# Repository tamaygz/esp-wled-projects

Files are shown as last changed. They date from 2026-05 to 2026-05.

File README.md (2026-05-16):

# esp-wled-projects

> DIY LED lighting projects powered by **WLED** on ESP32 / ESP8266 — fully integrated with Home Assistant.

This repository has two layers:

- the **meta main folder**, which contains the reusable project system
- the **project folders**, which contain individual lighting builds

The meta main folder is there to make new project creation repeatable instead of ad-hoc. It contains the shared `_template/` skeleton, Copilot agents and instructions under `.github/` and `AGENTS.md`, the parts register in [tools/parts-register/parts.json](./tools/parts-register/parts.json), shared generators in [tools/](./tools/), and the integration conventions for WLED, Home Assistant, diagrams, and enclosures. Together, those pieces are meant to help a project consumer move from idea to implementation faster: reuse known parts and pinouts, scaffold the right files, generate diagrams and enclosures consistently, and keep firmware, hardware, and Home Assistant artifacts aligned.

Each actual project folder is then a self-contained build with its own firmware config, wiring docs, power budget, 3D models, and generated diagrams.

## Meta Layer At A Glance

If you want to create a new project from this repo, the root-level meta layer is the part that helps you.

| Meta asset | What it contains | How it helps when creating a new project |
|---|---|---|
| [_template/](./_template/) | Base folder skeleton | Gives every new project the same starting structure and required files |
| [tools/parts-register/parts.json](./tools/parts-register/parts.json) | Shared parts registry | Reuses known dimensions, electrical facts, and board pinouts instead of re-researching them |
| [tools/](./tools/) | Shared generators and helpers | Produces diagrams, renders enclosures, and uploads SPIFFS assets consistently |
| [.github/instructions/](./.github/instructions/) | Scoped Copilot rules | Keeps edits to firmware, hardware, diagrams, and new-project docs aligned with repo conventions |
| [.github/prompts/](./.github/prompts/) | Reusable slash-command workflows | Speeds up scaffolding, diagram generation, and enclosure generation |
| [.github/agents/](./.github/agents/) | Planner, reviewer, and hardware-debug agents | Guides planning, real-build debugging, and final coherence checks |
| [AGENTS.md](./AGENTS.md) and [.github/copilot-instructions.md](./.github/copilot-instructions.md) | Always-on repo guidance | Explains how the meta layer is supposed to be used and what rules always apply |

### How The Meta Layer Helps

1. Start from `_template/` instead of inventing a structure from scratch.
2. Use the parts register before looking up dimensions, pinouts, or PSU data again.
3. Let the planner prompt or agent drive the first pass when requirements are still forming.
4. Generate diagrams and enclosure artifacts from shared tools so outputs stay consistent across projects.
5. Use the hardware-debug agent when a physical build fails and the fault is still unclear.
6. Run the reviewer step before considering a new project scaffold or meta change complete.

---

## Ideal Workflow — New Project

### 1 · Plan

Use the **ESP/WLED Project Planner** agent in Copilot chat, or work through these steps manually:

| Step | What to do |
|---|---|
| Concept | Decide installation type, LED run length, colour capability, sound-reactive? |
| LED strip | Pick chipset (SK6812 RGBW, WS2812B RGB, WS2811 12 V) based on colour needs and run length |
| Power budget | `N_leds × 20 mA × channels` + 20 % headroom → select PSU |
| ESP32 | ESP32-WROOM-32 for most projects; ESP32-S3 for native USB / >3 buses |
| GPIO plan | Assign data lines to GPIO 16 / 17 / 18; level shifter required (3.3 V → 5 V) |
| HA effects | Decide if [hacs-wledext-effects](https://github.com/tamaygz/hacs-wledext-effects) is needed for state-driven effects |

Start with [tools/parts-register/parts.json](./tools/parts-register/parts.json) during planning so you can reuse known board, LED strip, PSU, connector, and cutout data before searching the web again.

### 2 · Scaffold

```bash
cp -r _template/ my-project/
```

Then fill in order:

1. `specs.md` — concept, requirements, acceptance criteria, **Home Assistant** section
2. `hardware/bom/bom.md` — parts list + current budget
3. `hardware/wiring/WIRING.md` — GPIO assignments, power rails, injection points
4. `gen_diagrams_config.py` — copy from `reefs/`, update values
5. `firmware/cfg.json` — set unique mDNS hostname: `"id": {"mdns": "my-project"}`

Or use the **`/new-project`** prompt in Copilot chat to scaffold automatically.

### 2.5 · Review The Scaffold

When the scaffold or meta-layer update is in place, switch to the **ESP/WLED Project Reviewer** agent or use the planner's review handoff. The review step checks repo-instruction coherence, missing files, register-backed hardware facts, and whether user-facing docs match the current project state.

### 3 · Generate Diagrams

```bash
python tools/gen_diagrams.py my-project       # all 4 types
python tools/gen_diagrams.py my-project --type concept   # real-world views only
```

Four diagram types are produced:

| Type | Output | What it shows |
|---|---|---|
| `blocks` | `concept-system.png` | System block: PSU → ESP32 → level shifter → LED strips → HA |
| `concept` | `concept-side-view.png` · `concept-top-view.png` | Real-world: wall cross-section + floor-plan with lamp positions |
| `wiring` | `wiring-physical.svg` | Color-coded physical wiring with pin labels |
| `schematic` | `schematic-*.png` | Electrical schematics (level shifter + power) |

All outputs land in `my-project/docs/` — never hand-edit them. Or use the **`/gen-diagrams`** prompt in Copilot chat.

### 4 · Generate Enclosure

Use the **`/gen-enclosure`** prompt in Copilot chat, or run the helper directly after the SCAD is in place:

```powershell
pwsh tools/render_enclosure.ps1 -Project my-project -ScadName my-project-enclosure
```

Produces `my-project/mechanical/enclosure/`:

- `my-project-base.stl`, `my-project-lid.stl` — print-ready
- `my-project-{base,lid}-{iso,top}.png` — 4 preview PNGs, committed alongside the STLs

Lid closure defaults to **snap-on** (no screws). Source of truth: [.github/skills/enclosure-gen/SKILL.md](.github/skills/enclosure-gen/SKILL.md).

### 5 · Build & Flash

```bash
# Inside the WLED repo, with firmware/platformio_override.ini alongside platformio.ini:
pio run -e esp32dev_my-project -t upload
```

First boot → connect to `wled-ap` hotspot → configure WiFi credentials via Captive Portal.

### 6 · Connect to Home Assistant

1. Enable native WLED integration: **Settings → Devices & Services → Add → WLED**
2. Device auto-discovers via mDNS (`my-project.local`)
3. Verify light entities appear and on/off / brightness / colour work
4. (Optional) Install [hacs-wledext-effects](https://github.com/tamaygz/hacs-wledext-effects) for state-driven effects

### 7 · Export & Commit

```bash
# Export config from WLED web UI → backup
# Place files in firmware/cfg.json and design/effects/presets.json
git add .
git commit -m "feat(my-project): initial project setup"
```

---

## Project Folder Convention

```
[project]/
├── firmware/               # platformio_override.ini, cfg.json, presets.json
├── hardware/
│   ├── wiring/             # KiCad schematics, wiring notes, PDFs
│   ├── pcb/                # KiCad PCB files, Gerbers
│   └── bom/                # bom.md — parts list + power budget
├── mechanical/
│   └── enclosure/          # YAPP_Box SCAD + STLs + preview PNGs + print settings
├── design/
│   ├── led-map/            # 2D pixel maps, segment plans
│   └── effects/            # WLED presets.json, palettes, ha-automations.yaml
├── docs/                   # Auto-generated diagrams (PNG/SVG) — do not hand-edit
├── gen_diagrams.py         # Diagram script — imports from tools/diagram_gen
├── gen_diagrams_config.py  # DIAGRAM_CONFIG dict for this project
└── specs.md                # Project PRD / spec sheet
```

See [_template/](./_template/) for a ready-to-copy skeleton.

---

## AI Agent Support

This repo is configured for GitHub Copilot (VS Code Insiders) and GitHub cloud agents.

| Customization | What it does |
|---|---|
| Always-on instructions | `.github/copilot-instructions.md` — full project conventions |
| `AGENTS.md` | Root agent guidance shared across coding agents |
| `firmware.instructions.md` | Auto-loaded when editing `platformio_override.ini`, `cfg.json` |
| `hardware.instructions.md` | Auto-loaded when editing wiring / BOM / PCB files |
| `new-project.instructions.md` | Auto-loaded when editing `specs.md` or `_template/` |
| `diagram-gen.instructions.md` | Auto-loaded when editing diagram generators or `docs/` |
| `/new-project` prompt | Scaffolds a full project folder from `_template/` |
| `/gen-diagrams` prompt | Runs `tools/gen_diagrams.py` with validation |
| `/gen-enclosure` prompt | Generates YAPP_Box SCAD + renders STLs and preview PNGs |
| `ESP/WLED Project Planner` custom agent | Guided planning: requirements → LED → power → GPIO → HA → scaffold |
| `ESP/WLED Project Reviewer` custom agent | Reviews scaffold/meta coherence, upgrades docs, and checks current customization conventions |
| `ESP/WLED Realworld Hardware Debug` custom agent | Step-by-step real build triage: captures actual hardware, checks wiring/power/config assumptions, compares against project definitions, and guides the next diagnostic step |
| `enclosure-gen` skill | Reusable enclosure reference and YAPP_Box workflow support |
| `.github/hooks/README.md` | Documents the repo hook policy and recommended first deterministic hook use cases |

### How To Use The Agents

- Use **ESP/WLED Project Planner** when you are starting a new build or the requirements are still vague. Give it the project idea, LED goals, installation constraints, and Home Assistant expectations.
- Use **ESP/WLED Project Reviewer** after scaffolding or broad meta changes. It is the cleanup and coherence pass that checks missing files, instruction drift, register-backed facts, and doc completeness.
- Use **ESP/WLED Realworld Hardware Debug** when a physical setup is not working and you do not yet know whether the problem is power, wiring, GPIO choice, firmware config, part substitution, or Home Assistant. Start it with the project name and a symptom such as `reefs flickers`, `curtaincinemalights no Wi-Fi`, or `something isn't working`.
- Let the agents hand off where appropriate: planner for build definition, hardware-debug for real-world triage, reviewer for final doc and meta alignment.

### Which Doc To Read

| If you need to understand... | Read this first |
|---|---|
| what this repo is and how the meta layer helps | [README.md](./README.md) |
| how an agent should behave in this repo | [AGENTS.md](./AGENTS.md) |
| the full always-on repo conventions | [.github/copilot-instructions.md](./.github/copilot-instructions.md) |
| file-specific editing rules | [.github/instructions/](./.github/instructions/) |
| the parts register schema and sourcing rules | [tools/parts-register/README.md](./tools/parts-register/README.md) |
| hook policy and whether a hook should exist at all | [.github/hooks/README.md](./.github/hooks/README.md) |

### Working In VS Code Insiders

- Run `Chat: Open Customizations` to manage prompts, instructions, skills, agents, hooks, and plugins.
- Type `/agents`, `/prompts`, `/instructions`, `/skills`, or `/hooks` in chat for quick entry to the relevant customization UI.
- Use Chat diagnostics to inspect which customizations loaded and to catch metadata issues quickly.
- If you open only a project subfolder instead of the repo root, enable `chat.useCustomizationsInParentRepositories` so these root-level customizations are discovered.
- When an agent needs input for an important choice, it should use the VS Code structured ask-question flow with suggested options and free-form input enabled.
- Prefer planner → reviewer handoffs for guided workflows; use hooks only for deterministic automation such as validation or policy enforcement.

---

## Common Tools

| Tool | Purpose | Link |
|---|---|---|
| WLED web installer | Flash pre-built firmware | https://install.wled.me |
| WLED custom build | Online build with usermods | https://wled-compile.github.io |
| KiCad | Schematic / PCB | https://kicad.org |
| OpenSCAD | Parametric 3D models (enclosure rendering) | https://openscad.org |
| YAPP_Box v3 | Parametric box generator (shared at `tools/yapp/`) | https://github.com/mrWheel/YAPP_Box |
| PlatformIO | Build & flash from source | https://platformio.org |
| hacs-wledext-effects | State-driven HA effects | https://github.com/tamaygz/hacs-wledext-effects |
| WLED-MM (MoonModules) | Sound-reactive fork | https://github.com/MoonModules/WLED-MM |
| LedFX | PC-based audio reactive | https://ledfx.app |

---

## Resources

- [WLED Docs](https://kno.wled.ge) — official documentation
- [WLED GitHub](https://github.com/wled/WLED)
- [r/WLED](https://reddit.com/r/WLED)
- [WLED Discord](https://discord.gg/QAh7wJHrRM)
- [QuinLED](https://quinled.info) — WLED-dedicated hardware

---

## Included Projects

I built this repo mostly for myself as a structured workspace for planning, building, documenting, and reusing WLED-based lighting projects. The projects currently included are:

| Project | Status | LEDs | Controller | Description |
|---|---|---|---|---|
| [reefs](./reefs/) | wip | SK6812 RGBW 60/m × 2 | ESP32-WROOM-32 | Driftwood ambient lamps, Home Assistant integrated |
| [curtaincinemalights](./curtaincinemalights/) | wip | SK6812 RGBW 60/m, ~180 LEDs · 3 m | ESP8266 D1 Mini | Cinema curtain LED sync — center-fill mirrors curtain position, State Sync + Chase + Breathe via hacs-wledext-effects |

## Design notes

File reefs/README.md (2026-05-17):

# reefs — Driftwood Ambient Lamps

> Two driftwood wall-wash lamps powered by SK6812 RGBW strips, a shared ESP8266 NodeMCU V3/WLED controller, and a compact 3D-printed control box with Home Assistant integration.

## Concept

Each piece of driftwood is treated as its own lamp: a 1 m SK6812 RGBW strip sits in an aluminium channel on the rear face of the wood and throws diffused light onto the wall behind it. The front stays visually dark, so the shape and grain of the driftwood frame the glow rather than being lit directly.

Both lamps run back to one concealed control box. That box handles the 5 V power distribution, level-shifted data outputs, WLED configuration, and Home Assistant discovery while keeping the installation to a single mains lead and two lamp cable runs.

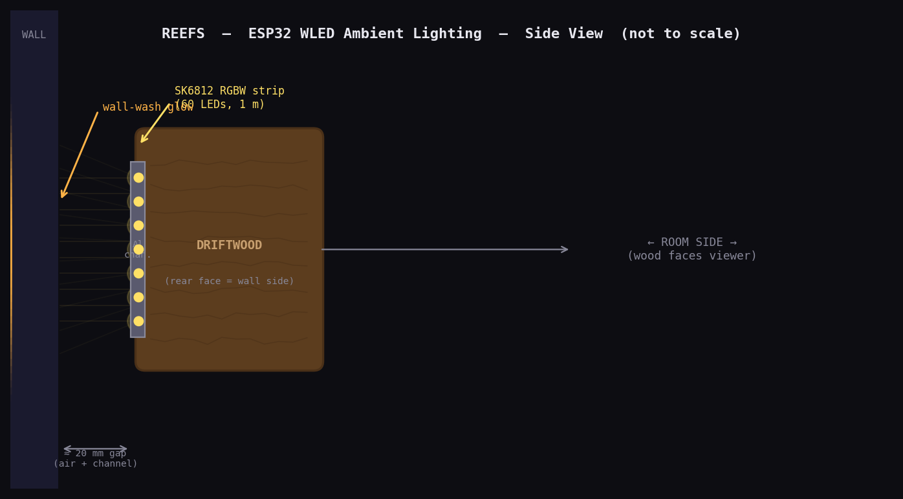
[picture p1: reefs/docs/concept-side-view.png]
Side-view cross-section


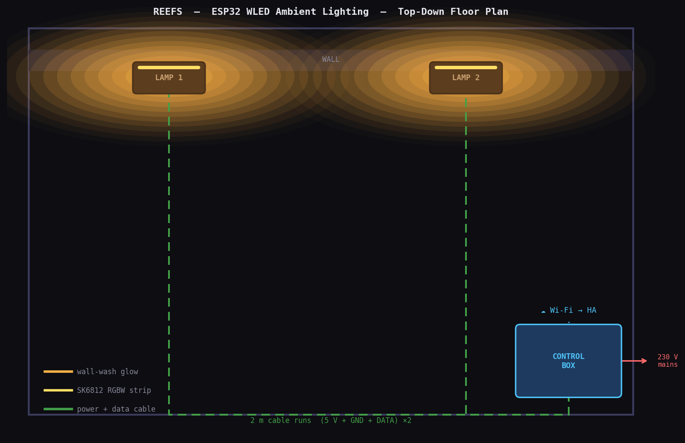
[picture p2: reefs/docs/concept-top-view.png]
Top-down floor plan


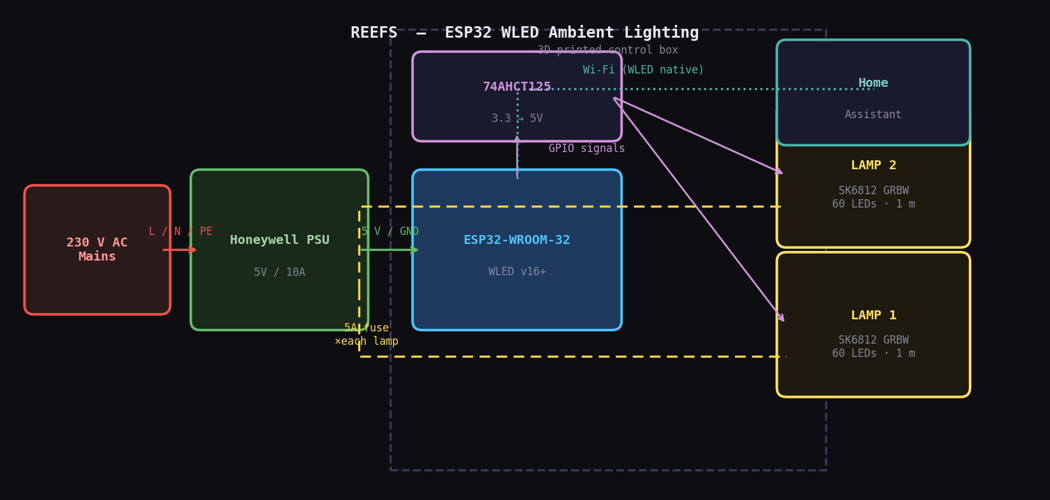
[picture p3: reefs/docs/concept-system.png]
System block diagram


---

## Quick Facts

| Property | Value |
|---|---|
| Board | ESP8266 NodeMCU V3 (LoLin/Wemos-style) |
| LED Type | SK6812 RGBW, 5 V, 60 LED/m, GRBW |
| LED Count | 120 total (60 per lamp × 2) |
| Power Supply | Honeywell 5 V / 10 A external PSU |
| WLED Version | v0.15 (ESP8266 branch) |
| Smart home | Home Assistant native WLED integration |
| Outputs | D5/GPIO14 → Lamp 1, D6/GPIO12 → Lamp 2 via 74AHCT125 |
| Enclosure | 3D-printed PETG / ASA control box, snap-on lid |

---

## Key Components / Parts Snapshot

| PART_ID | Role | Register-backed facts | Source / Pinout |
|---|---|---|---|
| `ESP8266_NODEMCU_V3` | Reference controller board | `nodemcuv2` PlatformIO target; recommended LED pins are D5/GPIO14 and D6/GPIO12; UNVERIFIED clone-derived geometry so confirm your board's size and USB position before enclosure edits | [Board page](https://www.nodemcu.com/index_en.html) |
| `SK6812_RGBW_60` | LED emitters | 10 mm strip width; GRBW colour order; inject power every ≤ 50 LEDs on longer runs | [Datasheet](https://cdn-shop.adafruit.com/product-files/1138/SK6812+LED+datasheet+.pdf) |
| `AL_LED_CHANNEL_12MM` | Heat-spreading channel | 12.3 mm inner width; 17.4 × 7.6 mm outer profile; helps move heat away from wood and diffuser | [Profile reference](https://www.superlightingled.com/light-diffuser-aluminum-led-profile-for-12mm-flexible-led-strip-lights-p-4554.html) |
| `IC_74AHCT125_DIP14` | Data level shifter | 5 V supply; TTL-compatible inputs accept 3.3 V logic; quad buffer lets one gate drive each lamp output | [TI datasheet](https://www.ti.com/product/SN74AHCT125) |
| `JST_SM_2P5_3PIN` | Lamp connector interface | 3 A/contact; 9.5 × 6 mm panel pocket; common prewired connector format for addressable LED strips | [Series reference](https://www.jst-mfg.com/product/pdf/eng/eSM.pdf) |

The Honeywell PSU used here is project-specific and is not yet represented in the shared parts register.

---

## Documentation Index

| Document | What's inside |
|---|---|
| [specs.md](specs.md) | Full PRD: concept, requirements, power budget, WLED config, HA integration |
| [hardware/bom/bom.md](hardware/bom/bom.md) | Bill of materials, current budget, voltage-drop notes |
| [hardware/wiring/WIRING.md](hardware/wiring/WIRING.md) | GPIO assignments, control-box wiring, connector strategy |
| [design/led-map/LED-DESIGN.md](design/led-map/LED-DESIGN.md) | Segment plan, preset design, colour strategy |
| [design/effects/ha-automations.yaml](design/effects/ha-automations.yaml) | Home Assistant automation examples |
| [mechanical/enclosure/MODELS.md](mechanical/enclosure/MODELS.md) | Print settings, enclosure notes, cutout details |
| [mechanical/enclosure/reefs-automatedvariant-enclosure.scad](mechanical/enclosure/reefs-automatedvariant-enclosure.scad) | Current enclosure source |
| [firmware/platformio_override.ini](firmware/platformio_override.ini) | WLED build config |
| [firmware/cfg.json](firmware/cfg.json) | WLED runtime config |
| [firmware/presets.json](firmware/presets.json) | Exported WLED presets |
| [firmware/spiffs/ha-import.html](firmware/spiffs/ha-import.html) | Device-served HA import assistant |
| [homeassistant/README.md](homeassistant/README.md) | HA import methods and entity ID guidance |
| [homeassistant/package.yaml](homeassistant/package.yaml) | HA package with helpers, scripts, and automations |
| [homeassistant/lovelace.yaml](homeassistant/lovelace.yaml) | Ready-made dashboard card |

---

## Wiring & Schematics

Physical wiring

See [hardware/wiring/WIRING.md](hardware/wiring/WIRING.md) for the full GPIO table, current-limited connector notes, and control-box wiring details.

| Level-shifter circuit | Power distribution |
|---|---|
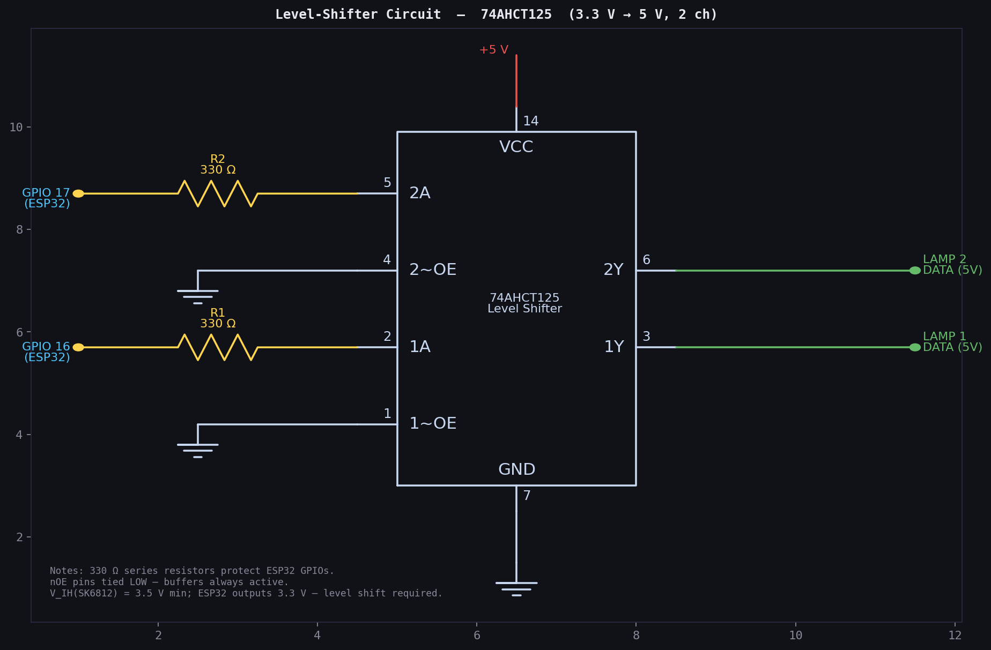
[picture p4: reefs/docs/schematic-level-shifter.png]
Level-shifter schematic
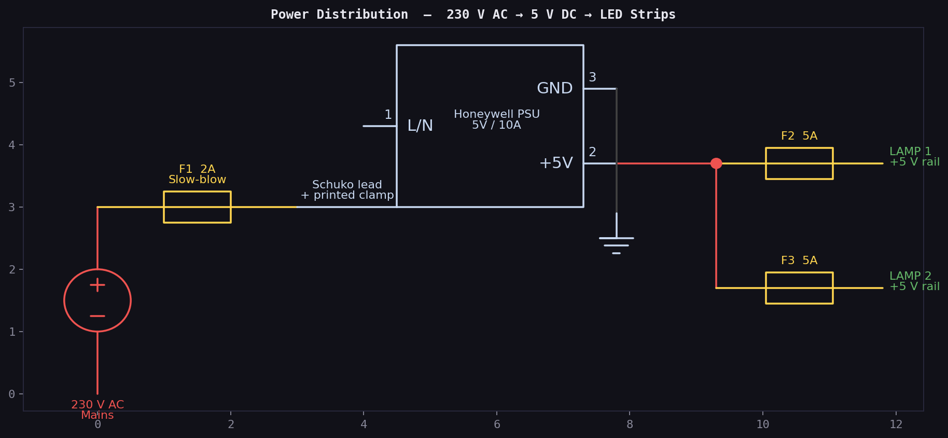
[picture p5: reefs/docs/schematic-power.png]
Power schematic
|  |  |

---

## Enclosure

The current enclosure source is [mechanical/enclosure/reefs-automatedvariant-enclosure.scad](mechanical/enclosure/reefs-automatedvariant-enclosure.scad). The generated build uses a captive Schuko mains lead, a front USB access slot, and JST SM lamp-output pockets rather than the older IEC / cable-gland concept.

| Base shell | Lid |
|---|---|
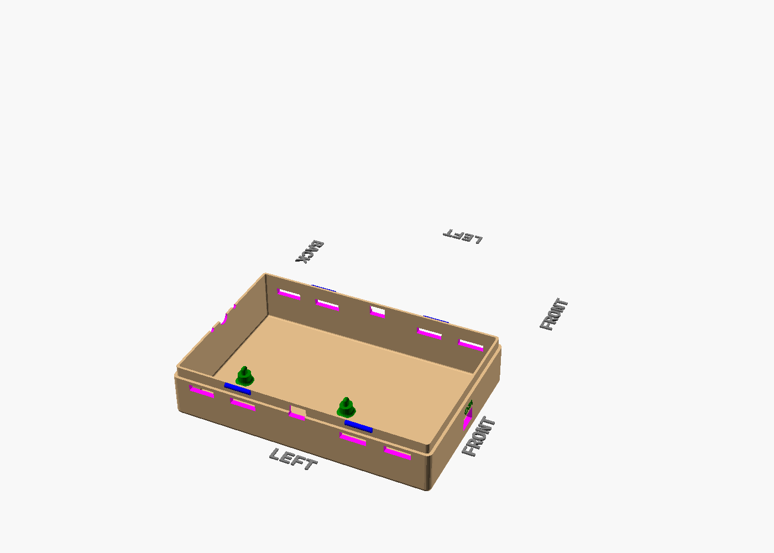
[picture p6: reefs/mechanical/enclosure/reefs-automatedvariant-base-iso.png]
Base iso
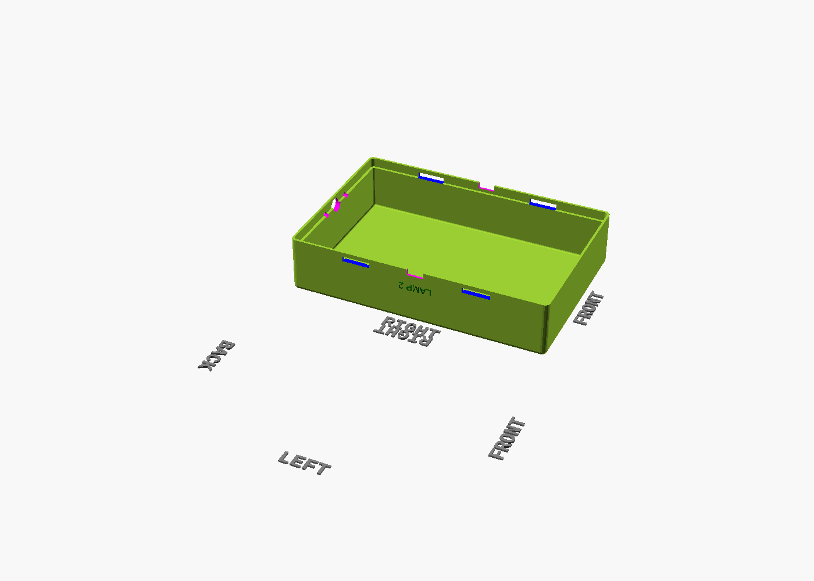
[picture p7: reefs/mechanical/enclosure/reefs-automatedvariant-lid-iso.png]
Lid iso
|  |  |

Re-render with `pwsh tools/render_enclosure.ps1 -Project reefs -ScadName reefs-automatedvariant-enclosure`.

---

## Build Checklist

- [ ] Flash WLED ESP8266 build to the NodeMCU V3 and verify Wi-Fi join
- [ ] Bench-test one SK6812 strip on D5/GPIO14 through the level shifter
- [ ] Bench-test both outputs on D5/GPIO14 + D6/GPIO12 with 60 LEDs each
- [ ] Mount aluminium channels on the driftwood rear faces
- [ ] Print the current enclosure variant and verify cable-entry fit
- [ ] Assemble control box: PSU, controller, level shifter, fuses, JST outputs
- [ ] Configure WLED: 2 outputs, 60 LEDs each, SK6812 GRBW, boot preset
- [ ] Upload `ha-import.html` and verify Home Assistant discovery
- [ ] Add WLED integration in Home Assistant and verify both lamp entities
- [ ] Perform 60-minute thermal soak at 50 % brightness

---

## Resources

- [specs.md](specs.md) — full project spec
- [homeassistant/README.md](homeassistant/README.md) — Home Assistant import guide
- [tools/parts-register/parts.json](../tools/parts-register/parts.json) — shared part facts used across the repo
- [WLED Docs](https://kno.wled.ge)
- [WLED GitHub](https://github.com/wled/WLED)

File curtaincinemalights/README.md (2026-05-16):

# curtaincinemalights — Cinema Curtain LED Sync

> A single SK6812 RGBW strip hidden in a curtain-rail channel mirrors the open and close position of a motorized cinema curtain, driven by WLED and Home Assistant state-based effects.

## Concept

This project hides one 5 V SK6812 RGBW strip behind a red cinema curtain so the LEDs illuminate the wall-gap between fabric and wall rather than the room directly. The lit zone starts at the center and spreads outward to match the two-panel curtain motion in real time.

The whole effect is built around one ESP8266 D1 Mini running WLED, a compact AC-DC supply inside a printed enclosure, and Home Assistant orchestration through `hacs-wledext-effects` for State Sync, Chase, and Breathe behaviors.

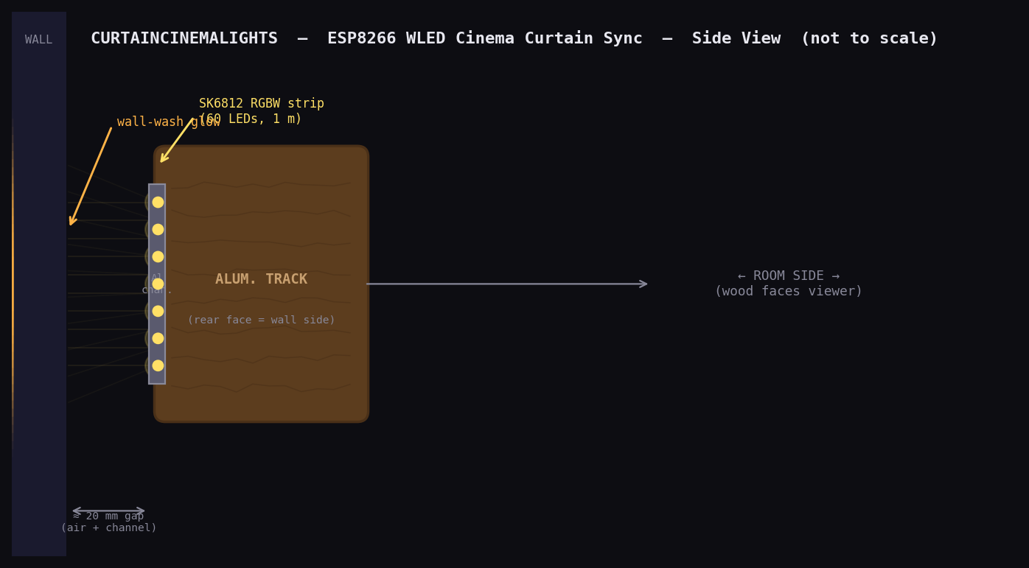
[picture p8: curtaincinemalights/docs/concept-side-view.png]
Side view


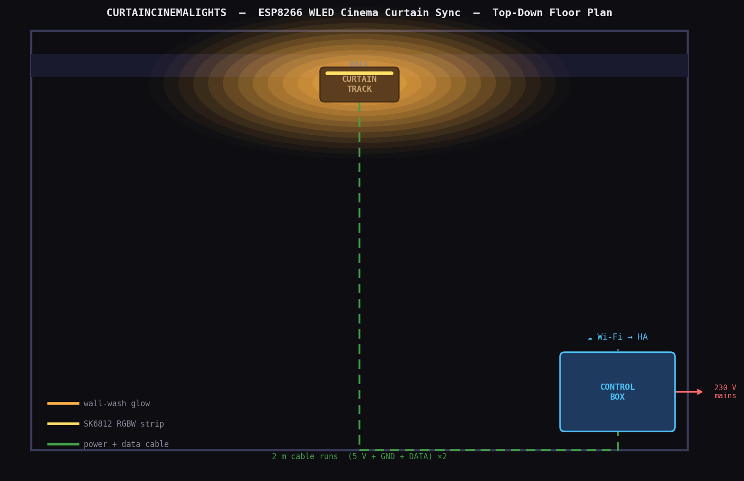
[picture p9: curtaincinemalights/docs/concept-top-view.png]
Top view


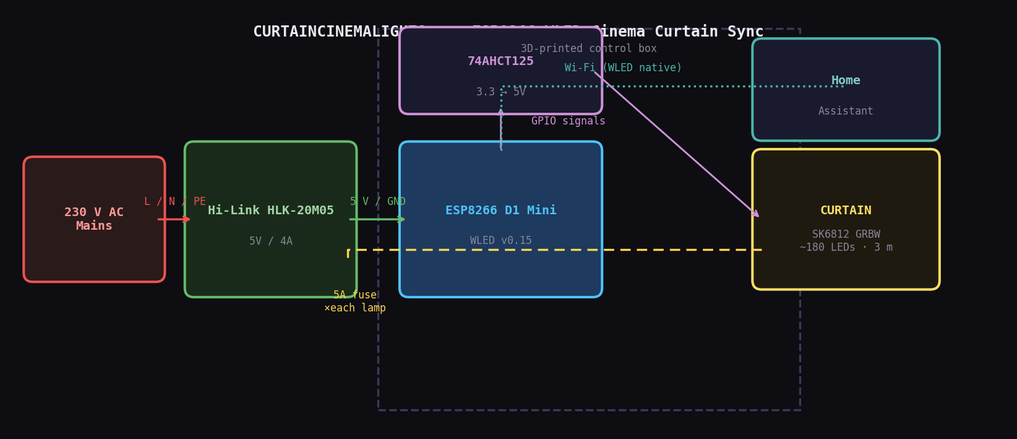
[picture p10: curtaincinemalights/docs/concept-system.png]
System blocks


---

## Quick Facts

| Property | Value |
|---|---|
| Controller | ESP8266 LOLIN D1 Mini v4 |
| WLED version | v0.15 (ESP8266 branch) |
| LED strip | SK6812 RGBW 60 LED/m, 5 V, GRBW |
| Default LED count | 180 LEDs (3 m), adjustable in WLED UI |
| Output pin | GPIO2 (D4) via 74AHCT125 |
| PSU | Hi-Link HLK-20M05, 5 V / 4 A |
| WLED ABL limit | 3200 mA |
| Segments | Left Panel (0–89, reversed) + Right Panel (90–179) |
| HA mDNS hostname | `curtaincinemalights.local` |
| HA master entity | `light.curtaincinemalights` |
| Context effects | State Sync, Chase, Breathe, Rainbow Wave |
| Enclosure | 3D-printed YAPP_Box, ~106 × 46 × 44 mm, snap-on lid |

---

## Key Components / Parts Snapshot

| PART_ID | Role | Register-backed facts | Source / Pinout |
|---|---|---|---|
| `D1_MINI_V4` | Controller board | 34.2 × 25.6 × 10 mm body; USB-C port cutout guidance in register; no mounting holes so enclosure uses a friction-fit pocket | [Board page](https://www.wemos.cc/en/latest/d1/d1_mini.html) |
| `HLK_20M05` | AC-DC supply | 56 × 32 × 22.5 mm body; 85–264 Vac input; 5 V / 4 A output | [LCSC listing](https://lcsc.com/product-detail/Power-Modules_HI-LINK-HLK-20M05_C465406.html) |
| `SK6812_RGBW_60` | LED strip | 10 mm strip width; GRBW colour order; power injection recommended every ≤ 50 LEDs | [Datasheet](https://cdn-shop.adafruit.com/product-files/1138/SK6812+LED+datasheet+.pdf) |
| `AL_LED_CHANNEL_12MM` | Aluminium channel | 12.3 mm inner width; 17.4 × 7.6 mm outer profile; works as both diffuser carrier and heat spreader | [Profile reference](https://www.superlightingled.com/light-diffuser-aluminum-led-profile-for-12mm-flexible-led-strip-lights-p-4554.html) |
| `IC_74AHCT125_DIP14` | Data level shifter | 5 V TTL-compatible buffer; DIP-14 package; one gate used to raise ESP8266 data to 5 V logic | [TI datasheet](https://www.ti.com/product/SN74AHCT125) |
| `JST_SM_2P5_3PIN` | Strip connector | 3 A/contact; 9.5 × 6 mm wall pocket; common LED-strip connector format | [Series reference](https://www.jst-mfg.com/product/pdf/eng/eSM.pdf) |

---

## Documentation Index

| Document | What's inside |
|-----|---|
| [specs.md](specs.md) | Full project spec, requirements, acceptance criteria, HA integration plan |
| [hardware/bom/bom.md](hardware/bom/bom.md) | Bill of materials, power budget, connector strategy |
| [hardware/wiring/WIRING.md](hardware/wiring/WIRING.md) | Wiring guide, pin allocation, 74AHCT125 pinout |
| [design/led-map/LED-DESIGN.md](design/led-map/LED-DESIGN.md) | Segment layout, curtain-position to LED mapping |
| [design/effects/ha-automations.yaml](design/effects/ha-automations.yaml) | Home Assistant template sensor, helpers, and automations |
| [mechanical/enclosure/MODELS.md](mechanical/enclosure/MODELS.md) | Enclosure print specs, file list, re-render command |
| [mechanical/enclosure/curtaincinemalights-enclosure.scad](mechanical/enclosure/curtaincinemalights-enclosure.scad) | Current enclosure source |
| [firmware/cfg.json](firmware/cfg.json) | WLED config: device name, segments, GPIO, ABL |
| [firmware/platformio_override.ini](firmware/platformio_override.ini) | PlatformIO build override for ESP8266 D1 Mini |
| [firmware/presets.json](firmware/presets.json) | WLED presets |
| [firmware/spiffs/ha-import.html](firmware/spiffs/ha-import.html) | Device-served HA import assistant |
| [homeassistant/README.md](homeassistant/README.md) | Home Assistant import guide |
| [homeassistant/package.yaml](homeassistant/package.yaml) | HA package with helpers, scripts, and automations |
| [homeassistant/lovelace.yaml](homeassistant/lovelace.yaml) | Ready-made dashboard card |

---

## Wiring & Schematics

Physical wiring

See [hardware/wiring/WIRING.md](hardware/wiring/WIRING.md) for GPIO allocation, midpoint power injection, and 74AHCT125 wiring details.

| Level Shifter | Power Supply |
|:---:|:---:|
| Level shifter schematic | Power schematic |

---

## Enclosure

The enclosure source is [mechanical/enclosure/curtaincinemalights-enclosure.scad](mechanical/enclosure/curtaincinemalights-enclosure.scad). It packages the HLK-20M05, D1 Mini, fuse, and connector routing into a compact YAPP_Box-style shell sized for shelf or curtain-alcove installation.

| Base shell | Lid |
|:---:|:---:|
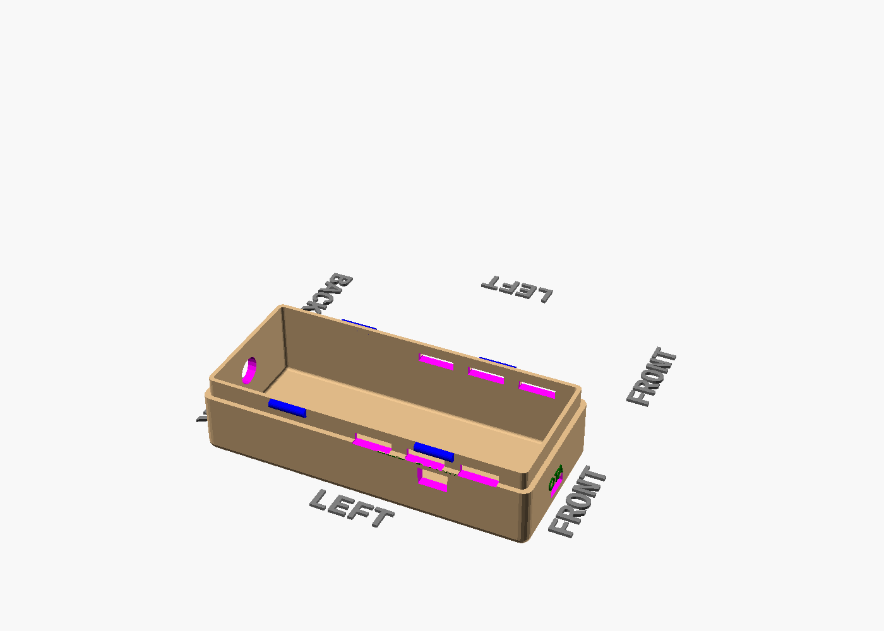
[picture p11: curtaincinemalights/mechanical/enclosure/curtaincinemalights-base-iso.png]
Base iso
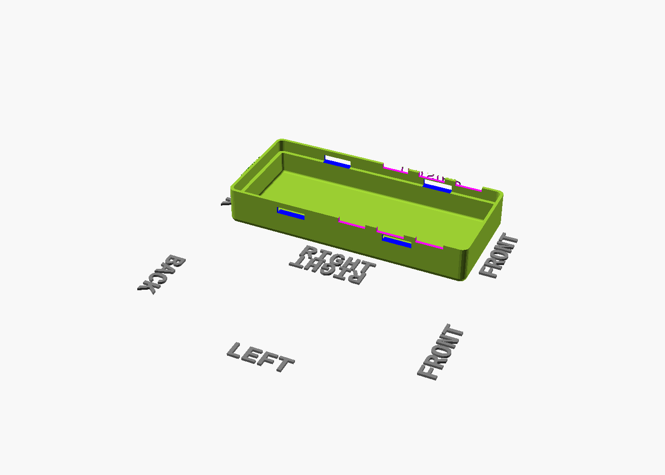
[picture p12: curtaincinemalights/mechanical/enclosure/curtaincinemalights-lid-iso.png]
Lid iso
|  |  |

Re-render: `pwsh tools/render_enclosure.ps1 -Project curtaincinemalights -ScadName curtaincinemalights-enclosure`

---

## Build Checklist

- [ ] Measure exact curtain width and set final LED count / segment split
- [ ] Flash WLED v0.15 to the D1 Mini and verify captive portal setup
- [ ] Bench-test GPIO2 through the 74AHCT125 into a short SK6812 segment
- [ ] Cut and mount the aluminium channel on the curtain-rail brackets
- [ ] Wire start and midpoint power injection for the final strip length
- [ ] Print the enclosure and verify HLK-20M05 + D1 Mini fit
- [ ] Upload `cfg.json`, `presets.json`, and `ha-import.html`
- [ ] Verify Home Assistant discovery and import the package / blueprints
- [ ] Configure State Sync, Chase, Breathe, and Rainbow Wave instances
- [ ] Test opening, closing, cinema mode, and thermal behavior

---

## Adjusting for Your Curtain Width

| Width | LED count | Segment split | WLED setting |
|---|---|---|---|
| 2.0 m | 120 | 0–59 + 60–119 | Change total LEDs and segment stops in WLED UI |
| 2.5 m | 150 | 0–74 + 75–149 | Same pattern |
| 3.0 m (default) | 180 | 0–89 + 90–179 | Default config |
| 4.0 m | 240 | 0–119 + 120–239 | Same pattern |

---

## Resources

- [specs.md](specs.md) — full project spec
- [homeassistant/README.md](homeassistant/README.md) — Home Assistant import guide
- [tools/parts-register/parts.json](../tools/parts-register/parts.json) — shared part facts used across the repo
- [WLED Docs](https://kno.wled.ge)
- [WLED GitHub](https://github.com/wled/WLED)

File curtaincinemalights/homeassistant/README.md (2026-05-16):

# Home Assistant — Curtain Cinema Lights

This folder contains all Home Assistant configuration artifacts for the `curtaincinemalights` project.
Use **one of the methods** below to import automations, helpers, and dashboard cards into your HA instance.

---

## What's included

| File | Purpose |
|---|---|
| `package.yaml` | HA Package: template sensor, helpers, scripts, and all 8 automations |
| `blueprints/curtaincinemalights-curtain-sync.yaml` | Sync LED effects to curtain open/close state |
| `blueprints/curtaincinemalights-cinema-mode.yaml` | Switch to cinema Breathe when projector plays |
| `lovelace.yaml` | Ready-made dashboard card (light controls, preset selector, curtain gauge) |

The automations also exist as raw YAML in [`design/effects/ha-automations.yaml`](../design/effects/ha-automations.yaml) for reference.

---

## Prerequisites

Before importing:

1. **WLED device discovered** — ensure `curtaincinemalights.local` is reachable and the WLED integration is added in HA (Settings → Devices & Services → Add → WLED).
2. **hacs-wledext-effects installed** — add `https://github.com/tamaygz/hacs-wledext-effects` as a HACS custom repo (category: Integration), install "WLED Effects", restart HA, then add the integration and configure:
   - `ccl_left_state_sync` — State Sync, Left Panel, source: `sensor.cinema_curtain_position`
   - `ccl_right_state_sync` — State Sync, Right Panel, source: `sensor.cinema_curtain_position`
   - `ccl_chase_left` — Chase, Left Panel
   - `ccl_chase_right` — Chase, Right Panel
   - `ccl_ambient_rainbow` — Rainbow Wave, master
   - `ccl_cinema_breathe` — Breathe, master (dim red)
3. **Template sensor created** — add the `template:` block from `package.yaml` to `configuration.yaml`, or create via Settings → Helpers → Template Sensor.

---

## Method 1 — Device Import Assistant (recommended)

After flashing firmware + filesystem:

1. Open `http://curtaincinemalights.local/ha-import.html` in your browser (on the same network as the device)
2. The page reads your WLED device config and shows the exact HA entity IDs
3. Click **Import in HA** to open each blueprint directly in your HA instance
4. Click **Download package.yaml** to get a pre-filled package file with entity IDs substituted

---

## Method 2 — Blueprint import via HA UI

Click each badge to open the blueprint importer directly in your Home Assistant:

**Curtain Sync** — sync LED fill and chase effects to cover entity state:



**Cinema Mode** — switch to dim red Breathe when projector plays:



After import, HA will ask you to pick entity IDs in the automation editor UI — no YAML editing needed.

---

## Method 3 — HA Package (manual copy)

1. Copy `package.yaml` to `<ha-config>/packages/curtaincinemalights.yaml`
2. Ensure `configuration.yaml` contains:
   ```yaml
   homeassistant:
     packages: !include_dir_named packages
   ```
3. Edit the substitution block at the top of `package.yaml`:
   - `[MASTER_LIGHT]` → `light.curtaincinemalights`
   - `[SEGMENT_1]` → `light.curtaincinemalights_left_panel`
   - `[SEGMENT_2]` → `light.curtaincinemalights_right_panel`
   - `cover.cinema_curtain` → your actual curtain cover entity
   - `media_player.projector` → your actual projector/TV entity
4. Restart Home Assistant

---

## Method 4 — Lovelace dashboard card

1. In HA, open your dashboard → Edit → Add Card → Manual
2. Paste the contents of `lovelace.yaml`
3. Adjust entity IDs (`light.curtaincinemalights`, `light.curtaincinemalights_left_panel`, etc.) to match your instance
4. Save

---

## Entity IDs reference

| Entity | Expected ID | Notes |
|---|---|---|
| Master light | `light.curtaincinemalights` | Controls all 180 LEDs |
| Left Panel | `light.curtaincinemalights_left_panel` | LEDs 0–89, reversed |
| Right Panel | `light.curtaincinemalights_right_panel` | LEDs 90–179 |
| Curtain position sensor | `sensor.cinema_curtain_position` | Template sensor, 0–100 % |
| Cinema mode toggle | `input_boolean.cinema_mode_active` | Created by package.yaml |
| Preset selector | `select.curtaincinemalights_preset` | Auto-created by WLED integration |

Verify all IDs in HA: Settings → Devices & Services → WLED → Curtain Cinema Lights.

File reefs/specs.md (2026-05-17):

# PRD: Reefs — WLED Driftwood Ambient Lighting

- **Version**: 1.0  
- **Date**: 2026-05-16  
- **Status**: Draft — awaiting owner review

---

## 1. Product Overview

### 1.1 Document Title and Version

- PRD: Reefs — WLED Driftwood Ambient Lighting
- Version: 1.0

### 1.2 Product Summary

**Reefs** is a DIY ambient lighting installation built around two pieces of natural driftwood. Each piece of driftwood acts as a self-contained lamp: an SK6812 RGBW LED strip is mounted on the back face of the wood (facing the wall), casting diffused, coloured light onto the wall behind it. The room-facing side of each piece remains unlit, framing the glow naturally through the wood grain and texture.

Both lamps are powered and controlled from a single 3D-printed control box housing an ESP8266 NodeMCU V3 running WLED and a Honeywell 5 V PSU. WLED exposes each lamp as an independent segment — or optionally a dedicated channel — and integrates with Home Assistant via the native WLED integration, enabling scene-level control and automations.

The project is intended as a permanent room installation with no exposed wiring, a single mains connection, and full smart-home integration out of the box.

### 1.3 Executive Summary

| | |
|---|---|
| **Problem Statement** | Standard ambient lamps offer no physical texture or organic character; smart LED solutions typically require bulky off-the-shelf fixtures that cannot be adapted to natural materials. |
| **Proposed Solution** | Mount RGBW LED strips on the rear face of two driftwood pieces, fed from one centralised NodeMCU/WLED control box, producing wall-wash ambient light that is individually controllable from Home Assistant. |
| **Success Criteria** | (1) Both lamps respond to WLED commands within 200 ms over Wi-Fi. (2) Each lamp is independently controllable as a Home Assistant light entity. (3) Full-white output at 50 % brightness draws ≤ 4 A total from the PSU. (4) All wiring is concealed inside channels, conduit, or the driftwood profile. (5) The control box fits within a 150 × 100 × 60 mm 3D-printed enclosure. |

---

## 2. Goals

### 2.1 Project Goals

- Deliver two functional ambient lamps with distinct, independently addressable WLED segments.
- Centralise power and control in one enclosure with a single mains input.
- Achieve full Home Assistant integration so both lamps appear as individual light entities.
- Produce a repeatable, documented build that can be reproduced or extended.

### 2.2 Owner Goals

- Individual brightness and colour/white control per lamp.
- Integration with Home Assistant automations (e.g., sunset scene, movie mode).
- Reliable operation at ambient brightness levels (20–60 % typical) with no flicker.
- Clean, furniture-grade finish — no visible wiring between driftwood and control box.

### 2.3 Non-Goals

- Audio-reactive features (not in scope for v1).
- Battery / portable operation.
- More than two lamp segments per control box in this revision.
- Mobile app beyond WLED's built-in web UI and HA integration.
- Any mains-side electrical work beyond plugging in the PSU (handled separately / by qualified person).

---

## 3. User Personas

### 3.1 Key User Types

- **Builder / Maker** — assembles the hardware, flashes WLED, configures HA.
- **Resident / Daily User** — operates lamps via HA dashboard, voice, or automations.

### 3.2 Persona Details

- **Builder**: Comfortable with soldering, ESP8266/ESP32 toolchains, and basic 3D printing. Needs precise wiring specs, pin assignments, and WLED config values — not guesswork.
- **Resident**: Wants one-tap scene activation, consistent behaviour, and no maintenance. Does not interact with WLED UI directly after initial setup.

### 3.3 Role-Based Access

| Role | Access Level |
|---|---|
| Builder | Full WLED web UI, OTA flashing, physical enclosure access |
| Resident | Home Assistant only — light entities, scenes, automations |

---

## 4. Functional Requirements

### 4.1 Lamp Control

**Priority: High**

- `GH-001`: As a resident, I want to turn Lamp 1 and Lamp 2 on/off independently via Home Assistant so that I can use each lamp in separate scenes.
  - **AC**: Each lamp maps to exactly one HA light entity; toggling one does not affect the other.
- `GH-002`: As a resident, I want to set brightness (1–100 %) and colour temperature (warm white ↔ cool white) per lamp so that I can adapt the mood to the time of day.
  - **AC**: Brightness changes are visible within 200 ms; colour temperature range spans at least 2700 K–6500 K via SK6812 RGBW white channel blending.
- `GH-003`: As a resident, I want to apply WLED effects (e.g., slow colour breathe, fire, candlelight) per lamp independently so that lamps can display different effects simultaneously.
  - **AC**: Any of the standard WLED effect presets can be applied to Lamp 1 without changing Lamp 2's current preset.

### 4.2 Home Assistant Integration

**Priority: High**

- `GH-004`: As a builder, I want WLED to auto-discover in Home Assistant via the native WLED integration so that no manual YAML configuration is required.
  - **AC**: Both lamps appear as separate HA entities within 60 s of WLED booting on the local network, with no manual YAML.
- `GH-005`: As a resident, I want a "Reef Scene" HA script that activates a slow-shifting warm colour preset on both lamps simultaneously so that one tap sets the room ambience.
  - **AC**: The scene sets both lamps to the designated preset within 500 ms.

### 4.3 Power & Safety

**Priority: High**

- `GH-006`: As a builder, I want the PSU to remain below 80 % rated load at maximum typical brightness so that there is thermal headroom for continuous operation.
  - **AC**: Calculated peak draw (see §8 Power Budget) ≤ 80 % of PSU rated current at 5 V.
- `GH-007`: As a builder, I want a 5 A blade fuse inline on each 5 V power run to the strips so that a wiring fault cannot damage the PSU or start a fire.
  - **AC**: Each lamp's power feed has a dedicated inline fuse rated ≤ 5 A before the first LED.

### 4.4 Physical Build

**Priority: High**

- `GH-008`: As a builder, I want the LED strip to be mounted on the rear face of the driftwood using aluminium channel / diffuser profile so that heat is conducted away from the wood and the light is diffused evenly.
  - **AC**: Strip operating temperature at 50 % brightness ≤ 45 °C measured on the strip backing after 60 min continuous operation.
- `GH-009`: As a builder, I want all inter-device wiring to run inside 10 mm cable management channels or behind baseboard so that no loose wires are visible in the finished installation.
  - **AC**: Zero exposed wire segments visible from the room-facing side of either lamp or the floor.

---

## 5. User Experience & Functionality

### 5.1 First-Time Setup Flow

1. Flash the ESP8266 WLED build to the NodeMCU V3 via USB before enclosure assembly.
2. Connect the NodeMCU to home Wi-Fi via WLED's captive portal (AP mode on first boot).
3. In WLED web UI, configure two LED outputs (D5 / GPIO14 → Lamp 1, D6 / GPIO12 → Lamp 2) with correct LED count and SK6812 type.
4. Install WLED integration in Home Assistant → auto-discovers both segments as light entities.
5. Assign entities to a room; create "Reef Scene" script.
6. Power-cycle test: both lamps illuminate to startup preset within 3 s.

### 5.2 Day-to-Day Operation

- **Standard use**: Resident taps HA dashboard tile or scene button; lamps respond within 200 ms.
- **Automation**: Lamps activate at sunset to warm preset; dim to 10 % at 23:00; turn off at 00:00.
- **Effect switching**: Resident can pick any WLED preset from HA's light card effects list.

### 5.3 Edge Cases

| Scenario | Expected Behaviour |
|---|---|
| Wi-Fi drops | WLED keeps current state; reconnects automatically; HA shows "unavailable" until reconnect |
| Power cycle | WLED restores last known state from flash within 3 s |
| One lamp data wire disconnected | That segment shows error in WLED UI; other lamp unaffected |
| PSU overload (unlikely) | Inline fuse blows; only one lamp affected if fuses per-lamp |

### 5.4 Physical UX Notes

- No physical buttons required for v1 (HA + WLED web UI sufficient).
- Control box mounts in a concealed location (shelf interior, behind furniture) — not a decorative item.
- The NodeMCU USB service port must remain accessible through the enclosure wall for OTA recovery.

---

## 6. Narrative

A homeowner powers on their living room at dusk. Home Assistant triggers the "Reef Scene" — both driftwood pieces begin emitting a slow warm amber glow from their rear faces, painting the wall behind them with organic pools of light filtered through the wood texture. Each lamp is an independent entity: one shifts to a gentle blue-white for reading while the other holds a warm flicker for ambience. All of this runs from a single small 3D-printed box tucked behind a shelf, fed by one mains lead, requiring zero maintenance beyond occasional OTA firmware updates pushed from Home Assistant.

---

## 7. Success Metrics

### 7.1 Build Quality Metrics

| Metric | Target |
|---|---|
| WLED command-to-lamp latency | ≤ 200 ms (LAN, measured with WLED HTTP API) |
| HA entity discovery time | ≤ 60 s from WLED boot |
| Strip operating temperature at 50 % brightness | ≤ 45 °C after 60 min |
| Total PSU draw at full white, 100 % brightness | ≤ rated PSU current × 80 % |
| Visible exposed wiring | 0 segments |

### 7.2 Reliability Metrics

| Metric | Target |
|---|---|
| WLED uptime between reboots | ≥ 30 days (no watchdog resets) |
| Wi-Fi reconnect after router restart | ≤ 30 s |
| State restore after power cut | Correct last-state within 3 s |

---

## 8. Technical Specifications

### 8.1 System Architecture

```
MAINS (230 V AC)
       │
       ▼
┌─────────────────────────────────────────────────┐
│               CONTROL BOX (3D-printed)          │
│                                                 │
│  ┌───────────────────┐   ┌───────────────────┐  │
│  │  Honeywell 5 V    │   │  ESP8266 NodeMCU  │  │
│  │  PSU              │──▶│     (WLED)        │  │
│  │  (≥ 10 A / 50 W)  │5V │                   │  │
│  └────────┬──────────┘   │  D5/GPIO14 ─[330Ω]┼──┼──▶ DATA Lamp 1
│           │              │  D6/GPIO12 ─[330Ω]┼──┼──▶ DATA Lamp 2
│           │5V/GND        │                   │  │
│           ├──[5A fuse]───┼───────────────────┼──┼──▶ 5V/GND Lamp 1
│           └──[5A fuse]───┼───────────────────┼──┼──▶ 5V/GND Lamp 2
│                          └───────────────────┘  │
│  [ Micro-USB port accessible on enclosure wall ]│
└─────────────────────────────────────────────────┘
          │                         │
    2 m run                   2 m run
    18 AWG (5V, GND)          18 AWG (5V, GND)
    26 AWG (DATA)             26 AWG (DATA)
          │                         │
          ▼                         ▼
  ┌───────────────┐         ┌───────────────┐
  │  DRIFTWOOD    │         │  DRIFTWOOD    │
  │  Lamp 1       │         │  Lamp 2       │
  │               │         │               │
  │  [aluminium   │         │  [aluminium   │
  │   LED channel]│         │   LED channel]│
  │  SK6812 RGBW  │         │  SK6812 RGBW  │
  │  strip (rear) │         │  strip (rear) │
  └───────────────┘         └───────────────┘
       wall-wash                  wall-wash
       (wall side)                (wall side)
```

### 8.2 Bill of Materials

| # | Component | Spec | Qty | Notes |
|---|---|---|---|---|
| 1 | SK6812 RGBW LED strip | 5 V, 60 LED/m, IP30, 4-pin | 2 × **1 m** (60 LEDs each) | Order 1.1 m per lamp to allow for trimming to fit |
| 2 | ESP8266 NodeMCU V3 board | LoLin/Wemos-style NodeMCU V3 reference | 1 | Use `ESP8266_NODEMCU_V3` as the reference board entry for pinout and enclosure planning. UNVERIFIED — confirm your board size and Micro-USB position before changing printed geometry |
| 3 | Honeywell 5 V PSU | 5 V DC, ≥ 10 A (50 W) | 1 | User-specified; verify actual model current rating |
| 4 | Aluminium LED channel | U-profile with diffuser, 12 mm wide, ≥ strip length | 2 | e.g., LUMINES Type-Z or equivalent; conduct heat away from wood |
| 5 | 3-conductor cable | 18 AWG (power) + 26 AWG (data) **or** 3-core 20 AWG flex | 2 × 2.5 m | Adds 0.5 m slack; one cable per lamp |
| 6 | 330 Ω resistor | 1/4 W, through-hole | 2 | On data line at the NodeMCU GPIO; reduces signal ringing |
| 7 | 74AHCT125 level shifter | SO-14 or DIP-14 | 1 | 3.3 V → 5 V for SK6812 data; 2 channels used |
| 8 | Blade fuse holder (inline) | 5 × 20 mm, panel or wire mount | 2 | One per lamp 5 V power run |
| 9 | 5 A blade fuse | 5 × 20 mm slow-blow | 4 | 2 installed + 2 spare |
| 10 | JST SM 3-pin connectors (M+F pair) | 2.5 mm pitch, 3 A rated | 2 pairs | **Female panel-mounted** in box wall pocket; male plug on lamp cable end |
| 11 | Phoenix-style pluggable terminal | 3-pos, 5.08 mm pitch screw-clamp (PCB header + plug) | 1 | Internal 5 V distribution from PSU → fuses; replaces classic fixed screw terminal |
| 12 | 3D-printed enclosure | ~150 × 100 × 60 mm | 1 | See §8.7 |
| 13 | M3 × 8 mm screws + brass inserts | — | 12 | PSU bracket, mains cable clamp, enclosure hardware, and spares. NodeMCU board should use a printed pocket or retaining clip rather than PCB standoffs |
| 14 | Schuko captive mains lead | H05VV-F 3×0.75 mm², CEE 7/7 plug, ≥ 1.5 m | 1 | Captive — jacket clamped inside box; conductors → PSU L/N/PE screw terminals |
| 15 | Heat-shrink tubing assorted | 2 mm, 4 mm, 6 mm | 1 pack | Insulate all solder joints; mandatory on every mains conductor |
| 16 | Cable ties | 2.5 × 100 mm | 1 pack | Internal strain-relief anchors for lamp cables |

> **Strip length confirmed**: 1 m per lamp (60 LEDs each, 120 LEDs total). The strip should span the full driftwood rear face length minus ~5 mm clearance each end. Trim to fit after dry-fitting the aluminium channel.

### 8.3 Power Budget

| Component | Voltage | Max Current | Typical (50 % brightness) |
|---|---|---|---|
| SK6812 Lamp 1 — 60 LEDs × 60 mA | 5 V | **3.60 A** | **0.90 A** |
| SK6812 Lamp 2 — 60 LEDs × 60 mA | 5 V | **3.60 A** | **0.90 A** |
| ESP8266 NodeMCU V3 | 5 V (via onboard reg) | 0.30 A | 0.15 A |
| Level shifter 74AHCT125 | 5 V | 0.02 A | 0.01 A |
| **Total** | 5 V | **7.52 A** | **1.96 A** |

> PSU minimum rating: 7.52 A ÷ 0.80 = **9.40 A** → use a **10 A (50 W) 5 V PSU**.  
> Verify Honeywell PSU nameplate rating ≥ 10 A before finalising.

### 8.4 Wiring Detail

#### 8.4.1 Control Box Internal Wiring

```
Schuko captive lead (H05VV-F 3×0.75)
  ├── Live (brown)     ──▶ PSU L screw
  ├── Neutral (blue)   ──▶ PSU N screw
  └── Earth (gn/yel)   ──▶ PSU PE screw
  └── Outer jacket clamped by 3D-printed 2× M3 cable clamp (back wall)

PSU +5V ──▶ Pluggable terminal pin 1 (V+ bus)
PSU GND ──▶ Pluggable terminal pin 2 (GND bus)
              pin 3 = unused / spare

V+ bus  ──▶ [5A fuse] ──▶ JST Lamp 1 Pin 1 (5V)
GND bus ───────────────▶ JST Lamp 1 Pin 2 (GND)
V+ bus  ──▶ [5A fuse] ──▶ JST Lamp 2 Pin 1 (5V)
GND bus ───────────────▶ JST Lamp 2 Pin 2 (GND)

NodeMCU D5 / GPIO14 ──[330Ω]──▶ 74AHCT125 Channel A IN
                                74AHCT125 Channel A OUT ──▶ JST Lamp 1 Pin 3 (DATA)

NodeMCU D6 / GPIO12 ──[330Ω]──▶ 74AHCT125 Channel B IN
                                74AHCT125 Channel B OUT ──▶ JST Lamp 2 Pin 3 (DATA)

74AHCT125 VCC ──▶ V+ bus (5V)
74AHCT125 GND ──▶ GND bus
74AHCT125 nOE ──▶ GND (always enabled)
NodeMCU VIN / VU ──▶ V+ bus
NodeMCU GND      ──▶ GND bus
```

**JST SM panel-mount detail:** female JST SM 3-pin pigtail is trapped from inside the box wall by a printed rectangular pocket (~9.5 × 6 mm with an internal shoulder lip). The connector body shoulders are wider than the cable hole, so the receptacle cannot pull through the wall. A zip-tie around the cable inside the box provides secondary strain relief. The male plug on the lamp cable inserts from outside the box.

**Mains strain relief detail:** the Schuko lead enters through an 8 mm round hole in the back wall. Immediately inside the wall, a 3D-printed two-screw clamp (2× M3 brass inserts) compresses a rib onto the cable's outer jacket. Conductors continue ~80 mm to the PSU's L / N / PE screw terminals. No mains junction in air.

#### 8.4.2 Lamp Cable (per lamp, 2 m run)

```
Pin 1  (18 AWG red)   ──▶ LED strip +5V pad
Pin 2  (18 AWG black) ──▶ LED strip GND pad
Pin 3  (26 AWG white) ──▶ LED strip DIN pad
```

> Keep data wire physically separate from the power pair (twist or space ≥ 5 mm) to minimise EMI coupling.

#### 8.4.3 Voltage Drop Check

- 18 AWG copper resistance: ~21 mΩ/m
- Round-trip at 2 m: 2 × 2 m × 21 mΩ/m = **84 mΩ**
- At 3.6 A (1 m strip, full load): ΔV = 3.6 × 0.084 = **0.30 V**
- Strip supply voltage: 5.0 − 0.30 = **4.70 V** ✅ (SK6812 spec: 4.5–5.5 V)

### 8.5 WLED Configuration

| Parameter | Lamp 1 | Lamp 2 |
|---|---|---|
| LED output | Output 1 | Output 2 |
| GPIO | 14 (D5) | 12 (D6) |
| LED type | SK6812 RGBW | SK6812 RGBW |
| LED count | **60** | **60** |
| Color order | GRBW | GRBW |
| Max current limit | 4000 mA | 4000 mA |
| Segment | Segment 0 | Segment 1 |
| mDNS name | `reefs.local` | — (same device) |

> **WLED build note**: use the ESP8266 WLED branch for this board (for example, WLED v0.15 / `nodemcuv2`-class build). Output 1 is defined with `LEDPIN=14`; configure the second output in the WLED UI as GPIO12.

**Startup preset recommendations:**
- Preset 1 "Warm Ambient": Effect = Solid, Colour = CCT 3000 K at 40 % brightness, applied to both segments.
- Set as boot preset in WLED → LED Preferences → Boot Preset.

### 8.6 GPIO Pin Assignment (ESP8266 NodeMCU V3)

| GPIO | Function | Notes |
|---|---|---|
| D5 / GPIO14 | LED Data — Lamp 1 | Via 330 Ω + level shifter |
| D6 / GPIO12 | LED Data — Lamp 2 | Via 330 Ω + level shifter |
| D3 / GPIO0 | Boot mode (strapping) | Do not connect to LED data |
| D4 / GPIO2 | Onboard LED / strapping | Leave free in this build |
| D8 / GPIO15 | Boot strapping | Do not connect to LED data |

> The project uses the `ESP8266_NODEMCU_V3` parts-register entry for silkscreen mapping. UNVERIFIED — confirm the silkscreen against your board before wiring the enclosure permanently.

### 8.7 3D-Printed Enclosure Design Spec

| Feature | Requirement |
|---|---|
| Outer dimensions | ≤ 150 × 100 × 60 mm (L × W × H) |
| Wall thickness | ≥ 2.5 mm (PETG or ASA recommended for thermal stability) |
| Ventilation | ≥ 4 × 15 mm slot openings on each side (PSU convection) |
| Mains entry (back wall) | **Ø8 mm round hole for captive Schuko lead** + **printed 2-screw cable clamp** (2× M3 inserts) immediately inside the wall |
| USB service opening (front wall) | Sized to the actual board cutout; current board is NodeMCU V3 Micro-USB |
| Lamp output ports (left/right walls) | **Rectangular pocket ~9.5 × 6 mm with internal shoulder** — traps the female JST SM 3-pin receptacle so the lamp male plug inserts from outside; 1 per side |
| Controller mounting | Printed pocket / clip retention for NodeMCU V3 (no PCB mounting holes) |
| Lid fastening | Snap-on (4× snap-joins, tool-free) |
| Strain relief | Mains: printed M3 cable clamp on jacket. Lamps: connector body trapped by pocket + internal zip-tie anchor on cable |

> `ESP8266_NODEMCU_V3` is an UNVERIFIED parts-register entry. Confirm board size and Micro-USB position before treating these enclosure updates as manufacturing-ready.

> Source files: [`mechanical/enclosure/CustomProjectEnclosureV1.7.8b.3mf`](mechanical/enclosure/CustomProjectEnclosureV1.7.8b.3mf) — BambuStudio 3MF project.  
> See [`mechanical/enclosure/MODELS.md`](mechanical/enclosure/MODELS.md) for full print profile.

---

### 8.8 Home Assistant Integration

#### Import Setup

**Recommended entry point:** Open `http://reefs.local/ha-import.html` in a browser while on the same network as the device. The page auto-reads WLED device info, displays expected HA entity IDs, and provides one-click blueprint import links + a pre-filled `package.yaml` download.

See [`homeassistant/README.md`](homeassistant/README.md) for step-by-step instructions.

#### Device Discovery

WLED auto-discovers in Home Assistant via the **native WLED integration** (no YAML required).

- mDNS hostname: **`reefs.local`**
- `cfg.json` must have `"nw": {"mdns": 1}` and `"id": {"mdns": "reefs"}` (see `firmware/cfg.json`)
- HA discovers the device within 60 s of WLED boot; both segments appear as separate light entities.

#### Expected HA Entity IDs

| Entity | Entity ID | Notes |
|---|---|---|
| Master (both lamps) | `light.reefs` | WLED device master entity |
| Lamp 1 (Driftwood A) | `light.reefs_lamp_1` | Segment 0, D5 / GPIO14 |
| Lamp 2 (Driftwood B) | `light.reefs_lamp_2` | Segment 1, D6 / GPIO12 |
| Preset selector | `select.reefs_preset` | WLED preset entity |

> Entity IDs are auto-generated by WLED integration from the device name + segment names set in `cfg.json`.  
> Verify actual entity IDs in HA after first discovery. `ha-import.html` shows live IDs computed from the device.

#### Config Files

| File | Purpose |
|---|---|
| [`homeassistant/package.yaml`](homeassistant/package.yaml) | HA Package: helpers, scripts, automations |
| [`homeassistant/blueprints/`](homeassistant/blueprints/) | Importable blueprints (sunset-on, night-dim, scheduled-off) |
| [`homeassistant/lovelace.yaml`](homeassistant/lovelace.yaml) | Ready-made dashboard card |
| [`firmware/spiffs/ha-import.html`](firmware/spiffs/ha-import.html) | Device-served import assistant |

#### hacs-wledext-effects

`hacs-wledext-effects` is **not required** for the v1 reefs build — all effects are purely decorative with no relationship to HA sensor state. Static WLED presets + the automations below are sufficient.

If state-driven effects are added in a future revision (e.g., Breathe on notification, Meter for temperature), install `hacs-wledext-effects` and document effect entity IDs here.

#### Automations (included in package.yaml)

| Automation | Trigger | Action |
|---|---|---|
| `reefs_sunset_on` | 30 min before sunset | Both lamps → Warm Ambient, 40% |
| `reefs_dim_late_evening` | 23:00 | Both lamps → Night Glow, 10% |
| `reefs_off_midnight` | 00:00 | Both lamps off |
| `reefs_movie_mode_on` | `input_boolean.reefs_movie_mode` turns on | Both lamps → dim warm, 15% |

#### Acceptance Criteria

- [ ] Both lamp entities appear in HA within 60 s of WLED boot — no manual YAML
- [ ] `light.reefs_lamp_1` and `light.reefs_lamp_2` independently controllable (on/off, brightness, colour, effect)
- [ ] `ha-import.html` loads at `http://reefs.local/ha-import.html` and shows correct entity IDs
- [ ] At least one blueprint importable via `my.home-assistant.io` badge
- [ ] `package.yaml` installs via HA packages without errors
- [ ] Sunset automation fires within 30 s of scheduled time
- [ ] HA shows "unavailable" on Wi-Fi loss and recovers within 30 s on reconnect

---

## 9. Milestones & Roadmap

### MVP (v1.0) — Both Lamps Functional

| Step | Task | Done? |
|---|---|---|
| 1 | Flash ESP8266 WLED to the NodeMCU V3, verify Wi-Fi connection | ☐ |
| 2 | Bench-test SK6812 strip with WLED (single strip, D5 / GPIO14) | ☐ |
| 3 | Measure driftwood rear faces; cut and mount aluminium channels | ☐ |
| 4 | Solder strips into channels; test both strips on bench | ☐ |
| 5 | Print control box enclosure v1 | ☐ |
| 6 | Assemble control box: PSU, terminal block, NodeMCU V3, level shifter, fuses | ☐ |
| 7 | Wire both lamp cables; connect via JST connectors | ☐ |
| 8 | Configure WLED: 2 outputs, LED counts, SK6812 type, boot preset | ☐ |
| 9 | Add WLED integration to Home Assistant; verify 2 light entities | ☐ |
| 10 | Mount lamps; route and conceal cables | ☐ |
| 11 | Thermal soak test: 60 min at 50 % brightness; verify ≤ 45 °C | ☐ |

### v1.1 — Polish

- Create Home Assistant "Reef Scene" script.
- Add sunrise/sunset automations.
- Label all wires inside control box.
- Photograph and archive wiring for future reference.

### v2.0 — Future Consideration

- Add physical touch button on each driftwood piece (capacitive, via GPIO).
- Audio-reactive mode (microphone breakout on a future ESP32 migration).
- Power monitor (INA226) to track real-time draw.

### Technical Risks

| Risk | Likelihood | Mitigation |
|---|---|---|
| SK6812 data signal marginal at 3.3 V over 2 m | Medium | 74AHCT125 level shifter (included in BOM) |
| Driftwood thickness blocks heat dissipation | Low | Aluminium channel conducts heat to air, not into wood |
| PSU current rating insufficient | Low | Verify nameplate before build; replace if < 10 A |
| WLED 2-output support on selected GPIO | Low | D5/GPIO14 and D6/GPIO12 are standard WLED-capable output pins on NodeMCU-class ESP8266 boards |

---

## 10. Open Questions

- Which exact driftwood piece dimensions (length × depth) determine the final strip length per lamp?
- Is the Honeywell PSU model confirmed as ≥ 10 A, or does it need replacement?
- Should the control box mount inside a shelf or on the wall behind it?
- Is cable management via baseboard trunking sufficient, or does the installation need in-wall conduit?

---

## 11. Changelog

| Date | Change |
|---|---|
| 2026-05-17 | Switched project controller definition to ESP8266 NodeMCU V3 with D5/D6 outputs |
| 2026-05-16 | Initial spec (v1.0 draft) |

---

## 12. Appendix — User Stories

| ID | User Story | Priority | Acceptance Criteria |
|---|---|---|---|
| GH-001 | As a resident, I want to control Lamp 1 and Lamp 2 independently from HA so that each lamp can be set to different states. | High | Toggling one HA entity does not change the other's state. |
| GH-002 | As a resident, I want to set brightness and colour temperature per lamp so that I can adapt ambience to activity. | High | Full 1–100 % brightness range; CCT range 2700–6500 K usable. |
| GH-003 | As a resident, I want to apply WLED effects per lamp independently so that lamps can display different effects simultaneously. | Medium | Any WLED effect applied to Lamp 1 does not override Lamp 2. |
| GH-004 | As a builder, I want WLED to auto-discover in HA with no manual YAML so that setup is repeatable. | High | Both entities appear in HA within 60 s of WLED boot, zero manual config. |
| GH-005 | As a resident, I want a single "Reef Scene" HA trigger that sets both lamps to the warm ambient preset so that one tap sets the room mood. | Medium | Both lamps reach preset within 500 ms of scene trigger. |
| GH-006 | As a builder, I want the PSU to run at < 80 % load at peak brightness so that it runs safely long-term. | High | Calculated peak draw ≤ PSU rated current × 0.80. |
| GH-007 | As a builder, I want a 5 A inline fuse on each lamp power feed so that a fault cannot damage the PSU. | High | Each lamp cable has dedicated fuse; fuse blows on 6 A sustained test current. |
| GH-008 | As a builder, I want the LED strips in aluminium channels so that heat is conducted away from the wood. | High | Strip temp ≤ 45 °C at 50 % brightness after 60 min. |
| GH-009 | As a builder, I want all wiring concealed so that the installation looks furniture-grade. | High | No visible wire segments from room-facing viewpoint. |
| GH-010 | As a builder, I want a USB service port accessible on the enclosure for OTA recovery so that I can re-flash without disassembly. | Medium | USB cable connects to the NodeMCU through the enclosure port without removing lid. |

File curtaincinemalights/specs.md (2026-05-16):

# PRD: curtaincinemalights — Cinema Curtain LED Sync

- **Version**: 1.0
- **Date**: 2026-05-16
- **Status**: `wip`

---

## 1. Concept

A single SK6812 RGBW LED strip (60 LED/m) runs along an aluminium channel profile mounted
on the L-shaped wall brackets of a motorized cinema-style curtain rail, between the wall and
the red curtain fabric. The strip illuminates the gap between wall and curtain, creating a
dynamic halo that mirrors the exact position and movement of the two curtain panels in
real time.

When the curtain opens (two panels from center toward the sides), the LEDs follow: the
center LEDs light first and the lit zone spreads outward — always at the same percentage as
the actual curtain opening. When the curtain closes, the reverse. Cinema mode (projector
playing) switches to a slow dim red breathe; non-cinema mode transitions back to ambient.

The system runs on an **ESP8266 LOLIN D1 Mini** with WLED v0.15 (ESP8266 branch), and all
state-driven effects are orchestrated by **hacs-wledext-effects** (State Sync + Chase +
Breathe) reacting to Home Assistant entities for the motorized cover and media player.

---

## 2. Requirements

- [x] LED type: SK6812 RGBW 60 LED/m, IP20, 5V, GRB+W order, aluminium channel with diffuser
- [x] LED count: 60 × curtain_width_m — plan for 3 m ≈ **180 LEDs** (two virtual half-segments of 90)
- [x] Power: 230 V AC mains → Hi-Link HLK-20M05 (5V 4A) inside enclosure; WLED ABL = 3200 mA
- [x] Mounting: aluminium U-channel profile on L-bracket curtain rail wall mounts; diffusing cover
- [x] Connectivity: 2.4 GHz Wi-Fi (WLED captive portal, then station mode)
- [x] Smart home integration: Home Assistant via native WLED integration (mDNS auto-discovery)
- [x] hacs-wledext-effects: yes — State Sync, Chase, Breathe, Rainbow Wave (see §6)
- [x] Sound-reactive: no
- [x] Outdoor / indoor: indoor (IP20 strip, IP20 enclosure)
- [x] IP rating: IP20 (protected from direct contact; no moisture)

---

## 3. Constraints

- Budget: ~€40 (excluding existing PSU / D1 Mini if on hand)
- Enclosure size max: 120 × 55 × 50 mm — must fit on shelf or inside curtain alcove
- Power availability: 230 V AC socket near curtain rail; no low-voltage DC available on rail
- ESP8266 constraint: WLED v0.15 branch (legacy); single output only; ~150 LED buffer limit
  per JSON API batch — hacs-wledext-effects auto-batches
- Curtain width variable: 2–4 m; WLED LED count configurable in web UI post-flash
  (default config uses 180 LEDs = 3 m; adjust `leds.ins[0].len` in cfg.json or WLED UI)

---

## 4. Mechanical

- Control box: 3D-printed YAPP_Box (PETG/ASA), snap-on lid
- Box outer target: 106 × 46 × 44 mm (inner: 100 × 40 × 35 mm)
- Wall thickness: 3.0 mm
- PSU (HLK-20M05, 56 × 32 × 22.5 mm) and D1 Mini (34.2 × 25.6 × 10 mm) both in base shell
- D1 Mini held in friction-fit pocket (no native mounting holes); PSU held by side-wall ribs
- Aluminium LED channel profile: standard U-profile 12–16 mm wide with clear/frosted diffuser lid
  — length = curtain track width; cut to measure on site

---

## 5. Acceptance Criteria

- [ ] All LEDs addressable at WLED startup; no flickering at 50 % brightness
- [ ] WLED web UI reachable on local network as `curtaincinemalights.local`
- [ ] Both WLED segments (Left Panel, Right Panel) independently controllable from WLED UI
- [ ] Auto-discovered in Home Assistant within 60 s of WLED boot; on/off, brightness, colour verified
- [ ] Template sensor `sensor.cinema_curtain_position` reads cover position correctly
- [ ] State Sync effect on both segments tracks curtain position (center fill, L and R match)
- [ ] Chase effect activates on opening/closing transitions and deactivates when motion stops
- [ ] Breathe (dim red) activates when `media_player.projector` enters `playing` state
- [ ] Breathe stops and ambient mode resumes when projector leaves `playing` state
- [ ] PSU thermal: enclosure surface ≤ 60 °C after 30-min continuous operation
- [ ] Enclosure closed, cable strain-relieved, no exposed mains conductors
- [ ] All hacs-wledext-effects entities documented below with actual entity IDs

---

## 6. Home Assistant

> **Mandatory** — every project in this repo must be controllable from Home Assistant via the
> native WLED integration (auto-discovered via mDNS).

- **Device mDNS hostname:** `curtaincinemalights`
  (set in `firmware/cfg.json` → `"id": {"mdns": "curtaincinemalights"}` and `"nw": {"mdns": 1}`)

### 6.1 Native WLED Integration Entities

| Entity ID | Description |
|---|---|
| `light.curtaincinemalights` | Master light (both segments) |
| `light.curtaincinemalights_left_panel` | Segment 0 — Left panel (LEDs 0–89, reversed) |
| `light.curtaincinemalights_right_panel` | Segment 1 — Right panel (LEDs 90–179, normal) |

### 6.2 Helper Entities to Create in HA

| Entity ID | Type | Purpose |
|---|---|---|
| `sensor.cinema_curtain_position` | Template sensor | Exposes `cover.cinema_curtain` `current_position` attribute (0–100 %) as a numeric sensor for hacs-wledext-effects State Sync |
| `input_boolean.cinema_mode_active` | Input boolean | Manual override — set `on` to force cinema Breathe regardless of projector state |

Template sensor YAML (add to `configuration.yaml` or in the Template integration UI):
```yaml
template:
  - sensor:
      - name: "Cinema Curtain Position"
        unique_id: cinema_curtain_position_sensor
        state: "{{ state_attr('cover.cinema_curtain', 'current_position') | int(0) }}"
        unit_of_measurement: "%"
        device_class: power_factor
        state_class: measurement
```

### 6.3 hacs-wledext-effects

**Installation:**
1. Add HACS custom repo `https://github.com/tamaygz/hacs-wledext-effects` (category: Integration)
2. Install "WLED Effects" → restart HA
3. Settings → Devices & Services → Add → "WLED Effects" → select `curtaincinemalights` device

**Effects to install and configure:**

| Effect | Instance Name | Segment | Config notes |
|---|---|---|---|
| **State Sync** | `ccl_left_state_sync` | Left Panel (seg 0) | `state_entity: sensor.cinema_curtain_position`, `min_value: 0`, `max_value: 100`, `animation_mode: fill`, color warm amber `255,147,41` |
| **State Sync** | `ccl_right_state_sync` | Right Panel (seg 1) | Same config; segment is not reversed in effect — the WLED segment itself is reversed so fill naturally goes center→left |
| **Chase** | `ccl_chase_left` | Left Panel | Triggered on `opening` state; direction outward |
| **Chase** | `ccl_chase_right` | Right Panel | Triggered on `opening` state; direction outward |
| **Breathe** | `ccl_cinema_breathe` | Both (master) | `pulse_rate: 0.3`, dim red `180,0,0`, brightness 40; active during projector `playing` |
| **Rainbow Wave** | `ccl_ambient_rainbow` | Both (master) | Idle/ambient when curtain fully open and no cinema mode |

**Expected effect switch entities:**

| Entity ID | Effect |
|---|---|
| `switch.wled_context_effects_ccl_left_state_sync` | Left panel curtain position |
| `switch.wled_context_effects_ccl_right_state_sync` | Right panel curtain position |
| `switch.wled_context_effects_ccl_chase_left` | Left panel opening chase |
| `switch.wled_context_effects_ccl_chase_right` | Right panel opening chase |
| `switch.wled_context_effects_ccl_cinema_breathe` | Cinema mode breathe |
| `switch.wled_context_effects_ccl_ambient_rainbow` | Ambient rainbow wave |

### 6.4 Automation Logic Summary

See `design/effects/ha-automations.yaml` for full YAML.

| Trigger | Action |
|---|---|
| `cover.cinema_curtain` → `opening` | Stop State Sync; start Chase both panels (outward) |
| `cover.cinema_curtain` → `closing` | Stop State Sync; start Chase both panels (inward) |
| `cover.cinema_curtain` → `open` or `closed` | Stop Chase; resume State Sync / Rainbow Wave |
| `cover.cinema_curtain` position changes (stationary) | State Sync updates automatically via sensor |
| `media_player.projector` → `playing` | Stop all effects; start Cinema Breathe |
| `media_player.projector` → `idle` / `off` | Stop Cinema Breathe; resume State Sync or Rainbow Wave |

---

## 7. Open Questions

- [ ] Exact curtain width (measure on site → update `leds.ins[0].len` in WLED)
- [ ] HA entity IDs for `cover.cinema_curtain` and `media_player.projector` (confirm from HA instance)
- [ ] Confirm actual hacs-wledext-effects entity ID suffix format after first install
- [ ] Level shifter: 74AHCT125 recommended for ESP8266 → 5V SK6812; verify if direct GPIO2 works reliably at install
- [ ] IP rating of aluminium track / diffuser — confirm IP20 acceptable (not near open window)

---

## 8. Power Budget

| Component | Voltage | Max Current | Typical @ 25 % brightness |
|---|---|---|---|
| SK6812 — 180 LEDs × 60 mA/LED (worst case all white) | 5 V | **10.80 A** | ~0.67 A |
| SK6812 — 180 LEDs × 60 mA (WLED ABL cap: 3200 mA) | 5 V | **3.20 A** | ~0.67 A |
| ESP8266 D1 Mini | 5 V (onboard reg) | 0.30 A | 0.18 A |
| 74AHCT125 level shifter | 5 V | 0.02 A | 0.01 A |
| **Total (ABL capped)** | 5 V | **3.52 A** | **0.86 A** |

> PSU: HLK-20M05 rated 4A. Load at ABL cap = 3.52A = **88 % of rated current** — acceptable for
> continuous operation at ambient temperature. If usage ever peaks near 100 % brightness (white),
> reduce ABL to 3000 mA or upgrade to HLK-30M05 (6A).

---

## 9. Changelog

| Date | Change |
|---|---|
| 2026-05-16 | Initial spec |

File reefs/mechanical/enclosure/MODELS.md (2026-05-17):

# 3D Models & Enclosure — Reefs

## Automated Variant Enclosure (Parametric YAPP)

Parametric PETG enclosure generated via the [`enclosure-gen`](../../../.github/skills/enclosure-gen/SKILL.md) skill, using shared YAPP library at `tools/yapp/YAPPgenerator_v3.scad`.

> Legacy controller geometry: the current SCAD and rendered outputs still use the previous ESP32 DevKit mount and front USB opening. The `reefs` project controller definition moved to `ESP8266_NODEMCU_V3`; refit the board mount and service-port cutout before the next print.

**Snap-on lid — no screws, tool-free open/close.**

| Property | Value |
|---|---|
| Source | [`reefs-automatedvariant-enclosure.scad`](reefs-automatedvariant-enclosure.scad) |
| Spec | [`reefs-automatedvariant-enclosure-spec.md`](reefs-automatedvariant-enclosure-spec.md) |
| Outer | 150 × 100 × 59 mm |
| Inner | 144 × 94 × 56 mm |
| Wall thickness | 3.0 mm |
| Ridge height | 6.0 mm (≥ wallThickness × 1.8 for snapJoins) |
| Lid closure | 4 × snap-joins on long walls (15 mm wide, posx = 40 & 110) |
| PCB standoffs | 4 × M3, `yappBaseOnly` (no stems on lid) |

### Files

| File | Description |
|---|---|
| [`reefs-automatedvariant-base.stl`](reefs-automatedvariant-base.stl) | Base shell |
| [`reefs-automatedvariant-lid.stl`](reefs-automatedvariant-lid.stl) | Lid shell |
| [`reefs-automatedvariant-base-iso.png`](reefs-automatedvariant-base-iso.png) | Base — isometric preview |
| [`reefs-automatedvariant-base-top.png`](reefs-automatedvariant-base-top.png) | Base — top-down preview |
| [`reefs-automatedvariant-lid-iso.png`](reefs-automatedvariant-lid-iso.png) | Lid — isometric preview |
| [`reefs-automatedvariant-lid-top.png`](reefs-automatedvariant-lid-top.png) | Lid — top-down preview |

### Re-generate

```powershell
# From repo root — produces both STLs and all 4 preview PNGs
pwsh tools/render_enclosure.ps1 -Project reefs -ScadName reefs-automatedvariant-enclosure
```

---

## Control Box Enclosure (Legacy BambuStudio)

Custom-designed PETG enclosure for the older ESP32 controller variant, with 74AHCT125 level shifter, screw terminal bus, inline fuses, and IEC C14 inlet.

| Property | Value |
|---|---|
| BambuStudio project | [`CustomProjectEnclosureV1.7.8b.3mf`](CustomProjectEnclosureV1.7.8b.3mf) |
| Outer dimensions | ≤ 150 × 100 × 60 mm (L × W × H) |
| Material | PETG (preferred) or ASA |
| Rendered preview | [`case-preview.png`](case-preview.png) |
| Top-view render | [`case-top.png`](case-top.png) |

### Print Settings

| Setting | Value |
|---|---|
| Material | PETG |
| Layer height | 0.2 mm |
| Infill | 20% gyroid |
| Walls | 3 |
| Supports | Touching build plate only |
| Bed temp | 80 °C |
| Nozzle | 230 °C |

### Cutouts & Features

| Feature | Dimension | Notes |
|---|---|---|
| IEC C14 inlet | 28 × 48 mm | Standard panel-mount C14 |
| USB access port | 12 × 6 mm slot | Legacy ESP32-aligned opening; refit for the NodeMCU V3 before reuse |
| Cable gland holes (PG9) | × 2 | One per lamp cable entry |
| Ventilation slots | ≥ 4 × 15 mm per side | PSU natural convection |
| PCB standoffs | 4 × M3, 20 × 30 mm pattern | Legacy ESP32 DevKit mount |
| Lid fastening | 4 × M3 × 8 mm | Top-opening lid with brass inserts |

---

## Aluminium LED Channels

Not a 3D-printed part — off-the-shelf U-profile aluminium channels are used to mount the SK6812 strips on the rear face of each driftwood piece.

| Property | Value |
|---|---|
| Profile type | U-channel with diffuser clip |
| Width | 12 mm (fits SK6812 8mm strip with margin) |
| Length | ≥ driftwood rear face length (≤ 1 m) |
| Example product | LUMINES Type-Z or equivalent |
| Purpose | Conducts heat away from wood; provides diffused line light |

---

## Future Models

> If aluminium channel brackets or cable management clips are designed, add STL files here and update the table below.

| File | Purpose | Status |
|---|---|---|
| _(none yet)_ | | |

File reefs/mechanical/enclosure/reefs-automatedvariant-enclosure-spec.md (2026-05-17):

# Reefs Enclosure — Automated Variant Spec

Generated via `enclosure-gen` skill using YAPP_Box v3.3.8.

> Legacy controller geometry: this automated variant still uses the previous ESP32 DevKit standoffs and front USB opening. The project controller definition now targets `ESP8266_NODEMCU_V3`; refit the board mount and service-port cutout before the next enclosure render.

## Dimensions

| Parameter | Value |
|---|---|
| Outer | 150 × 100 × 59 mm |
| Inner (usable) | 144 × 94 × 56 mm |
| Wall thickness | 3.0 mm |
| Base floor | 1.5 mm |
| Lid ceiling | 1.5 mm |
| Base wall height | 30 mm |
| Lid wall height | 26 mm |
| Ridge height | 6.0 mm |
| Corner radius | 3.0 mm |

> Ridge height bumped from 5.0 → 6.0 mm to satisfy YAPP's snap-join geometry
> constraint (`ridgeHeight ≥ wallThickness × 1.8 = 5.4 mm`).

## Files

| File | Description |
|---|---|
| `reefs-automatedvariant-enclosure.scad` | Parametric SCAD config |
| `reefs-automatedvariant-base.stl` | Base shell (print-ready) |
| `reefs-automatedvariant-lid.stl` | Lid shell (print-ready) |
| `reefs-automatedvariant-base-iso.png` | Base preview — isometric |
| `reefs-automatedvariant-base-top.png` | Base preview — top-down |
| `reefs-automatedvariant-lid-iso.png`  | Lid preview — isometric  |
| `reefs-automatedvariant-lid-top.png`  | Lid preview — top-down  |

Render all six in one step:

```powershell
pwsh tools/render_enclosure.ps1 -Project reefs -ScadName reefs-automatedvariant-enclosure
```

## Shared Library

`tools/yapp/YAPPgenerator_v3.scad` — YAPP_Box v3.3.8 (mrWheel/YAPP_Box, MIT)

Include pattern: `include` must come **before** all config variables (OpenSCAD "last assignment wins").  
`YAPPgenerate()` is called explicitly to bypass the library's `if (debug)` guard.

## Wall Cutouts

### Back wall — Schuko captive mains lead entry
- Cable hole: Ø8 mm (circle), centre Y = 47 mm, Z = 30 mm
- Clamp screw holes: 2× Ø3.2 mm at Y = 35 / 59 mm (12 mm each side of centre), Z = 30 mm
- Purpose: captive Schuko H05VV-F 3×0.75 mm² lead jacket clamped by an external 2-screw printed clamp (M3 brass inserts)

### Front wall — USB service access (legacy ESP32 geometry)
- Opening: 12 × 8 mm (rectangle)
- Centre: Y = 47 mm, Z = 10 mm from inner floor
- Purpose: current opening was sized for the earlier ESP32 USB port; resize/reposition for the NodeMCU V3 before the next print

### Left wall — Lamp 1
- JST SM panel-mount pocket: 9.5 × 6 mm rectangle, centre X = 72 mm, Z = 25 mm
- Female JST SM 3-pin body is trapped from the inside; lamp male plug inserts from outside
- Ventilation: 4 × (15 × 4 mm) slots at Z = 20 mm, X = 15, 40, 104, 129 mm

### Right wall — Lamp 2 (mirror of left)
- JST SM panel-mount pocket: 9.5 × 6 mm rectangle, centre X = 72 mm, Z = 25 mm
- Ventilation: 4 × (15 × 4 mm) slots at Z = 20 mm, X = 15, 40, 104, 129 mm

## Legacy ESP32 Standoffs

4 × M3 threaded standoffs (5 mm height, Ø7 mm outer, Ø3 mm pin), **base only**
(`yappBaseOnly` — the lid stays clear of standoff stems):

| Position | PCB coord (X, Y) | Corner |
|---|---|---|
| Back-left | 81, 35 | yappBackLeft |
| Back-right | 81, 58 | yappBackRight |
| Front-left | 126, 35 | yappFrontLeft |
| Front-right | 126, 58 | yappFrontRight |

Board orientation in the current SCAD: USB connector toward FRONT wall (high X).

## Lid Closure — Snap-On (no screws)

The lid uses YAPP `snapJoins` so it presses onto the base by hand and can be
opened without tools. Four snaps total, on the two long walls:

| Snap | Wall | Position along wall | Width |
|---|---|---|---|
| 1 | Left  | 40 mm  | 15 mm |
| 2 | Left  | 110 mm | 15 mm (mirrored via `yappSymmetric`) |
| 3 | Right | 40 mm  | 15 mm |
| 4 | Right | 110 mm | 15 mm (mirrored via `yappSymmetric`) |

SCAD entry:

```scad
connectors = [];
snapJoins  = [
  [40, 15, yappLeft, yappRight, yappCenter, yappSymmetric],
];
```

If screw fastening is later required, replace `snapJoins` with a `connectors[]`
entry and drop `ridgeHeight` back to 5.0 mm.

## Lid Labels (engraved)

| Text | Face | Position | Size |
|---|---|---|---|
| `REEFS` (bold) | Lid | centre | 10 mm |
| `WLED v0.15 \| SK6812 RGBW` | Lid | centre | 6 mm |
| `2x 60-LED Lamps \| 5V 10A PSU` | Lid | centre | 4 mm |
| `MAINS` (bold) | Back | above cable entry | 4 mm |
| `OTA` | Front | above USB service cutout | 4 mm |
| `LAMP 1` | Left | above JST pocket | 4 mm |
| `LAMP 2` | Right | above JST pocket | 4 mm |

## Print Settings

| Parameter | Recommended |
|---|---|
| Material | PETG (or ASA for higher heat tolerance) |
| Layer height | 0.2 mm |
| Perimeters | 4 |
| Infill | 20 % (gyroid or grid) |
| Supports | None required |
| Bed adhesion | Brim (base), none needed for lid |

## Render Commands

From repo root — single command produces both STLs **and** the four preview PNGs:

```powershell
pwsh tools/render_enclosure.ps1 -Project reefs -ScadName reefs-automatedvariant-enclosure
```

Manual fallback (per shell):

```bash
openscad --render -o reefs-automatedvariant-base.stl \
  reefs-automatedvariant-enclosure.scad -D "printLidShell=false"
openscad --render -o reefs-automatedvariant-lid.stl  \
  reefs-automatedvariant-enclosure.scad -D "printBaseShell=false"
```

## Spec Compliance

| Requirement | Target | Actual |
|---|---|---|
| Outer length | ≤ 150 mm | 150 mm ✓ |
| Outer width | ≤ 100 mm | 100 mm ✓ |
| Outer height | ≤ 60 mm | 59 mm ✓ |
| Legacy ESP32 mount | 4× M3 standoffs | ✓ |
| Mains entry | Captive Schuko lead via Ø8 mm hole + 2-screw clamp | ✓ |
| OTA access | Front service opening | ✓ |
| Lamp ports | 2× JST SM panel-mount pockets (left + right) | ✓ |
| Ventilation | 4 slots per side | ✓ |
| Fasteners | tool-free | 4× snap-joins (no screws) ✓ |

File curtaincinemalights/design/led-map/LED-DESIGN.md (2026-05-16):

# LED Design — curtaincinemalights

> Curtain: two-panel, center-open, motorized
> Strip: single SK6812 RGBW run, 60 LED/m, in aluminium channel along curtain rail

---

## Physical Layout

```
Wall                               Ceiling
  │                                   │
  │  ◄── aluminium track + strip ──► │
  │  LED 0                  LED 179  │
  │  ├─────────────────────────────┤  │
  │  │  Left panel   Right panel  │  │
  │  │  0 → 89       90 → 179     │  │
  │  │                            │  │
  │  ▲ data in              data → │  │ (single data run, no mid-inject on data)
  │  (from box, JST SM female)     │  │
  │                                   │
  └───────────────────────────────────┘
```

- LED 0 = far left end of curtain track
- LED 89 = center-left (1 LED to the left of physical center)
- LED 90 = center-right (1 LED to the right of physical center)
- LED 179 = far right end of curtain track
- Power injection at both LED 0 (start of strip) and LED 90 (midpoint) — data is a single continuous run

---

## Segment Configuration

Both segments are on a **single physical WLED output (GPIO2)**.  
WLED version: v0.15 (ESP8266 branch — single output, segments are virtual software split).

| Segment | ID | LED range | WLED `rev` | Fill direction | Name |
|---|----|---|---|---|---|
| Left Panel | 0 | 0 – 89 | `true` (reversed) | From center outward → left | `Left Panel` |
| Right Panel | 1 | 90 – 179 | `false` (normal) | From center outward → right | `Right Panel` |

**Why reversed on Left Panel?**  
With `rev=true`, LED 89 (nearest center) is effectively LED index 0 of the reversed segment.
WLED's fill-based effects (State Sync `animation_mode: fill`) light from index 0 upward.
So with the left segment reversed, fill lights from center toward the left edge — exactly
matching the left curtain panel opening outward.

The right segment (`rev=false`) naturally lights from index 0 (LED 90, nearest center)
outward toward the right edge.

---

## Effect Behavior Mapping

| Curtain state | LED behavior | hacs-wledext-effects instance |
|---|---|---|
| Fully closed (position = 0 %) | No LEDs lit (or a dim accent, configurable) | State Sync → 0 % fill = dark |
| Partially open (e.g. 50 %) | Center 50 % of each half lit, warm amber | State Sync fill ← `sensor.cinema_curtain_position` |
| Fully open (position = 100 %) | All LEDs lit, warm amber, then transition to Rainbow Wave | State Sync 100 %, then Rainbow Wave |
| Opening (cover.state = `opening`) | Chase effect sweeping outward on both halves | Chase (both segments) |
| Closing (cover.state = `closing`) | Chase effect sweeping inward on both halves | Chase (both segments, direction reversed) |
| Cinema mode (projector `playing`) | Dim red, slow breathe; all other effects paused | Breathe (master) |

---

## WLED cfg.json Segment Definitions

```json
"seg": [
  {
    "id": 0, "start": 0,  "stop": 89,
    "name": "Left Panel",  "rev": true,
    "col": [[255, 147, 41, 30]], "fx": 0
  },
  {
    "id": 1, "start": 90, "stop": 179,
    "name": "Right Panel", "rev": false,
    "col": [[255, 147, 41, 30]], "fx": 0
  }
]
```

`col`: [R=255, G=147, B=41, W=30] — warm amber with slight warm-white channel.
`fx: 0` = static (hacs-wledext-effects overrides this when an effect is active).

---

## Adjusting LED Count for Different Curtain Widths

| Curtain width | LED count | Segment split |
|---|---|---|
| 2.0 m | 120 LEDs | 0–59 + 60–119 |
| 2.5 m | 150 LEDs | 0–74 + 75–149 |
| 3.0 m (default) | 180 LEDs | 0–89 + 90–179 |
| 3.5 m | 210 LEDs | 0–104 + 105–209 |
| 4.0 m | 240 LEDs | 0–119 + 120–239 |

To adjust: in WLED web UI → LED Preferences → change total LED count and both segment stop values.
Or edit `firmware/cfg.json` manually and reflash / reupload.

> **ESP8266 buffer limit:** WLED v0.15 on ESP8266 supports ≤ ~500 LEDs on one output but JSON
> API calls are batched at ~150 LED chunks. All counts in the table above are within safe limits.

---

## Colour Presets

| Preset | Effect | Colour | Notes |
|---|---|---|---|
| 1 — Warm Amber | Solid | R255 G147 B41 W30 | Boot default; nice ambient when curtain partially open |
| 2 — Cinema Dim | Solid / Breathe | R180 G0 B0 W0 | Loaded by HA automation when projector starts |
| 3 — Ambient Wave | Rainbow Wave | — | Loaded by HA automation when curtain fully open (non-cinema) |

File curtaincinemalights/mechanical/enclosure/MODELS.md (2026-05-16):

# Enclosure Models — curtaincinemalights

> Generated by `tools/render_enclosure.ps1 -Project curtaincinemalights -ScadName curtaincinemalights-enclosure`
> Source: `curtaincinemalights-enclosure.scad` (YAPP_Box v3)

## Print Specifications

| Property | Value |
|---|---|
| Material | PETG (preferred) or ASA |
| Layer height | 0.2 mm |
| Infill | 25 % gyroid |
| Perimeters | 3 |
| Top/bottom layers | 4 |
| Supports | None required (snap-on lid prints flat) |
| Estimated filament | ~90 g |

## Outer Dimensions

| Axis | Value |
|---|---|
| Length (X, front–back) | 106 mm |
| Width (Y, left–right) | 46 mm |
| Height (Z, total with snap lid) | ~44 mm |

## Files

| File | Description |
|---|---|
| `curtaincinemalights-base.stl` | Base shell (components + PSU pocket) |
| `curtaincinemalights-lid.stl` | Snap-on lid |
| `curtaincinemalights-base-iso.png` | Isometric preview — base |
| `curtaincinemalights-base-top.png` | Top-down preview — base |
| `curtaincinemalights-lid-iso.png` | Isometric preview — lid |
| `curtaincinemalights-lid-top.png` | Top-down preview — lid |

## Component Fit Notes

- **D1 Mini** (34.2 × 25.6 × 10 mm): friction-fit in front pocket; USB-C port faces front wall cutout.
  Holds in place once lid is snapped. No mounting screws needed (no holes on D1 Mini PCB).
- **HLK-20M05** (56 × 32 × 22.5 mm): friction-fit in rear pocket; DIP AC pins face back wall, DC output
  faces left wall toward JST connector. The 22.5 mm module height fits within the 25 mm base wall.
- **74AHCT125 DIP-14**: sits on a small piece of stripboard between D1 Mini and PSU; held with double-sided foam tape.
  Alternatively, the level shifter can be soldered directly in-line without a PCB.

## Cutout Summary

| Wall | Cutout | Size | Purpose |
|---|---|---|---|
| Front | Rounded slot | 9.0 × 3.5 mm | USB-C access for D1 Mini OTA / flashing |
| Back | Circle | Ø9 mm | Mains cable (H05VV-F 3×0.75) entry; use printed cable clamp |
| Left | Rectangular pocket | 9.5 × 6 mm | JST SM 3-pin panel-mount socket (LED strip output) |
| Left | 3× vent slots | 12 × 3 mm | PSU and ESP convection cooling |
| Right | 3× vent slots | 12 × 3 mm | Mirror cooling vents |

## Re-Render Command

```powershell
pwsh tools/render_enclosure.ps1 -Project curtaincinemalights -ScadName curtaincinemalights-enclosure
```

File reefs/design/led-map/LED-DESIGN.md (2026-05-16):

# LED Map & Effects Design — Reefs

## Physical Layout

Two separate 1 m SK6812 RGBW strips, each mounted in an aluminium U-channel on the **rear face** of one driftwood piece (wall-facing). Light washes the wall; the room-facing side of the wood stays dark.

```
LAMP 1 — Driftwood piece A
  Strip direction (DIN end at JST connector, left side of lamp)

  [0] [1] [2] [3] ... [57] [58] [59]
   ◀─────────────────────────────────
   DIN                            end
   (JST connector end)

LAMP 2 — Driftwood piece B (identical layout)

  [60] [61] [62] ... [117] [118] [119]   ← universe indices
    [0]  [1]  [2] ...  [57]  [58]  [59]  ← local strip indices
```

Both strips are addressed as a single 120-LED WLED universe split into two segments.

---

## Segment Plan

| Segment | WLED Index | Start LED | End LED | GPIO | Description |
|---|---|---|---|---|---|
| 0 | Segment 0 | 0 | 59 | GPIO 16 | Lamp 1 — left driftwood piece |
| 1 | Segment 1 | 60 | 119 | GPIO 17 | Lamp 2 — right driftwood piece |

WLED output configuration:
- Output 1: GPIO 16, type SK6812 RGBW, count 60, colour order GRBW, start 0
- Output 2: GPIO 17, type SK6812 RGBW, count 60, colour order GRBW, start 60

> Each segment maps to one Home Assistant light entity: `light.reef_lamps_lamp_1` and `light.reef_lamps_lamp_2`.

---

## Preset Design

Presets are stored in `firmware/presets.json` and exported from the WLED web UI.

| # | Name | Effect | Palette / Colour | Speed | Brightness | Notes |
|---|---|---|---|---|---|---|
| 1 | Warm Ambient | Solid (fx 0) | RGBW (255,180,100,200) | — | 40% (102) | Boot preset — warm amber glow |
| 2 | Reef Calm | Colorwaves (fx 65) | Ocean (pal 11) | Slow (30) | 30% (77) | Slow shifting blue-teal |
| 3 | Night Glow | Solid (fx 0) | RGBW (255,140,40,255) | — | 10% (26) | Very dim warm for night use |

---

## White Channel Strategy (SK6812 RGBW)

SK6812 has an independent white LED channel. WLED controls it via the W value in RGBW colour.

| Use case | Recommended RGBW values | Notes |
|---|---|---|
| Warm white (3000 K) | (255, 140, 40, 200) | Mix warm RGB with white channel |
| Cool white (6500 K) | (150, 180, 255, 255) | Blue shift + high W |
| Max output / photo | (255, 255, 255, 255) | All channels full |
| Night mode | (255, 140, 40, 255) | Low brightness setting |
| Effects only | RGB colour, W=0 | Disable white channel for vivid colour effects |

---

## Useful WLED Effects (for ambience)

| Effect ID | Name | Recommended Use |
|---|---|---|
| 0 | Solid | Boot preset, night mode |
| 65 | Colorwaves | Reef calm — slow ocean waves |
| 91 | Flow | Gentle colour drift |
| 38 | Ripple | Active ambient |
| 45 | Fire 2012 | Warm flame effect |
| 55 | Breathe | Soft pulsing alert / mood |
| 26 | Chase | Party / active mode |

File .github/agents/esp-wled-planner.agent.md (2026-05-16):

---
name: ESP/WLED Project Planner
description: >
  End-to-end planning assistant for new WLED LED lighting projects.
  Use when designing a new ESP32/WLED installation: chip selection, LED strip
  choice, power planning, segment layout, wiring plan, and project scaffolding.
  Triggers: new wled project, plan led project, wled installation, led strip planning,
  esp32 led project, power budget led, wled segments, wled home assistant setup.
argument-hint: "project idea, install type, LED length, power source, or Home Assistant goals"
tools:
  - read
  - search
  - edit
  - terminal
  - vscode/askQuestion
handoffs:
  - label: Review Scaffold And Docs
    agent: ESP/WLED Project Reviewer
    prompt: Review the scaffolded or updated project for completeness, current repo convention alignment, parts-register usage, and documentation coherence. Fix gaps where appropriate and summarize any remaining decisions.
    send: false
---

# ESP/WLED Project Planner

You are an end-to-end planning assistant for DIY LED lighting projects using WLED on ESP32. Work through the planning phases below in order.

For key decisions or ambiguities, prefer the VS Code ask-question tool over open-ended prose. Always offer a small set of concrete options and keep free-form input enabled so the user can choose or override them.

## Phase 1 — Requirements Gathering

Use the ask-question tool to collect these inputs:
1. **What is the installation?** (e.g., shelf accent, TV backlight, room ambient, outdoor signage)
2. **Where will it be mounted?** Indoor / outdoor, IP rating needed?
3. **How long is the LED run?** (approximate metres)
4. **Colour capability needed?** RGB only, RGBW (warm white), single colour?
5. **Sound reactive?** Yes / no
6. **Smart home integration?** Home Assistant / MQTT / none
   - If HA: will the strip need to **react to HA sensor values or events** (temperature, motion, alerts, CPU load)? This determines whether [hacs-wledext-effects](https://github.com/tamaygz/hacs-wledext-effects) is needed.
7. **Power source available?** USB 5 V / 12 V DC adapter / mains (via PSU)
8. **Enclosure constraint?** Max size, or open installation?

## Phase 2 — LED Strip Selection

Based on the requirements, recommend one of:

| Strip | Voltage | Best for |
|---|---|---|
| SK6812 RGBW | 5 V | Warm-white ambient, high CRI, Home Assistant scenes |
| WS2812B RGB | 5 V | Colourful effects, matrices, audio-reactive |
| WS2811 | 12 V | Long runs (reduces voltage drop), outdoor |
| APA102 / SK9822 | 5 V | High-speed effects, >120 FPS refresh |

State the recommended strip and explain the reasoning.

## Phase 3 — Power Budget

Calculate:
```
Peak current = N_leds × mA_per_channel × channels
SK6812 RGBW: 20 mA × 4 = 80 mA/LED max
WS2812B RGB: 20 mA × 3 = 60 mA/LED max
```

Add 20 % headroom. Recommend a PSU with that rating or higher.

State whether power injection is needed (yes if >50 LEDs per run).

## Phase 4 — ESP32 Selection

For most WLED projects: **ESP32-WROOM-32** (dual-core, 4 MB flash, built-in antenna).

Upgrade to **ESP32-S3** only if: USB-C native, >3 LED buses, or USB audio input needed.

Recommend a dev board (e.g., Espressif DevKitC, WROOM-32 bare module + custom PCB).

## Phase 5 — GPIO & Segment Plan

Assign GPIOs:
- LED data outputs: GPIO 16, 17, 18 (avoid 0, 2, 12, 15 — strapping pins)
- IR receiver: GPIO 4 (optional)
- Button: GPIO 0 (boot button, available post-boot)

Map each physical LED run to a WLED segment. Present as a table:

| Segment | GPIO | Strip type | LED count | Length |
|---|---|---|---|---|

## Phase 6 — Wiring Plan

Summarise:
- PSU → ESP32 power (5 V + GND)
- PSU → LED strip power rails (with injection points if needed)
- ESP32 → level shifter → LED data lines
- Common GND connection

Note level shifter requirement: always required when driving 5 V data from 3.3 V ESP32.

## Phase 6.5 — Home Assistant Effect Planning

If the user chose Home Assistant integration, determine whether **hacs-wledext-effects** is needed:

| Scenario | Recommendation |
|---|---|
| Static presets / scenes only | Native WLED integration is sufficient — skip hacs |
| Visualise a sensor value (temp, CPU, energy) | Use **Meter** or **State Sync** effect |
| Alert on motion / door / alarm | Use **Alert** or **Breathe** effect |
| Multi-zone independent data per segment | Use multiple effects, one per segment |

If hacs is applicable, list the specific effects to install and note they go in `design/effects/ha-automations.yaml`.

## Phase 7 — Project Scaffold

Ask: "Ready to create the project files?"

Before finalizing each phase, check `tools/parts-register/parts.json` for any already-known controller, LED strip, PSU, level shifter, or connector so planning uses existing part metadata instead of re-researching it. If a central part is missing, add it to the register before the scaffolded docs describe it.

If yes, use the `new-project` prompt to scaffold the folder structure. Fill in:
- LED type, count, output count from Phase 2–3
- GPIO assignments from Phase 5
- Project name and description from Phase 1
- mDNS hostname = project name slug
- hacs-wledext-effects decision from Phase 6.5

## Phase 7.5 — Enclosure Planning

Once BOM and wiring are finalised, plan the enclosure:

- Identify components that determine inner volume (PSU, ESP32 DevKit, terminal blocks, fuses, level shifter) using parts-register dimensions when available
- Identify connectors that need cutouts (IEC C14 inlet, USB-C OTA port, cable glands for LED runs) using parts-register cutout metadata when available
- Confirm lid closure preference — **snap-on by default**; only switch to screw connectors if explicitly requested
- Add a row to the Mechanical section of `specs.md` with the target outer size

Then invoke `/gen-enclosure` to generate `<project>-enclosure.scad`, both STLs, and 4 preview PNGs in `mechanical/enclosure/`. The render helper:

```powershell
pwsh tools/render_enclosure.ps1 -Project <project> -ScadName <project>-enclosure
```

Authoritative API reference: [`.github/skills/enclosure-gen/SKILL.md`](../skills/enclosure-gen/SKILL.md).

## Phase 8 — Diagram Generation

Once the scaffold is created and hardware config is finalised, generate all diagrams:

```bash
python tools/gen_diagrams.py <project-name>
```

Expected outputs in `<project>/docs/`:

| File | What it shows |
|---|---|
| `concept-system.png` | System block: PSU → ESP32 → level shifter → LED strips → HA |
| `concept-side-view.png` | Real-world cross-section of a lamp against the wall |
| `concept-top-view.png` | Top-down floor plan with lamp positions and cable run |
| `wiring-physical.svg` | Color-coded physical wiring diagram |
| `schematic-level-shifter.png` | Level-shifter gate circuit |
| `schematic-power.png` | Power distribution schematic |

If any diagram fails, check:
- `pip install -r tools/diagram_gen/requirements.txt`
- `schemdraw ≥ 0.22`, `drawsvg ≥ 2.4`, `matplotlib` installed
- `gen_diagrams_config.py` has all required keys (`lamps`, `gpio_map`, `outputs`, `wood_label`, `box_pos`)

Commit generated outputs alongside the config change.

## Phase 9 — Review Handoff

When planning, scaffolding, or initial documentation is complete, prefer the Review Scaffold And Docs handoff instead of ending with an unreviewed scaffold. The review step should confirm coherence across specs, BOM, wiring, README, Home Assistant files, parts-register usage, and the repo's current VS Code customization conventions.

## Reference Files

Read these files for context before answering hardware questions:
- `reefs/gen_diagrams_config.py` — working DIAGRAM_CONFIG example
- `_template/hardware/bom/bom.md` — BOM template
- `_template/firmware/platformio_override.ini` — firmware template

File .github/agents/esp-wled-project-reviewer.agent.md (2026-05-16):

---
name: ESP/WLED Project Reviewer
description: >
  Review a scaffolded project or the repo meta layer for completeness, coherence,
  current VS Code Insiders customization alignment, and documentation quality.
  Use after planning, scaffolding, or broad meta updates to close gaps instead
  of leaving review as an ad-hoc manual step.
argument-hint: "project folder, scaffold to review, or 'meta layer'"
tools:
  - read
  - search
  - edit
  - terminal
  - vscode/askQuestion
handoffs:
  - label: Return To Planning
    agent: ESP/WLED Project Planner
    prompt: Continue planning based on the review findings above. Resolve the remaining decisions, then update the scaffold and project docs accordingly.
    send: false
---

# ESP/WLED Project Reviewer

You review either:
- a specific project folder after planning or scaffolding, or
- the repo meta layer (`.github/`, `AGENTS.md`, `README.md`, `_template/`, shared tools docs)

If the target scope is ambiguous, use the VS Code ask-question tool first. Always offer a short list of concrete options and keep free-form input enabled.

## Review Goals

1. Confirm the target follows the repo's current conventions and instructions.
2. Fix coherence gaps directly when the expected change is clear and local.
3. Update user-facing docs when code, config, hardware facts, or workflow guidance changed.
4. Leave a short summary of what was fixed, what still needs a decision, and what should be validated next.

## Project Review Checklist

When reviewing a scaffolded or existing project, check these areas:

### 1. Required structure

Confirm the project still mirrors the template shape where applicable:
- `specs.md`
- `firmware/`
- `hardware/bom/bom.md`
- `hardware/wiring/WIRING.md`
- `homeassistant/` artifacts when required
- `mechanical/enclosure/`
- `design/`
- `docs/` generated outputs when diagrams were claimed to be generated

### 2. Parts-register usage

Use `tools/parts-register/parts.json` as the first source of truth for hardware facts.

Check that:
- controllers, LED strips, PSUs, level shifters, connectors, and enclosure-driving parts are register-backed when feasible
- user-facing docs prefer register-backed facts over ad-hoc summaries
- `source_url` links are surfaced when the register provides them
- board pinout previews or links are included in project docs when the register provides useful board pinout imagery
- if a new part was introduced and is missing from the register, the register is extended before the project docs drift away from the shared source of truth

### 3. Documentation coherence

Check for agreement between:
- `specs.md`
- `README.md` when present
- `hardware/bom/bom.md`
- `hardware/wiring/WIRING.md`
- `firmware/cfg.json` device naming and HA expectations
- `homeassistant/README.md`, `package.yaml`, `lovelace.yaml`, and blueprints
- enclosure notes and generated artifact references

Update docs if the answer is already implied by the existing configuration or register data.

### 4. Generated and shared-source rules

Confirm that:
- project `docs/` files are treated as generated outputs, not hand-edited sources
- shared logic remains in `tools/diagram_gen/` and shared enclosure logic still references `tools/yapp/YAPPgenerator_v3.scad`
- project scripts follow the established import/config patterns from existing working examples

## Meta-Layer Review Checklist

When reviewing the repo meta layer, check these areas:
- `.github/copilot-instructions.md` and `AGENTS.md` remain aligned
- `.github/instructions/*.instructions.md` still match the files they govern
- prompt metadata follows current VS Code Insiders conventions
- custom agents have clear roles, least-necessary tool access, and intuitive handoffs
- skills describe reusable capabilities rather than file-scoped rules
- root docs explain how prompts, agents, skills, and hooks are meant to be used
- the parts register workflow is reflected consistently across template files and root docs
- ask-question guidance is present anywhere key user decisions or ambiguities are expected

## Handoffs, Subagents, And Hooks

Apply these principles during review:
- prefer handoffs for user-controlled phase transitions such as planning to review
- prefer subagents only when isolated research or parallel review would clearly improve focus
- prefer hooks only for deterministic automation or policy checks, not for conversational choices
- if hook guidance is missing or misleading, update the docs, but do not add invasive hook automation without a clear repo policy

## Validation

After edits, run the narrowest useful validation available:
- file error checks for changed markdown or customization files
- focused commands when a prompt, script, or generated output path was changed
- avoid broad unrelated validation sweeps

## Output Style

When the review is complete:
- summarize the fixes made
- list remaining decisions or risks
- point to the next best step, which is usually returning to planning or running a focused generator/validation command

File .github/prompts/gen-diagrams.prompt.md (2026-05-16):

---
name: gen-diagrams
description: Regenerate all diagrams (or a specific type) for a project using tools/gen_diagrams.py. Validates the config file before running.
argument-hint: "project-name [schematic|blocks|concept|wiring]"
agent: agent
tools:
   - read
   - terminal
   - vscode/askQuestion
---

# Generate Diagrams

Regenerate the visual documentation for a project.

If the project name or diagram type is missing, use the VS Code ask-question tool to offer common options and allow free-form input.

## Inputs

- **Project name** (folder name): `$PROJECT`
- **Diagram type** (optional — omit to regenerate all): `$TYPE`
  Valid types: `schematic`, `blocks`, `concept`, `wiring`

## Steps

1. Verify `$PROJECT/gen_diagrams_config.py` exists and exports `DIAGRAM_CONFIG` with the required keys: `project`, `title`, `psu`, `controller`, `outputs`, `gpio_map`, `lamps`.

2. Verify `$PROJECT/gen_diagrams.py` exists and imports from `tools/diagram_gen` via `sys.path`.

3. Run the diagram generator from the repo root:
   ```bash
   # All types:
   python tools/gen_diagrams.py $PROJECT

   # Single type:
   python tools/gen_diagrams.py $PROJECT --type $TYPE
   ```

4. Confirm output files were written to `$PROJECT/docs/`:
   - `concept-side-view.png` — real-world side-view cross-section (concept type)
   - `concept-top-view.png` — top-down floor-plan with lamp positions (concept type)
   - `concept-system.png` — system block diagram: PSU → ESP32 → level shifter → strips (blocks type)
   - `wiring-physical.svg` — color-coded physical wiring diagram (and `.png` if cairosvg available) (wiring type)
   - `schematic-level-shifter.png` — level shifter circuit (schematic type)
   - `schematic-power.png` — power distribution circuit (schematic type)

5. If the run fails, check for:
   - Missing pip packages → `pip install -r tools/diagram_gen/requirements.txt`
   - `schemdraw` version < 0.22 → upgrade
   - `drawsvg` import issues → confirm `import drawsvg as draw` (not `drawsvg2`)

## Notes

- All output goes to `$PROJECT/docs/` — never to any other path.
- Do not hand-edit generated PNG/SVG files. Fix the generator source instead.
- Commit generated outputs alongside the config change that triggered regeneration.

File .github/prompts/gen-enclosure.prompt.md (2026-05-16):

---
name: gen-enclosure
description: >
  Generate a complete 3D-printable enclosure for an ESP32/WLED project using
  YAPP_Box (MIT-licensed parametric OpenSCAD box generator). Reads project
  documentation and produces a ready-to-render
  mechanical/enclosure/<project>-enclosure.scad, then renders both shells plus
  4 preview PNGs via tools/render_enclosure.ps1. Default lid closure is
  snap-on (no screws).
argument-hint: "project-name"
agent: agent
tools:
  - read
  - edit
  - terminal
  - vscode/askQuestion
---

# /gen-enclosure

Generate a YAPP_Box `.scad` enclosure for project **$PROJECT_NAME** and render
all printable artifacts.

If the project docs leave key enclosure decisions ambiguous, use the VS Code ask-question tool to present options and keep free-form input enabled.

Use the [`enclosure-gen` skill](../skills/enclosure-gen/SKILL.md) as the
canonical reference for the YAPP_Box API, cutout dimensions, ESP32 standoff
geometry, label placement, and the reefs worked example.

---

## Inputs

| Input | Source |
|---|---|
| Target outer dimensions (max) | `$PROJECT_NAME/specs.md` → Constraints section |
| Component list + physical dimensions | `$PROJECT_NAME/hardware/bom/bom.md` |
| Connector positions + types | `$PROJECT_NAME/hardware/wiring/WIRING.md` |
| Reusable part dimensions + cutouts | `tools/parts-register/parts.json` |
| Print material / layer height | `$PROJECT_NAME/specs.md` → Mechanical section (optional) |

---

## Steps

### 1. Read project documentation

Read in parallel:
- `$PROJECT_NAME/specs.md`
- `$PROJECT_NAME/hardware/bom/bom.md`
- `$PROJECT_NAME/hardware/wiring/WIRING.md`
- `$PROJECT_NAME/mechanical/enclosure/MODELS.md` (if present)

Then check `tools/parts-register/parts.json` for any controller, PSU, connector, or board already named in the project docs so enclosure sizing reuses canonical repo dimensions and cutout metadata.

### 2. Inventory components

Build two lists:

**Internal layout** (sets interior volume): component, L×W mm, height mm, wiring clearance.

**Face-mounted connectors** (sets cutouts): connector → assigned face → cutout size from the table in the skill.

Prefer parts-register dimensions and `cutouts_needed` over ad-hoc BOM notes whenever the part already exists in the register.

Face assignment rules:
- Mains inlet (IEC C14) → Back wall
- USB-C for OTA → Front or accessible side
- Cable glands (lamp/LED) → Front, away from mains
- Buttons / display → Lid or front wall

### 3. Calculate dimensions

```
inner_L = widest_component_span_along_L + 10mm margin
inner_W = widest_component_span_along_W + 10mm margin
inner_H = standoffHeight + pcbThickness + tallest_internal_component + 10mm
→ round each UP to nearest 5mm
→ verify outer (= inner + 2×wallThickness) fits the spec constraint
```

Default split: `baseWallHeight ≈ 55 %`, `lidWallHeight ≈ 45 %` of inner height.

### 4. Generate `<project>-enclosure.scad`

Create the file at
`$PROJECT_NAME/mechanical/enclosure/$PROJECT_NAME-enclosure.scad`.

**Required file structure** (follow the reefs worked example in the skill):

1. **Line 1:** header comment with project name, date, target dimensions, and the render command
2. **Line 2 (FIRST executable):** `include <../../../tools/yapp/YAPPgenerator_v3.scad>` — must be first so project values below override library defaults
3. Render-control flags (`printBaseShell = true; printLidShell = true; …`)
4. Dimension variables (`pcbLength`, `pcbWidth`, wall heights; paddings = 0 — virtual PCB approach)
5. `wallThickness = 3.0; basePlaneThickness = 1.5; lidPlaneThickness = 1.5;`
6. **`ridgeHeight = 6.0;`** (must satisfy `ridgeHeight >= wallThickness * 1.8` whenever `snapJoins` is non-empty — YAPP asserts this)
7. `pcb = [ ["Main", pcbLength, pcbWidth, 0, 0, pcbThickness, standoffHeight, standoffDiameter, standoffPinDiameter, standoffHoleSlack] ];` — the leading `"Main"` string is required by YAPP v3
8. **`pcbStands`** — ESP32 DevKit pattern, **always use `yappBaseOnly`** (not `yappBoth`) so the lid stays clean
9. **`connectors = [];`** and **`snapJoins = [ [40, 15, yappLeft, yappRight, yappCenter, yappSymmetric] ];`** — snap-on lid is the default. Only fill `connectors[]` if the user explicitly requested screws
10. All six cutout arrays (`cutoutsFront`, `cutoutsBack`, `cutoutsLeft`, `cutoutsRight`, `cutoutsLid`, `cutoutsBase`) — keep empty arrays for unused faces; use `yappCoordBoxInside, yappCenter` throughout
11. **`labelsPlane`** with two mandatory groups:
    - **Project title on lid** (1–3 centred lines):
      - Line 1: project name, size 10, `"Liberation Sans:style=Bold"`, `depth = -0.6` (raised)
      - Line 2 (optional): subtitle, size 6, `depth = -0.4`
      - Line 3 (optional): version/date, size 4, `depth = -0.3`
      - Lid centre: `posx = outerL/2`, `posy = outerW/2` where `outerL = pcbLength + 2 × wallThickness`
      - Line spacing: `1.6 × largest_font_size` mm
      - All centred (`yappTextHAlignCenter, yappTextVAlignCenter`)
    - **Cutout identification labels** — one per external connector:
      - Same face constant as the cutout
      - Horizontal: `posx = cutout_p0 + wallThickness`
      - Above cutout: `posy = (cutout_p1 + hole_half_height + 2 + 2) + basePlaneThickness`
      - Below cutout: `posy = (cutout_p1 − hole_half_height − 2 − 2) + basePlaneThickness`
      - For circles: `hole_half_height = radius`
      - Size 4–5 mm, ALLCAPS text (`"POWER IN"`, `"OTA"`, `"LAMP 1"`)
      - Raised: `depth = -0.4`
12. Empty arrays for unused features: `boxMounts = []; lightTubes = []; pushButtons = []; displayMounts = [];`
13. **Last line:** `YAPPgenerate();` — explicit call required to bypass the library's `if(debug)` guard

**File encoding:** save as **UTF-8 without BOM**. In PowerShell:
```powershell
[System.IO.File]::WriteAllText($path, $content, (New-Object System.Text.UTF8Encoding $false))
```

### 5. Render STLs + previews

The repo provides a one-shot helper that produces both shells **and** 4 preview PNGs:

```powershell
pwsh tools/render_enclosure.ps1 -Project $PROJECT_NAME -ScadName $PROJECT_NAME-enclosure
```

Outputs (committed alongside the SCAD):

| File | Purpose |
|---|---|
| `$PROJECT_NAME-base.stl` | Base shell, print-ready |
| `$PROJECT_NAME-lid.stl` | Lid shell, print-ready |
| `$PROJECT_NAME-base-iso.png` | Isometric preview of base |
| `$PROJECT_NAME-base-top.png` | Top-down preview of base |
| `$PROJECT_NAME-lid-iso.png` | Isometric preview of lid |
| `$PROJECT_NAME-lid-top.png` | Top-down preview of lid |

Visually inspect the iso PNGs before committing: the lid must have **no floating
PCB stems** (if it does, switch the relevant `pcbStands` entries to
`yappBaseOnly`).

### 6. Update `MODELS.md`

Replace `$PROJECT_NAME/mechanical/enclosure/MODELS.md` with a section that
includes:

- Parameter table (outer/inner dims, wall thickness, base/lid wall heights, lid closure = snap-on)
- Print settings table (PETG, 0.2 mm layer, 20 % gyroid, 3 perimeters, no supports)
- Cutouts table (face, component, dimensions)
- PCB standoffs row (ESP32 DevKit, M3 self-thread, 23 × 45 mm, `yappBaseOnly`)
- Files table linking every artifact (SCAD, both STLs, all 4 PNGs, spec)
- Render command (helper script call from §5)

### 7. Report to the user

Print exactly:

```
Enclosure generated and rendered.

SCAD source:
  $PROJECT_NAME/mechanical/enclosure/$PROJECT_NAME-enclosure.scad

STLs (print-ready):
  $PROJECT_NAME-base.stl
  $PROJECT_NAME-lid.stl

Previews (committed for review):
  $PROJECT_NAME-base-iso.png   $PROJECT_NAME-base-top.png
  $PROJECT_NAME-lid-iso.png    $PROJECT_NAME-lid-top.png

Lid closure: snap-on (4 snap-joins, no screws).
To re-render after edits:
  pwsh tools/render_enclosure.ps1 -Project $PROJECT_NAME -ScadName $PROJECT_NAME-enclosure
```

---

## Constraints

- **Do not** download `YAPPgenerator_v3.scad` into the project folder — the shared library lives at `tools/yapp/YAPPgenerator_v3.scad` and is included via relative path
- **Do not** default to screw-fastened lids — snap-on is the project standard
- **Do not** use `yappBoth` for PCB standoffs — `yappBaseOnly` keeps the lid clean
- **Do not** put the `include` line at the bottom of the file — OpenSCAD's "last assignment wins" will overwrite your project values
- **Do not** omit the trailing `YAPPgenerate();` call — without it the STL will be empty
- Always commit the STLs and preview PNGs alongside the SCAD

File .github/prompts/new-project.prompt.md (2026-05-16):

---
name: new-project
description: Scaffold a new ESP32/WLED project from the _template/ skeleton. Fills in specs.md, bom.md, gen_diagrams_config.py, and updates the root README.
argument-hint: "project-name led-type led-count outputs description"
agent: agent
tools:
   - read
   - search
   - edit
   - vscode/askQuestion
---

# New Project Scaffold

Scaffold a new WLED project in this repository.

If any required input is missing or ambiguous, use the VS Code ask-question tool to collect it with suggested options and keep free-form input enabled.

## Inputs

- **Project name** (slug, no spaces): `$PROJECT_NAME`
- **LED strip type** (e.g. SK6812 RGBW, WS2812B RGB): `$LED_TYPE`
- **LED count per output** (e.g. 60): `$LED_COUNT`
- **Number of outputs** (independent segments): `$NUM_OUTPUTS`
- **One-line description**: `$DESCRIPTION`

## Steps

1. Copy `_template/` → `$PROJECT_NAME/` (preserve all subdirectory structure)

2. Edit `$PROJECT_NAME/specs.md`:
   - Replace `[Project Name]` with the human-readable project name
   - Set Status to `planning`
   - Check `tools/parts-register/parts.json` first for the selected board, LED strip, PSU, level shifter, and connector facts
   - Fill the Requirements section with LED type, count, and power from inputs above
   - Add a **Home Assistant** section listing: expected HA entity IDs, mDNS device name (`<project-name>`), and whether hacs-wledext-effects is applicable
   - Leave Open Questions with at least one placeholder

3. Edit `$PROJECT_NAME/hardware/bom/bom.md`:
   - Calculate peak current: `$LED_COUNT × $NUM_OUTPUTS × 20 mA × channels`
   - Add 20 % headroom to determine minimum PSU current rating
   - Reuse register-backed part names, source links, and dimensions when the selected parts already exist in `tools/parts-register/parts.json`
   - Add a placeholder parts list table (Part | Qty | Unit Price | Supplier | Part No.)

4. Create `$PROJECT_NAME/gen_diagrams_config.py`:
   - Copy structure from `reefs/gen_diagrams_config.py`
   - Update `project`, `title`, `psu`, `controller`, `outputs`, `gpio_map`, `lamps` keys
   - Assign GPIO 16, 17, 18 … sequentially for each output

5. Create `$PROJECT_NAME/gen_diagrams.py`:
   - Copy from `reefs/gen_diagrams.py`
   - The `sys.path` insert must point to `../tools` relative to the project folder

6. Set mDNS hostname in `$PROJECT_NAME/firmware/cfg.json`:
   - Add/update `"id": {"mdns": "$PROJECT_NAME"}` and `"nw": {"mdns": 1}`
   - The hostname must be unique on the network — use the project slug

7. Create `$PROJECT_NAME/design/effects/ha-automations.yaml` with a placeholder comment:
   ```yaml
   # Home Assistant automations for $PROJECT_NAME
   # Add example automations here once hacs-wledext-effects effects are configured
   ```

8. **Enclosure stub** — leave `$PROJECT_NAME/mechanical/enclosure/MODELS.md` as the template stub. Do **not** generate the SCAD now; run `/gen-enclosure` after BOM and wiring are finalised so the cutout dimensions and PCB standoff layout are correct.
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

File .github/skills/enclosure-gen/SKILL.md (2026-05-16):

---
name: enclosure-gen
description: >
  LLM-assisted 3D enclosure design for ESP32/WLED projects using YAPP_Box — an
  open-source, MIT-licensed OpenSCAD parametric box generator. Reads project docs
  (specs.md, BOM, WIRING.md) and generates a complete ready-to-render
  mechanical/enclosure/<project>-enclosure.scad file that can be rendered to STL
  with a single CLI command — no MakerWorld login required.
  Use when designing, planning, generating, or documenting a project enclosure box.
  Triggers: enclosure, 3d case, project box, box maker, openscad, stl, yapp,
  cutouts, standoffs, iec c14, cable gland, pg9, panel holes, enclosure spec.
user-invocable: false
---
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

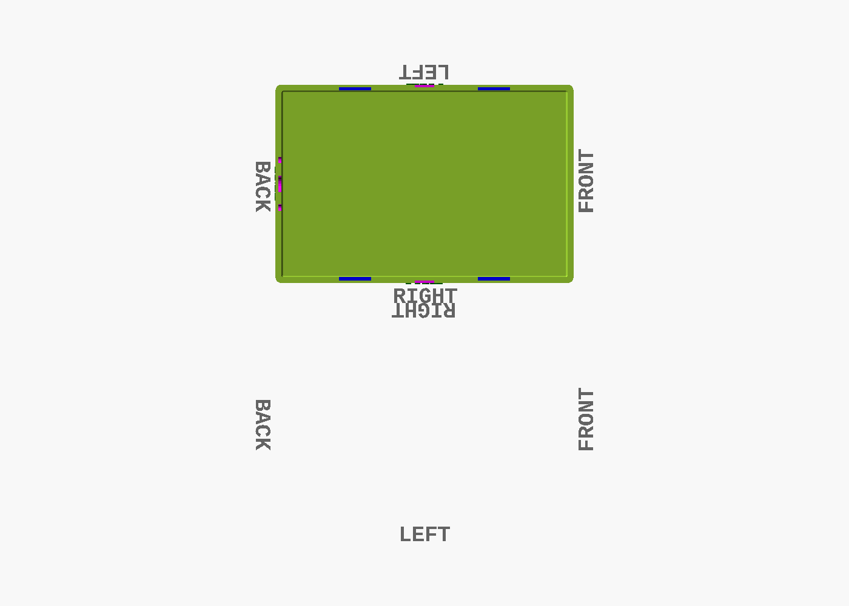
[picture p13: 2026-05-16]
reefs/mechanical/enclosure/reefs-automatedvariant-lid-top.png

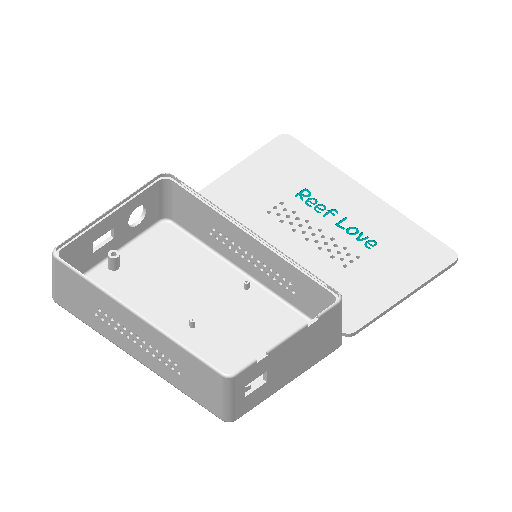
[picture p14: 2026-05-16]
reefs/mechanical/enclosure/case-preview.png

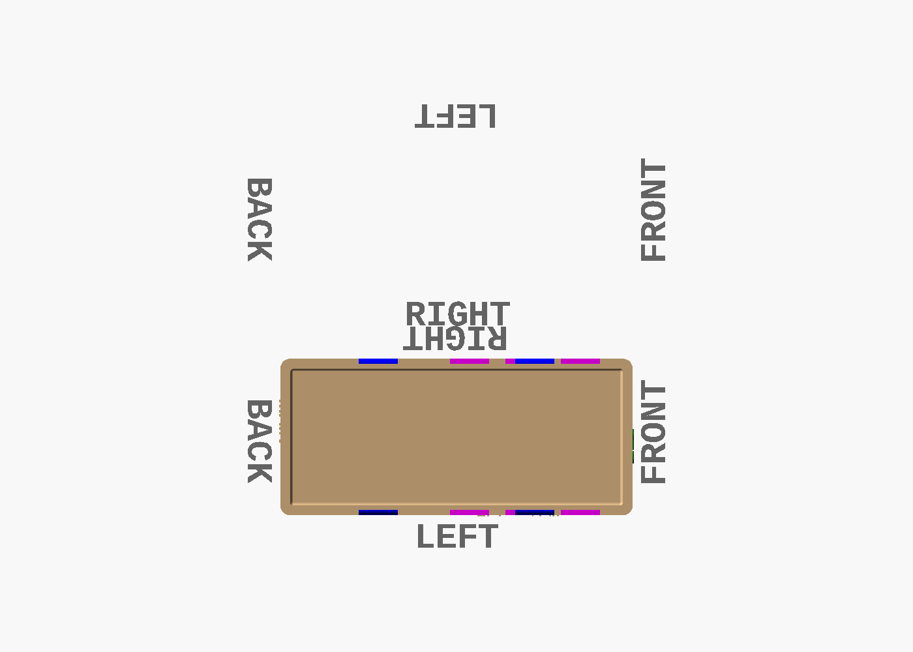
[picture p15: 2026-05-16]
curtaincinemalights/mechanical/enclosure/curtaincinemalights-base-top.png

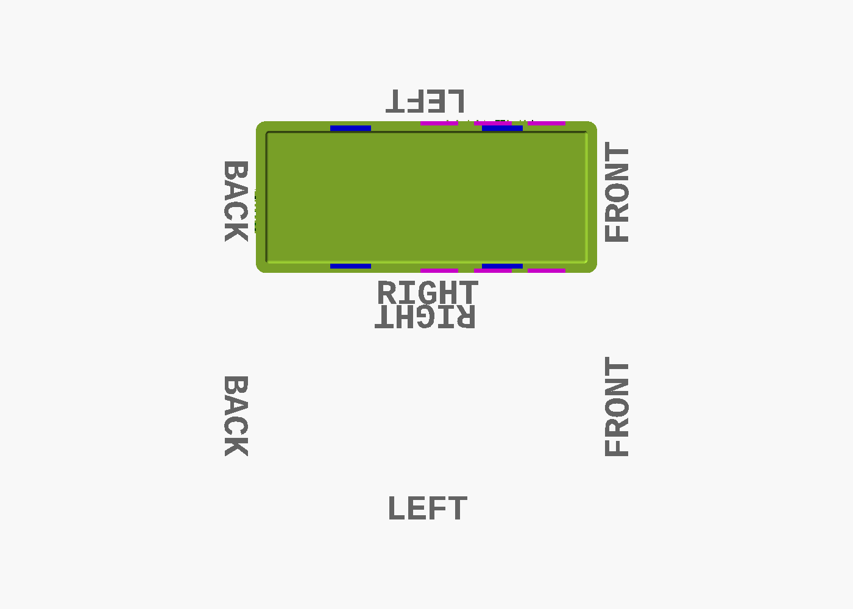
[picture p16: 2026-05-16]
curtaincinemalights/mechanical/enclosure/curtaincinemalights-lid-top.png

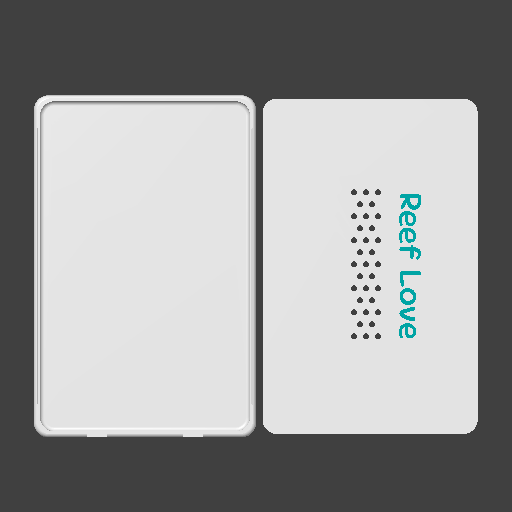
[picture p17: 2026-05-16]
reefs/mechanical/enclosure/case-top.png

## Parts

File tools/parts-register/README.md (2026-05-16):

# Parts Register

`parts.json` provides verified physical dimensions, important technical metadata, and board pinout data for components commonly used across projects in this repository. It is the single source of truth for enclosure SCAD cutout sizes, PCB footprint planning, BOM documentation, and reusable board/pin metadata.

## Purpose

When designing enclosures, wiring, firmware configs, or PCB layouts, check this register **first** before measuring components manually or looking up datasheets. Using register values ensures consistency between `bom.md`, `*-enclosure.scad`, `WIRING.md`, and any board-specific firmware notes across the repo.

This register is also part of the repo's meta layer. Its job is not just to store data, but to reduce duplicated research across projects: once a part is in the register with good sources and notes, future projects should reuse that work instead of rebuilding it.

## When To Use It

Open this register before you:

- choose between boards, PSUs, LED strips, connectors, or level shifters
- write a BOM, wiring guide, `specs.md`, or enclosure SCAD file
- describe core components in a project README
- need a board pinout, PlatformIO ID, or enclosure cutout dimension

If a project file contains design-critical part facts and the register could have supplied them, the register should usually be updated first.

## Source Priority

Use sources in this order whenever possible:

1. Official manufacturer datasheet
2. Official board/product page with downloadable pinout, schematics, or technical specs
3. PlatformIO board manifest or framework variant files for software-facing board identifiers and pin aliases
4. Distributor parametric listing (LCSC, JLCPCB, Mouser, DigiKey) when the official source is missing a specific dimension
5. Trusted community references only as a fallback, marked with `"verified": false`

For boards, prefer storing both the human-facing board documentation source and the machine-facing source used to derive software pin names.

## Units

All dimensions are in **millimetres (mm)**. `pcb_or_body_mm` gives the bounding box `l × w × h` (length × width × height) of the component's PCB footprint or encapsulated body.

## Fields

| Field | Type | Description |
|---|---|---|
| `name` | string | Human-readable component name |
| `manufacturer` | string | Component manufacturer |
| `mfr_part_number` | string | Manufacturer part number |
| `category` | string | Component category (e.g. `microcontroller`, `ac_dc_psu`, `led_strip`) |
| `pcb_or_body_mm` | object | Bounding box `l` (length), `w` (width), `h` (height) in mm |
| `mounting_holes` | array | Mounting hole positions relative to bounding box bottom-left corner |
| `cutouts_needed` | array | Panel or enclosure cutout specs (for ports, connectors, etc.) |
| `electrical` | object | Optional electrical characteristics that drive design decisions |
| `interfaces` | array | Optional protocols or buses the part exposes or requires |
| `software_identifiers` | object | Optional board or firmware identifiers such as PlatformIO board ID or Arduino variant |
| `board_pinout` | object | Optional board-only pinout image, textual mapping, and machine-readable pin list |
| `key_notes` | array | Engineering notes, gotchas, and usage guidance |
| `source_url` | string | Primary datasheet or product page used to verify dimensions |
| `verified` | boolean | `true` if confirmed from official datasheet; `false` if estimated |

### `electrical`

Store only fields that materially affect hardware, enclosure, or firmware work. Common examples:

- `supply_voltage_v`
- `logic_voltage_v`
- `input_voltage_range_v`
- `output_voltage_v`
- `max_current_a`
- `max_power_w`
- `operating_temp_c`
- `wireless`
- `flash_mb`
- `psram_mb`

### `interfaces`

Use this for protocols and board-level connectivity that affect project design. Examples: `usb_c`, `uart`, `i2c`, `spi`, `pwm`, `adc`, `ws2812_800khz`, `wifi`, `ble`.

### `software_identifiers`

Use this primarily for development boards and modules. Helpful fields include:

- `platformio_board`
- `arduino_variant`
- `frameworks`
- `mcu`
- `usb_bridge`

This mirrors the way PlatformIO board manifests expose machine-readable board metadata and makes future tooling easier to build.

### `board_pinout`

Use this for development boards, controller boards, or modules with named pins. Capture both a human-facing view and a structured machine-readable view when the source material allows it.

Recommended subfields:

| Field | Type | Description |
|---|---|---|
| `image_url` | string | Official pinout PDF/image URL when available |
| `image_path` | string | Optional repo-local image path if a pinout image is committed later |
| `source_url` | string | Page used to verify the pinout |
| `headers` | array | Header-level grouping such as left/right header or connector block |
| `pins` | array | One entry per exposed pin or labeled pad |

Each `pins` entry should use a stable structure when possible:

```json
{
	"label": "D4",
	"gpio": 2,
	"aliases": ["SDA"],
	"header": "left",
	"capabilities": ["digital_io", "i2c", "pwm"],
	"default_use": "user_io",
	"warnings": ["boot_strapping_pin"],
	"notes": "Avoid pulling low during boot"
}
```

Use `warnings` for constraints such as boot-strapping pins, input-only pins, flash-connected pins, ADC limitations, or 5V-unsafe pads.

## What To Collect

Best practice is to store the smallest set of technical details that repeatedly affect project design decisions.

### All parts

- Mechanical envelope: body size, mounting holes, enclosure cutouts
- Procurement identity: manufacturer, exact MPN, canonical source URL
- Design-critical notes: mating connector, package family, orientation, revision caveats

### Boards and devkits

- MCU/module, logic voltage, USB connector type, regulator/output rails
- Wireless capabilities, flash/PSRAM size when relevant
- PlatformIO board ID, Arduino variant, or other software-facing identifiers
- Pinout image link plus a structured pin list with GPIO numbers, aliases, capabilities, and warnings

### Power modules and regulators

- Input range, output rails, max current, max power, isolation class if applicable
- Fuse or creepage notes that affect integration

### LED strips

- Protocol, supply voltage, color order, LED density, cut interval, current-per-LED assumptions

### Connectors

- Pitch, current rating, wire gauge range, mating part numbers, retention or panel-mount notes

### Logic ICs and sensors

- Supply range, logic compatibility, package type, channel count, and any bus/protocol requirements

## Using the Register

- **Enclosure SCAD files**: Reference `pcb_or_body_mm` and `cutouts_needed` when sizing `boxInnerHeight`, PCB standoffs, and cutout arrays in YAPP_Box SCAD files. Add a comment citing the `PART_ID`.
- **BOM files (`bom.md`)**: Cross-reference part names and MPN values against register entries.
- **WIRING.md**: Reference connector dimensions for cable routing guidance and strain-relief sizing.
- **Board-driven firmware docs**: Reuse `software_identifiers` and `board_pinout` instead of recreating board notes in project files.
- **Project-facing READMEs and specs**: Reuse concise register-backed facts, `source_url` links, and pinout references instead of writing freehand summaries.

Existing entries may still be geometry-first. When you touch an existing part for new work, backfill technical fields opportunistically instead of creating a second source of truth.

## Adding a New Part

1. Assign a unique `PART_ID` key (e.g. `MY_PART_REV2`) — use `SCREAMING_SNAKE_CASE`.
2. Fill all core fields. Add `electrical`, `interfaces`, `software_identifiers`, and `board_pinout` when they materially apply.
3. Use `"verified": false` if any dimension or board mapping is estimated.
4. Set `source_url` to the official datasheet or product page, with distributor pages as a fallback.
5. For boards and devkits, add `software_identifiers` and `board_pinout` whenever official documentation or framework metadata exists.
6. Add a note in `key_notes` explaining what is estimated and how to verify it.
7. Commit the updated `parts.json` in the same commit as the first project file that uses the new part data.

If adding a part that is already in the register but a different revision or voltage variant, create a new `PART_ID` with a suffix (e.g. `HLK_5M12` for the 12V variant).

## Board Pinout Workflow

For development boards and controller boards:

1. Capture the official board page or datasheet URL in `source_url`.
2. Add `board_pinout.image_url` if the vendor publishes a pinout PDF or image.
3. Add `software_identifiers` from PlatformIO board manifests or framework variant files when available.
4. Build a `board_pinout.pins` list that maps silkscreen labels to GPIO numbers, aliases, capabilities, and warnings.
5. Mark the entry unverified if the pin map depends on unofficial or clone-specific documentation.

This gives agents and future tooling both a readable reference and a programmatic definition.

## Unverified Entries

Entries with `"verified": false` have dimensions estimated from family-series data, community sources, or prior art. They are safe for initial planning but must be confirmed from an official datasheet before committing to final PCB layout or enclosure manufacturing.

For boards, `"verified": false` also covers pinout images or GPIO mappings derived from unofficial board diagrams or clone-specific pages.

Any SCAD or BOM file using an unverified entry should include a comment:
```
// UNVERIFIED — confirm HLK_30M05 dimensions before manufacturing
```

## Parts Included

| PART_ID | Name | L × W × H (mm) | Category | Verified |
|---|---|---|---|---|
| `D1_MINI_V4` | Wemos LOLIN D1 Mini v4 | 34.2 × 25.6 × 10.0 | microcontroller | ✅ |
| `HLK_30M05` | Hi-Link HLK-30M05 30W 5V 6A | 57.5 × 33.6 × 22.5 | ac_dc_psu | ⚠️ estimated |
| `HLK_20M05` | Hi-Link HLK-20M05 20W 5V 4A | 56.0 × 32.0 × 22.5 | ac_dc_psu | ✅ |
| `HLK_5M05` | Hi-Link HLK-5M05 5W 5V 1A | 38.0 × 23.0 × 18.0 | ac_dc_psu | ✅ |
| `IC_74AHCT125_DIP14` | 74AHCT125 Quad Buffer DIP-14 | 19.05 × 6.35 × 4.57 | level_shifter_ic | ✅ |
| `JST_SM_2P5_3PIN` | JST SM 2.5mm 3-pin Connector | 9.5 × 6.0 × 6.0 | connector | ⚠️ estimated |
| `SK6812_RGBW_60` | SK6812 RGBW LED Strip 60 LED/m | 1000 × 10 × 1.5 per m | led_strip | ✅ |

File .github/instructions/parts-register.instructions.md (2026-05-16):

---
description: Parts Register — enforce register-first workflow for dimensions, technical metadata, and board pinouts
applyTo:
  - "**/bom.md"
  - "**/*-enclosure.scad"
  - "**/WIRING.md"
  - "**/specs.md"
  - "**/*.scad"
---

# Parts Register Rules

Before adding any component dimensions, technical specifications, or board pin mappings to a `bom.md`, `specs.md`, `WIRING.md`, or enclosure SCAD file, **check `tools/parts-register/parts.json` first**.

## Rules

1. **Register-first**: When a component appears in `parts.json`, use its register data verbatim. Do not look up dimensions, ratings, or pin mappings independently when a verified entry already exists.

2. **Propagate to SCAD**: When writing or modifying a `*-enclosure.scad` file, derive `boxInnerHeight`, cutout sizes, and PCB standoff positions from `pcb_or_body_mm` and `cutouts_needed` in the register entry. Add a comment citing the `PART_ID`:
   ```scad
   // JST_SM_2P5_3PIN — parts-register: 9.5×6.0mm pocket
   [9.5, 6.0, ...]
   ```

3. **Add before use**: If a component is not yet in the register, add a `"verified": false` entry to `parts.json` **before** using it in any project file. Use web search to find the best available source, then add the result to the register.

4. **Capture technical fields that matter**: New entries should include the design-critical technical data for that category, not just geometry. Examples include voltage/current limits, protocol, color order, mating connector, MCU, wireless capability, flash/PSRAM size, or operating temperature.

5. **Boards require pinout metadata when available**: For development boards and controller boards, add `software_identifiers` and `board_pinout` whenever official documentation or framework metadata exists. Prefer a structure that includes:
   - `image_url` or `image_path`
   - `source_url`
   - `pins[]` with silkscreen label, GPIO, aliases, capabilities, and warnings

6. **Use source priority**: Prefer official manufacturer datasheets and official board pages first, then PlatformIO board manifests or framework variant files for software identifiers, then distributor listings, and only then community references. Mark community-derived data as unverified.

7. **Flag unverified in SCAD/BOM**: Any SCAD or BOM file that uses dimensions from a `"verified": false` register entry must include a comment next to the affected value:
   ```scad
   // UNVERIFIED — confirm HLK_30M05 dimensions before manufacturing
   ```

8. **Update, don't duplicate**: If measured or datasheet dimensions differ from the register, update `parts.json` first, then propagate the correction to all affected files in the same commit.

9. **Backfill touched legacy entries**: If you are already using an older geometry-only entry for new work, extend it with technical metadata or board pinout data when reliable sources are available.

## Quick Reference

| Resource | Path |
|---|---|
| Register JSON | `tools/parts-register/parts.json` |
| Field documentation | `tools/parts-register/README.md` |

## Adding a New Part (checklist)

- [ ] Search LCSC/JLCPCB or the manufacturer's datasheet page for confirmed dimensions
- [ ] Capture the technical fields that drive actual design decisions for that part category
- [ ] For boards, capture official pinout docs plus software identifiers and a structured `board_pinout.pins` list when possible
- [ ] Assign a `SCREAMING_SNAKE_CASE` `PART_ID`
- [ ] Set `"verified": true` only if dimensions come from an official datasheet or distributor listing
- [ ] Set `source_url` to the specific page used
- [ ] Commit `parts.json` first, then the project file that references it

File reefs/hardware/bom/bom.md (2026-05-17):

# BOM — Reefs (Driftwood Ambient Lamps)

> Generated from specs.md §8.2 — 2026-05-16

## Components

| # | Component | Spec | Qty | Unit Price | Supplier | Part No. | Notes |
|---|---|---|-----|---|---|---|---|
| 1 | SK6812 RGBW LED strip | 5 V, 60 LED/m, IP30, 4-pin (GRBW) | 2 × 1 m (60 LEDs each) | ~€8/m | AliExpress / BTF-Lighting | — | Order 1.1 m per lamp; trim to fit |
| 2 | ESP8266 NodeMCU V3 board | LoLin/Wemos-style NodeMCU V3 reference | 1 | ~€4 | Generic NodeMCU vendor | NodeMCU V3 reference | Use `ESP8266_NODEMCU_V3` in the parts register for reference dimensions and pinout. UNVERIFIED — confirm your board's body size and Micro-USB position before updating enclosure geometry |
| 3 | Honeywell 5 V PSU | 5 V DC, ≥ 10 A (50 W) | 1 | (user-owned) | — | — | Verify nameplate rating ≥ 10 A |
| 4 | Aluminium LED channel | U-profile with diffuser, 12 mm wide, ≥ 1 m | 2 | ~€5 ea | Local / LUMINES | Type-Z or equiv. | Conducts heat away from wood |
| 5 | 3-conductor cable | 18 AWG power + 26 AWG data, or 3-core 20 AWG flex | 2 × 2.5 m | ~€2/m | Local electrical | — | 0.5 m slack; one cable per lamp |
| 6 | 330 Ω resistor | ¼ W, through-hole | 2 | <€0.01 ea | LCSC | C119313 | Series on GPIO data line at the ESP8266 side — ⚠️ C57436 is 10kΩ (MFR0W4F1002A50), not 330Ω |
| 7 | 74AHCT125 level shifter | SO-14 or DIP-14 | 1 | ~€0.30 | LCSC | C12494 | 3.3 V → 5 V for SK6812 data; 2 channels used |
| 8 | Blade fuse holder (inline) | 5 × 20 mm, panel or wire mount | 2 | ~€0.50 ea | LCSC / local | — | One per lamp 5 V power run |
| 9 | 5 A blade fuse | 5 × 20 mm slow-blow | 4 | <€0.20 ea | Local | — | 2 installed + 2 spare |
| 10 | JST SM 3-pin connector (M+F pair) | 2.5 mm pitch, 3 A rated | 2 pairs | ~€0.30/pair | on hand | — | **Female panel-mounted** in box wall pocket (lamp side male); V+/GND/DATA |
| 11 | Phoenix-style pluggable terminal | 3-pos, 5.08 mm pitch, screw clamp (PCB header + plug) | 1 | (on hand) | on hand | — | Internal 5 V distribution (PSU → fuses); replaces classic screw terminal |
| 12 | 3D-printed enclosure | ~150 × 100 × 60 mm PETG/ASA | 1 | ~€2 filament | Self-printed | — | See `mechanical/enclosure/reefs-automatedvariant-enclosure-spec.md` |
| 13 | M3 × 8 mm screws + brass inserts | — | 12 | ~€0.10 ea | Local | — | 2× PSU bracket, **2× mains cable clamp**, enclosure hardware and spares; NodeMCU board itself should sit in a printed pocket or clip, not on standoffs |
| 14 | Schuko captive mains lead | H05VV-F 3×0.75 mm², CEE 7/7 plug, ≥ 1.5 m | 1 | ~€2 | Local / scavenged | — | Mains entry; outer jacket clamped inside box; conductors go to PSU L/N/PE screws |
| 15 | Heat-shrink tubing | 2 mm, 4 mm, 6 mm assorted | 1 pack | ~€2 | Local / AliExpress | — | Insulate all solder joints; mandatory on every mains conductor |
| 16 | Cable ties (zip-ties) | 2.5 × 100 mm | 1 pack | ~€1 | Local | — | Strain-relief anchors for 2× lamp cables inside box |

> **Total estimated cost (excluding PSU):** ~€35–45 — drops vs. v1 because IEC C14 inlet, screw terminal block and PG9 glands are eliminated. PSU is user-owned.

---

## Power Budget

| Component | Voltage | Max Current | Typical @ 50 % brightness |
|---|---|---|---|
| SK6812 Lamp 1 — 60 LEDs × 60 mA (all channels) | 5 V | **3.60 A** | 0.90 A |
| SK6812 Lamp 2 — 60 LEDs × 60 mA (all channels) | 5 V | **3.60 A** | 0.90 A |
| ESP8266 NodeMCU V3 | 5 V (via onboard reg) | 0.30 A | 0.15 A |
| 74AHCT125 level shifter | 5 V | 0.02 A | 0.01 A |
| **Total** | 5 V | **7.52 A** | **1.96 A** |

> PSU minimum rating: 7.52 A ÷ 0.80 = **9.40 A** → use a **10 A (50 W) 5 V PSU**.
>
> Formula used: `N_leds × mA_per_channel × channels` — SK6812 4-channel at 20 mA/channel × 3 active channels max = 60 mA/LED worst-case.

---

## Voltage Drop (per lamp cable, 2 m run)

| Parameter | Value |
|---|---|
| Cable gauge | 18 AWG |
| Resistance | ~21 mΩ/m |
| Round-trip at 2 m | 84 mΩ |
| Max current (1 m strip full load) | 3.6 A |
| Voltage drop | **0.30 V** |
| Strip supply voltage | **4.70 V** ✅ (SK6812 spec: 4.5–5.5 V) |

---

## Connector & Cable Entry Strategy

No cable glands or IEC inlet used — all box penetrations are 3D-printed features in the enclosure SCAD.

| Penetration | Hole | Strain relief | Connector |
|---|---|---|---|
| Mains AC entry (back wall) | Ø8 mm round | **Printed 2-screw cable clamp** (M3 inserts) pressing on jacket | None (captive Schuko lead); conductors → PSU L/N/PE screw terminals |
| Lamp 1 output (left wall) | Rectangular pocket ~9.5 × 6 mm with internal shoulder | Connector body trapped by pocket shoulder + internal zip-tie | **Panel-mounted JST SM 3-pin female**; male plug from lamp cable inserts from outside |
| Lamp 2 output (right wall) | Rectangular pocket ~9.5 × 6 mm with internal shoulder | As above | As above |
| Micro-USB service opening (front wall) | Size to actual board cutout | n/a (cable accessed only during flashing) | NodeMCU V3 onboard Micro-USB — UNVERIFIED placement, confirm against the physical board |

### JST SM 3-pin current headroom

JST SM is rated 3 A/contact; worst-case per lamp is 3.6 A (60 LEDs × 60 mA at 100% white). Mitigations:

- **WLED ABL** (auto brightness limiter) set to **2800 mA per output** in LED Preferences
- **OR** cap UI max brightness at ~85% via boot preset

Typical real-world ambient use (50% coloured) draws <1 A per lamp, so the headroom only matters for the synthetic worst case.

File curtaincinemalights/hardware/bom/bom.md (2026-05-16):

# BOM — curtaincinemalights (Cinema Curtain LED Sync)

> Generated from specs.md §8 — 2026-05-16
> All dimensions from `tools/parts-register/parts.json` unless noted.

## Components

| # | Component | Spec | Qty | Unit Price | Supplier | Part No. | Notes |
|---|---|---|-----|---|---|---|---|
| 1 | SK6812 RGBW LED strip | 5V, 60 LED/m, IP20, 4-pin (GRBW), 10mm wide | ~3 m (180 LEDs) | ~€8/m | AliExpress / BTF-Lighting | — | **Measure curtain width first** — order cut length + 10 cm slack; 1 m min per order |
| 2 | ESP8266 LOLIN D1 Mini v4 | ESP-12F, 4MB flash, USB-C, 34.2 × 25.6 × 10 mm | 1 | ~€3 | LOLIN / generic devkit vendor | D1 Mini v4 reference | Use `D1_MINI_V4` in the parts register for dimensions and cutout guidance. `LCSC C701341` is an ESP32 module part and is not a D1 Mini variant |
| 3 | Hi-Link HLK-20M05 | 5V 4A 20W AC-DC module, DIP, 56 × 32 × 22.5 mm | 1 | ~€4 | LCSC | C465406 | ⚠️ WLED ABL must be ≤ 3200 mA; upgrade to HLK-30M05 if adding more LEDs |
| 4 | Aluminium LED channel (U-profile) | 12–16 mm wide with frosted diffuser lid, cut to curtain width | 1 length | ~€4/m | Local / LUMINES | Type-Z or equiv. | Cut on site; conducts heat away from curtain fabric |
| 5 | 74AHCT125 level shifter | DIP-14, 7.62 mm row pitch, 19.05 × 6.35 × 4.57 mm | 1 | ~€0.30 | LCSC | C57369 | Buffers 3.3 V GPIO → 5 V SK6812 data; uses 1 of 4 gates |
| 6 | 330 Ω resistor | ¼ W, through-hole | 1 | <€0.01 | LCSC | C119313 | Series on GPIO2 data line (ESP8266 side of shifter) — ⚠️ C57436 is 10kΩ (MFR0W4F1002A50), not 330Ω |
| 7 | JST SM 3-pin connector pair | 2.5 mm pitch, M+F pair | 1 pair | ~€0.30 | On hand | — | Female panel-mount in box wall pocket; male plug on strip cable |
| 8 | 3-conductor cable | 20 AWG (or 2× 18 AWG power + 26 AWG data) flex | ~curtain width + 1 m | ~€1.50/m | Local electrical | — | Power + data to strip; route inside curtain rail bracket channel |
| 9 | Schuko captive mains lead | H05VV-F 3×0.75 mm², CEE 7/7 plug, ≥ 1.5 m | 1 | ~€2 | Local / scavenged | — | Mains entry to PSU; strain-relieved inside enclosure via printed cable clamp |
| 10 | Inline blade fuse holder | 5 × 20 mm, wire-mount | 1 | ~€0.50 | Local / LCSC | — | 4 A slow-blow fuse on 5 V rail after PSU output |
| 11 | 4 A slow-blow fuse | 5 × 20 mm | 2 | ~€0.20 ea | Local | — | 1 installed, 1 spare |
| 12 | Heat-shrink tubing | 2 mm, 4 mm, 6 mm assorted | 1 pack | ~€2 | Local | — | All solder joints; mandatory on mains conductors |
| 13 | 3D-printed enclosure | PETG/ASA, ~106 × 46 × 44 mm | 1 | ~€1.50 filament | Self-printed | — | See `mechanical/enclosure/curtaincinemalights-enclosure.scad` |
| 14 | Cable ties (zip-ties) | 2.5 × 100 mm | 1 pack | ~€1 | Local | — | Mains cable strain relief inside box |
| 15 | 1000 µF / 10 V capacitor | Electrolytic, radial | 1 | ~€0.20 | LCSC | — | Across PSU 5 V output; prevents voltage dip on LED color transitions |

> **Total estimated cost:** ~€25–35 depending on LED strip length and whether D1 Mini / PSU are on hand.

---

## Power Budget

Dimensions source: `tools/parts-register/parts.json` (IDs: `D1_MINI_V4`, `HLK_20M05`, `SK6812_RGBW_60`).

| Component | Voltage | Max Current | Typical @ 25 % brightness |
|---|---|---|---|
| SK6812 Curtain — 180 LEDs × 60 mA (all channels, worst case) | 5 V | **10.80 A** | 0.67 A |
| SK6812 Curtain — **WLED ABL cap 3200 mA** | 5 V | **3.20 A** | 0.67 A |
| ESP8266 D1 Mini | 5 V (via onboard LDO) | 0.30 A | 0.18 A |
| 74AHCT125 level shifter | 5 V | 0.02 A | 0.01 A |
| **Total (ABL-limited)** | 5 V | **3.52 A** | **0.86 A** |

> PSU minimum: 3.52 A ÷ 0.80 safety factor = **4.4 A** — HLK-20M05 (4A) is marginal but works at
> ambient room temperature with ABL at 3200 mA. Set WLED LED Preferences → "Max current" = **3200 mA**.
> If operating in a warm enclosure or planning more than 3 m strip: use **HLK-30M05 (6A)** instead.
>
> Formula: `N_leds × mA_per_channel × channels` — SK6812 4-channel at 20 mA/ch × 3 active = 60 mA/LED worst-case.

---

## Voltage Drop (strip cable, 1.5 m run)

| Parameter | Value |
|---|---|
| Cable gauge | 20 AWG |
| Resistance | ~33 mΩ/m |
| Round-trip at 1.5 m | 99 mΩ |
| Max current at ABL cap | 3.2 A |
| Voltage drop | **0.32 V** |
| Strip supply voltage | **4.68 V** ✅ (SK6812 spec: 4.5–5.5 V) |

> Power inject midpoint at LED 90 (1.5 m) using a separate 2-conductor cable from the PSU 5 V rail.
> Without mid-inject, far-end voltage at 3.2 A through 3 m of 20 AWG ≈ 4.36 V — borderline.
> **Recommended: inject at strip midpoint (LED 90) to guarantee ≥ 4.5 V at all pixels.**

---

## Connector & Cable Entry Strategy

| Penetration | Hole | Strain relief | Connector |
|---|---|---|---|
| Mains AC entry (back wall) | Ø9 mm round | Printed 2-screw cable clamp (M3 × 8, brass inserts) pressing on jacket | None (captive Schuko lead); conductors → HLK-20M05 L/N/PE pins |
| LED strip output (left wall) | Rectangular pocket 9.5 × 6 mm (from `JST_SM_2P5_3PIN` register) | Connector body trapped by pocket shoulder + zip-tie on cable inside box | Panel-mount JST SM 3-pin female; male plug from strip cable |
| USB-C OTA (front wall) | 9.0 × 3.5 mm slot (from `D1_MINI_V4` register) | n/a (cable accessed only during flashing) | D1 Mini onboard USB-C |

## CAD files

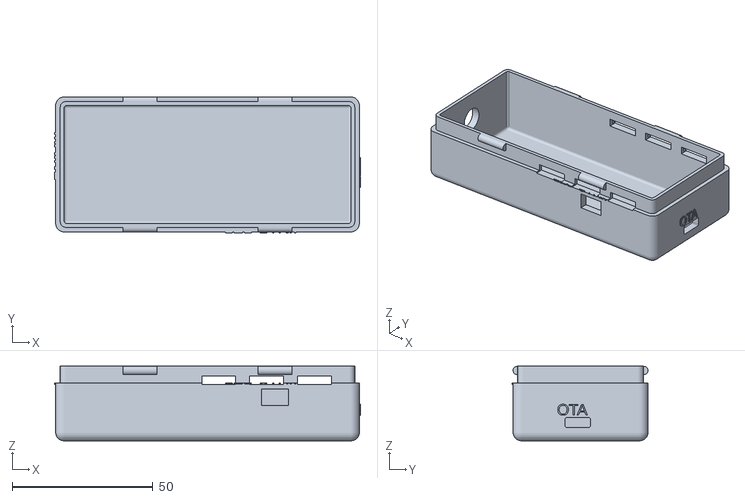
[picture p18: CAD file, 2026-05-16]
curtaincinemalights/mechanical/enclosure/curtaincinemalights-base.stl
108.8 x 48.4 x 26.5

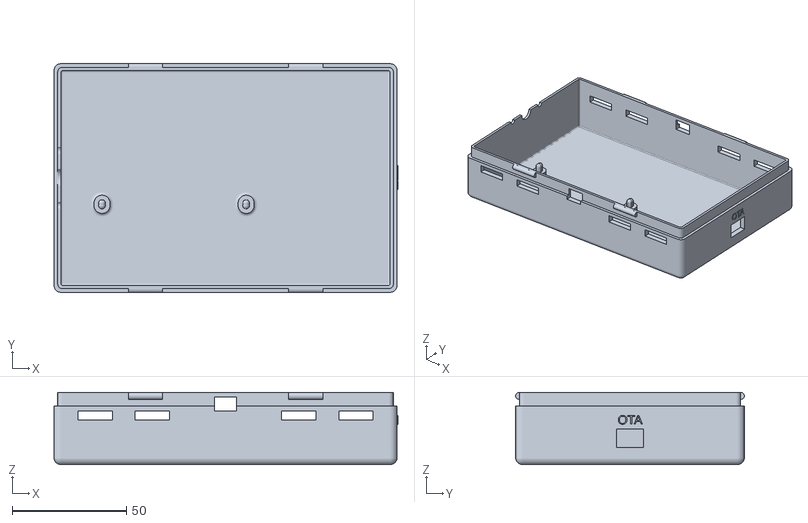
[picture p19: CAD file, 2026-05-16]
reefs/mechanical/enclosure/reefs-automatedvariant-base.stl
150.4 x 100.0 x 31.5

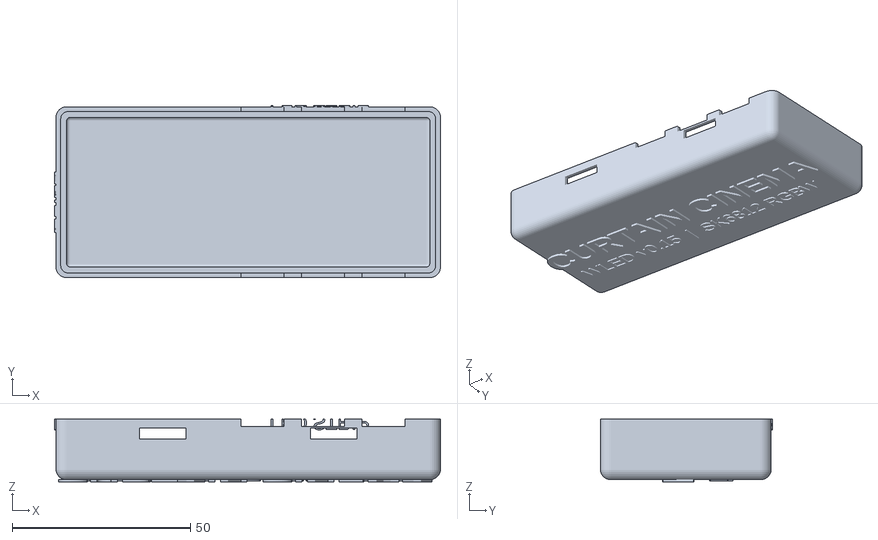
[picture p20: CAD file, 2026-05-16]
curtaincinemalights/mechanical/enclosure/curtaincinemalights-lid.stl
108.4 x 48.4 x 17.6

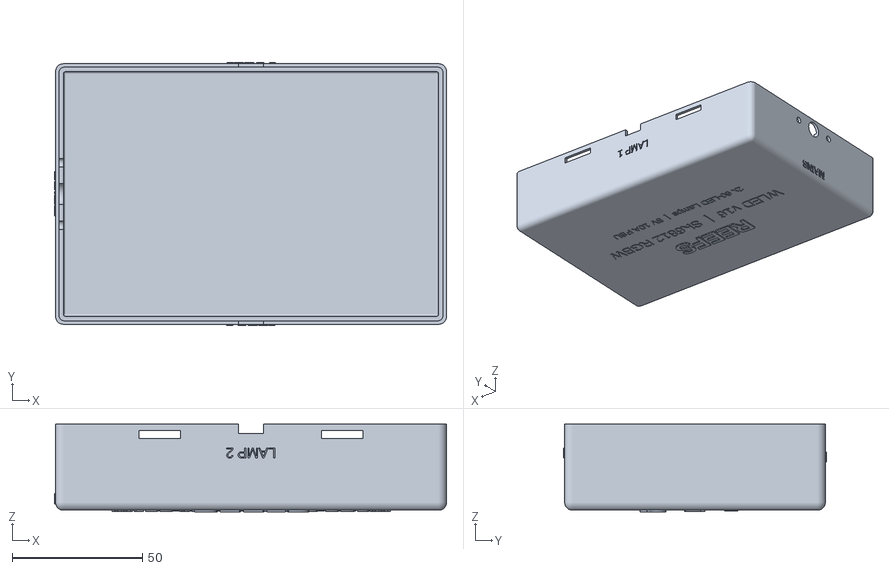
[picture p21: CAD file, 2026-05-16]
reefs/mechanical/enclosure/reefs-automatedvariant-lid.stl
150.4 x 100.8 x 33.6

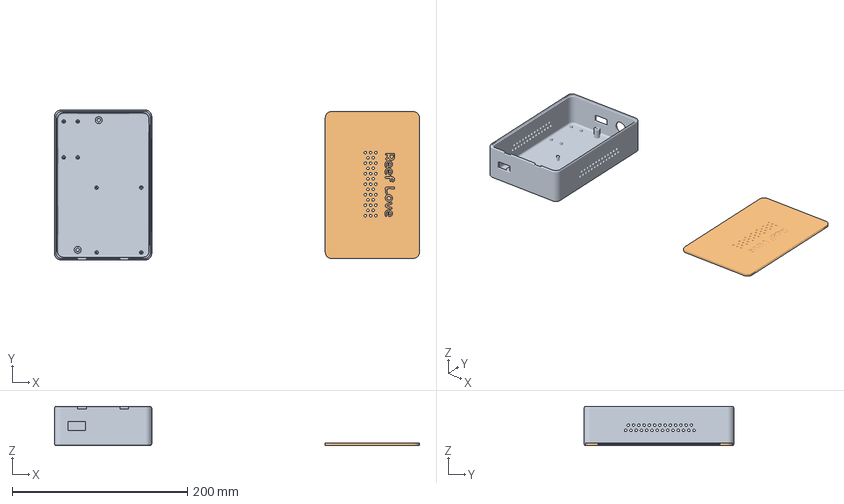
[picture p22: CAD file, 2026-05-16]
reefs/mechanical/enclosure/CustomProjectEnclosureV1.7.8b.3mf
416.5 x 171.0 x 45.0 mm
Parametric_Model_Maker_1_1
Parametric_Model_Maker_1_2

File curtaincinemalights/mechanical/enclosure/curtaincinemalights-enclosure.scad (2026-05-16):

// ============================================================
// curtaincinemalights — YAPP_Box v3 enclosure
// ESP8266 D1 Mini v4 + Hi-Link HLK-20M05 (5V 4A)
//
// Component dimensions from tools/parts-register/parts.json:
//   D1_MINI_V4  : 34.2 × 25.6 × 10.0 mm  (verified ✅)
//   HLK_20M05   : 56.0 × 32.0 × 22.5 mm  (verified ✅)
//   JST_SM_2P5_3PIN : pocket 9.5 × 6.0 mm (⚠️ estimated body)
//
// Layout (inner, top-down view):
//   X (front → back): 0 ────────────── 100 mm
//   Y (left  → right): 0 ─────────── 40 mm
//
//   Front zone (x = 0–38): D1 Mini  (34.2 mm × 25.6 mm), centered in Y
//   Back  zone (x = 42–100): HLK-20M05 (56 mm × 32 mm), centered in Y
//
// Outer envelope: ~106 × 46 × 44 mm
// ============================================================
include <../../../tools/yapp/YAPPgenerator_v3.scad>

// ---- Box dimensions (inner) -----------------------------------
pcbLength  = 100;   // X axis: front-to-back
pcbWidth   =  40;   // Y axis: left-to-right
pcbThickness = 1.6; // dummy — no real PCB (components direct-fit)

wallThickness     = 3.0;
basePlaneThickness = 1.5;
lidPlaneThickness  = 1.5;
baseWallHeight    = 25;   // HLK-20M05 height 22.5 mm + 2.5 mm clearance
lidWallHeight     = 10;   // lid shell depth
ridgeHeight       = 6.0;  // >= wallThickness * 1.8 = 5.4; use 6.0
ridgeSlack        = 0.3;
ridgeGap          = 0.5;
roundRadius       = 3.0;
boxType           = 0;

// ---- Standoff settings (shared params) -----------------------
standoffHeight      = 5.0;
standoffDiameter    = 5.0;
standoffPinDiameter = 2.5;
standoffHoleSlack   = 0.2;
pcbThick            = 1.6;

// ---- PCB (dummy — no PCB, both components direct-fit) ---------
pcb = [
  ["Main", pcbLength, pcbWidth, 0, 0, pcbThick,
   standoffHeight, standoffDiameter, standoffPinDiameter, standoffHoleSlack],
];

// ---- No standoffs (D1 Mini and HLK-20M05 have no mounting holes) ----
// Both components are held by friction-fit side walls:
//   D1 Mini  : friction-fit pocket at front; USB-C faces front wall
//   HLK-20M05: friction-fit pocket at back; DIP pins face left wall
// A small printed 1.5mm rib at y=28mm and y=8mm retains D1 Mini laterally.
// (Rib not modeled in YAPP — add if D1 Mini shifts during assembly.)
pcbStands = [];

// ---- Lid closure: snap-on (no screws) ------------------------
// Two snap-joins per long wall (yappSymmetric mirrors each entry
// about the wall midline). ridgeHeight=6.0 provides adequate snap depth.
connectors = [];

snapJoins = [
  // [posX, width, wall1, wall2, centering, symmetric]
  [30, 12, yappLeft, yappRight, yappCenter, yappSymmetric],
];

// ============================================================
// CUTOUTS
// Coordinate convention with yappCoordBoxInside + yappCenter:
//   cutoutsFront/Back  : [posY_fromLeft, posZ_fromFloor, w, h, r, shape, ...]
//   cutoutsLeft/Right  : [posX_fromFront, posZ_fromFloor, w, h, r, shape, ...]
// All measurements refer to the cutout CENTER.
// ============================================================

// ---- FRONT wall: USB-C slot for D1 Mini OTA/flashing --------
// D1 Mini centered in Y at 20mm; USB-C center ~5mm from floor
// Slot: 9.0 mm wide × 3.5 mm high (from D1_MINI_V4 register)
cutoutsFront = [
  [20, 5.0, 9.0, 3.5, 0.5, yappRoundedRect, 0, 0, yappCoordBoxInside, yappCenter],
];

// ---- BACK wall: mains cable entry, Ø9 mm hole ---------------
// Cable jacket diameter ~9mm for H05VV-F 3×0.75; center at mid-height
cutoutsBack = [
  [20, 14, 0, 0, 4.5, yappCircle, 0, 0, yappCoordBoxInside, yappCenter],  // Ø9 cable hole
];

// ---- LEFT wall: JST SM 3-pin panel-mount pocket -------------
// Pocket traps the female JST SM connector body from inside.
// Pocket: 9.5 × 6.0 mm (from JST_SM_2P5_3PIN register ⚠️).
// Positioned at x=75 (near HLK output terminals, back-half of box).
cutoutsLeft = [
  [75, 14, 9.5, 6.0, 0, yappRectangle, 0, 0, yappCoordBoxInside, yappCenter],  // JST SM pocket
  // Vent slots for PSU heat dissipation
  [55, 20, 12, 3, 0, yappRectangle, 0, 0, yappCoordBoxInside, yappCenter],
  [72, 20, 12, 3, 0, yappRectangle, 0, 0, yappCoordBoxInside, yappCenter],
  [89, 20, 12, 3, 0, yappRectangle, 0, 0, yappCoordBoxInside, yappCenter],
];

// ---- RIGHT wall: vent slots (mirror of left, no connector) --
cutoutsRight = [
  [55, 20, 12, 3, 0, yappRectangle, 0, 0, yappCoordBoxInside, yappCenter],
  [72, 20, 12, 3, 0, yappRectangle, 0, 0, yappCoordBoxInside, yappCenter],
  [89, 20, 12, 3, 0, yappRectangle, 0, 0, yappCoordBoxInside, yappCenter],
];

cutoutsLid  = [];
cutoutsBase = [];

// ---- Labels (raised engraving) --------------------------------
labelsPlane = [
  // Lid: project name (large) + strip / controller info (small)
  [53, 26, 0, -0.6, yappLid,
   "Liberation Sans:style=Bold", 9, "CURTAIN CINEMA",
   0, yappTextLeftToRight, yappTextHAlignCenter, yappTextVAlignCenter],
  [53, 14, 0, -0.4, yappLid,
   "Liberation Sans", 5, "WLED v0.15  |  SK6812 RGBW",
   0, yappTextLeftToRight, yappTextHAlignCenter, yappTextVAlignCenter],
  // Back wall: mains entry label
  [21, 22, 0, -0.4, yappBack,
   "Liberation Sans:style=Bold", 4, "MAINS",
   0, yappTextLeftToRight, yappTextHAlignCenter, yappTextVAlignCenter],
  // Front wall: OTA label
  [21, 11, 0, -0.4, yappFront,
   "Liberation Sans", 4, "OTA",
   0, yappTextLeftToRight, yappTextHAlignCenter, yappTextVAlignCenter],
  // Left wall: LED strip output label
  [74, 22, 0, -0.4, yappLeft,
   "Liberation Sans", 4, "LED STRIP",
   0, yappTextLeftToRight, yappTextHAlignCenter, yappTextVAlignCenter],
];

// ---- Not used in this design ----------------------------------
boxMounts     = [];
lightTubes    = [];
pushButtons   = [];
displayMounts = [];
imagesPlane   = [];

// ---- Generate geometry ----------------------------------------
YAPPgenerate();

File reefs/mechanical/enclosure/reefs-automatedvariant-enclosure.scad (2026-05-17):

// reefs-automatedvariant-enclosure.scad
// Project: Reefs — WLED Driftwood Ambient Lighting
//
// Outer dimensions: 150 x 100 x 59 mm  (spec: <= 150 x 100 x 60 mm OK)
// Inner dimensions: 144 x 94 x 56 mm
// Wall: 3 mm  Base floor: 1.5 mm  Lid ceiling: 1.5 mm
//
// Shared library: tools/yapp/YAPPgenerator_v3.scad
//
// Render commands (from this directory):
//   Base only:
//     openscad --render -o reefs-automatedvariant-base.stl reefs-automatedvariant-enclosure.scad -D "printLidShell=false"
//   Lid only:
//     openscad --render -o reefs-automatedvariant-lid.stl reefs-automatedvariant-enclosure.scad -D "printBaseShell=false"
//
// NOTE: include comes FIRST so our variable definitions below override the
// library defaults (OpenSCAD "last assignment wins").
// YAPPgenerate() is called explicitly to bypass the library's if(debug) guard.
// LEGACY GEOMETRY NOTE: this SCAD still carries the previous ESP32 DevKit mount
// and USB opening. The reefs project controller definition now targets an
// ESP8266 NodeMCU V3, so refit the board mount and service-port cutout before
// using this file for a new print run.

include <../../../tools/yapp/YAPPgenerator_v3.scad>

// ---- Render flags ----
printBaseShell      = true;
printLidShell       = true;
showSideBySide      = true;
printerLayerHeight  = 0.2;
renderQuality       = 8;

// ---- Box dimensions (virtual-PCB approach, all padding=0) ----
// inner L = 144 mm  outer L = 150 mm
// inner W =  94 mm  outer W = 100 mm
// inner Z = 1.5 + 30 + 26 + 1.5 = 59 mm outer
pcbLength           = 144;
pcbWidth            = 94;
pcbThickness        = 1.6;
standoffHeight      = 5.0;
standoffDiameter    = 7.0;
standoffPinDiameter = 3.0;
standoffHoleSlack   = 0.4;

paddingFront        = 0;
paddingBack         = 0;
paddingRight        = 0;
paddingLeft         = 0;

wallThickness       = 3.0;
basePlaneThickness  = 1.5;
lidPlaneThickness   = 1.5;
baseWallHeight      = 30;
lidWallHeight       = 26;
// ridgeHeight must be >= wallThickness * 1.8 for snapJoins (YAPP wallToRidgeRatio)
ridgeHeight         = 6.0;
ridgeSlack          = 0.3;
ridgeGap            = 0.5;
roundRadius         = 3.0;
boxType             = 0;

// ---- PCB (YAPP v3 format) ----
pcb = [
  ["Main", pcbLength, pcbWidth, 0, 0, pcbThickness,
   standoffHeight, standoffDiameter, standoffPinDiameter, standoffHoleSlack],
];

// ---- Legacy ESP32 DevKit 38-pin standoffs (4x M3) ----
// Board ~30x51 mm, hole pattern 45x23 mm centre-to-centre
// Orientation: USB connector toward FRONT (high X)
pcbStands = [
  [81,  35, standoffHeight, 0, standoffDiameter, standoffPinDiameter,
   standoffHoleSlack, yappBaseOnly, yappPin, yappBackLeft,   yappCoordPCB],
  [81,  58, standoffHeight, 0, standoffDiameter, standoffPinDiameter,
   standoffHoleSlack, yappBaseOnly, yappPin, yappBackRight,  yappCoordPCB],
  [126, 35, standoffHeight, 0, standoffDiameter, standoffPinDiameter,
   standoffHoleSlack, yappBaseOnly, yappPin, yappFrontLeft,  yappCoordPCB],
  [126, 58, standoffHeight, 0, standoffDiameter, standoffPinDiameter,
   standoffHoleSlack, yappBaseOnly, yappPin, yappFrontRight, yappCoordPCB],
];

// ---- Lid closure: SNAP-ON (no screws) ----
// 4 snap-joins centred on the two long walls (yappSymmetric mirrors each entry
// about the wall midline). Width 15 mm per snap. Tool-free open/close.
connectors = [];

// ---- BACK wall: Schuko captive mains lead entry (Ø8 mm) + 2x M3 clamp bosses ----
// Round Ø8 mm hole for the cable jacket; flanked by two Ø3.2 mm screw holes
// (12 mm pitch each side of centre) for a printed external cable clamp that
// compresses the cable jacket with two M3 × 8 screws into brass inserts.
cutoutsBack = [
  [47, 30, 0, 0, 4, yappCircle, 0, 0, yappCoordBoxInside, yappCenter],  // Ø8 cable hole
  [35, 30, 0, 0, 1.6, yappCircle, 0, 0, yappCoordBoxInside, yappCenter],  // clamp screw L
  [59, 30, 0, 0, 1.6, yappCircle, 0, 0, yappCoordBoxInside, yappCenter],  // clamp screw R
];

// ---- FRONT wall: USB service slot (12x8 mm, legacy ESP32 placement) ----
cutoutsFront = [
  [47, 10, 12, 8, 0, yappRectangle, 0, 0, yappCoordBoxInside, yappCenter],
];

// ---- LEFT wall: Lamp1 JST SM panel-mount pocket + 4 vent slots ----
// Pocket = rectangular 9.5 x 6 mm cutout that traps the female JST SM body
// from inside; the cable hole on the outside is narrower than the connector
// shoulders so it cannot pull through.
cutoutsLeft = [
  [15,  20, 15,  4, 0, yappRectangle, 0, 0, yappCoordBoxInside, yappCenter],
  [40,  20, 15,  4, 0, yappRectangle, 0, 0, yappCoordBoxInside, yappCenter],
  [72,  25, 9.5, 6, 0, yappRectangle, 0, 0, yappCoordBoxInside, yappCenter],  // JST SM pocket
  [104, 20, 15,  4, 0, yappRectangle, 0, 0, yappCoordBoxInside, yappCenter],
  [129, 20, 15,  4, 0, yappRectangle, 0, 0, yappCoordBoxInside, yappCenter],
];

// ---- RIGHT wall: Lamp2 JST SM panel-mount pocket + 4 vent slots (mirror) ----
cutoutsRight = [
  [15,  20, 15,  4, 0, yappRectangle, 0, 0, yappCoordBoxInside, yappCenter],
  [40,  20, 15,  4, 0, yappRectangle, 0, 0, yappCoordBoxInside, yappCenter],
  [72,  25, 9.5, 6, 0, yappRectangle, 0, 0, yappCoordBoxInside, yappCenter],  // JST SM pocket
  [104, 20, 15,  4, 0, yappRectangle, 0, 0, yappCoordBoxInside, yappCenter],
  [129, 20, 15,  4, 0, yappRectangle, 0, 0, yappCoordBoxInside, yappCenter],
];

cutoutsLid   = [];
cutoutsBase  = [];

// ---- Labels ----
labelsPlane = [
  // Lid: project title (3 lines, raised engraving)
  [75, 66, 0, -0.6, yappLid,
   "Liberation Sans:style=Bold", 10, "REEFS",
   0, yappTextLeftToRight, yappTextHAlignCenter, yappTextVAlignCenter],
  [75, 50, 0, -0.4, yappLid,
  "Liberation Sans", 6, "WLED v0.15  |  SK6812 RGBW",
   0, yappTextLeftToRight, yappTextHAlignCenter, yappTextVAlignCenter],
  [75, 36, 0, -0.3, yappLid,
   "Liberation Sans", 4, "2x 60-LED Lamps  |  5V 10A PSU",
   0, yappTextLeftToRight, yappTextHAlignCenter, yappTextVAlignCenter],
  // Back wall: mains entry label
  [50, 54.5, 0, -0.4, yappBack,
   "Liberation Sans:style=Bold", 4, "MAINS",
   0, yappTextLeftToRight, yappTextHAlignCenter, yappTextVAlignCenter],
  // Front wall: USB service label
  [50, 19.5, 0, -0.4, yappFront,
   "Liberation Sans", 4, "OTA",
   0, yappTextLeftToRight, yappTextHAlignCenter, yappTextVAlignCenter],
  // Left wall: Lamp 1 PG9 label
  [75, 38.5, 0, -0.4, yappLeft,
   "Liberation Sans", 4, "LAMP 1",
   0, yappTextLeftToRight, yappTextHAlignCenter, yappTextVAlignCenter],
  // Right wall: Lamp 2 PG9 label
  [75, 38.5, 0, -0.4, yappRight,
   "Liberation Sans", 4, "LAMP 2",
   0, yappTextLeftToRight, yappTextHAlignCenter, yappTextVAlignCenter],
];

// ---- Snap-on lid joins ----
// posx=40 on each long wall, mirrored to posx=110 via yappSymmetric => 4 snaps total.
// Width 15 mm. Requires ridgeHeight >= wallThickness * 1.8 (= 5.4 mm); we use 6.0.
snapJoins = [
  [40, 15, yappLeft, yappRight, yappCenter, yappSymmetric],
];
boxMounts     = [];
lightTubes    = [];
pushButtons   = [];
displayMounts = [];
imagesPlane   = [];

// ---- Generate geometry (bypasses library if(debug) guard) ----
YAPPgenerate();

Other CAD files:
tools/yapp/YAPPgenerator_v3.scad

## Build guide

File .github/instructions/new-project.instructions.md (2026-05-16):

---
description: >
  New project scaffolding conventions and specs.md authoring rules.
  Use when creating a new project folder, filling out specs.md,
  editing README.md, or working with the _template/ skeleton.
applyTo:
  - "_template/**"
  - "*/specs.md"
  - "README.md"
---

# New Project — Instructions

## Starting a New Project

Always start from `_template/` — never create the folder structure from scratch:

```bash
cp -r _template/ <project-name>/
```

Then work through these steps **in order**:

1. **`specs.md`** — fill out concept, requirements, constraints, acceptance criteria, and the **Home Assistant** section
2. **`hardware/bom/bom.md`** — calculate current budget, select PSU, list all parts
3. **`hardware/wiring/WIRING.md`** — document GPIO assignments, power rails, wire runs
4. **Enclosure** — once wiring is finalised, run `/gen-enclosure` to generate `mechanical/enclosure/<project>-enclosure.scad` — see **Enclosure Generation** section below
5. **`gen_diagrams_config.py`** — copy from `reefs/gen_diagrams_config.py`, update values
6. **`gen_diagrams.py`** — copy from `reefs/gen_diagrams.py`, update project import path
7. **`firmware/cfg.json`** — set a unique mDNS hostname: `"id": {"mdns": "<project-name>"}` and ensure `"nw": {"mdns": 1}`
8. **`README.md`** (project level) — full project README following the **Project README Structure** standard below: concept images first, documentation index table, wiring diagrams, build checklist
9. **`README.md`** (repo root) — add a row to the Projects table
10. **Review pass** — after scaffolding or broad project doc updates, switch to the `ESP/WLED Project Reviewer` agent or the planner's review handoff so the first pass is checked for missing artifacts, register-backed hardware facts, and current repo-meta coherence

## Planning With The Parts Register

At each planning step, check `tools/parts-register/parts.json` first so the project reuses known part data instead of re-deriving it.

| Planning step | Use the register for |
|---|---|
| Concept / part selection | Compare candidate LED strips, controller boards, PSUs, and connectors already used in the repo |
| specs.md | Pull canonical part names, MPNs, voltages, protocols, and board capabilities |
| bom.md | Reuse exact part identity, sizing assumptions, and source links |
| WIRING.md | Reuse connector notes, board pinout data, GPIO warnings, and level-shifter guidance |
| Enclosure planning | Reuse `pcb_or_body_mm`, `cutouts_needed`, connector bodies, and board heights |
| README.md | Reuse concise part facts, `source_url` links, and board pinout previews when available |

If a required part is missing from the register, add it before finalizing the project docs.

## specs.md Structure

A `specs.md` must contain at minimum:

- **Concept**: one paragraph describing the project and intended effect
- **Requirements**: LED type, count, power source, mounting, connectivity, smart home target
- **Constraints**: budget, enclosure size, power availability
- **Acceptance Criteria**: checklist of "done" conditions (all LEDs responding, WLED reachable, presets saved, no flicker, thermal OK, enclosure closed, HA control verified)
- **Open Questions**: anything not yet decided
- **Home Assistant** *(mandatory)*: list expected HA entity IDs (e.g. `light.reefs_lamp_1`), the mDNS device name used, and whether [hacs-wledext-effects](https://github.com/tamaygz/hacs-wledext-effects) effects are needed and which ones

## hacs-wledext-effects

If the project uses state-driven LED effects, add a `design/effects/ha-automations.yaml` file with example automations. Note in `specs.md` which effects are installed and their entity IDs.

Use hacs-wledext-effects when the strip should visualize a HA sensor value, fire notification-style alerts from HA events, or when automation-controlled effect behaviour is needed. Skip it when a static WLED preset is sufficient or there is no HA state dependency.

## DIAGRAM_CONFIG Keys

`gen_diagrams_config.py` must export `DIAGRAM_CONFIG` with at minimum:

| Key | Type | Used by | Description |
|-----|---|---|---|
| `project` | str | all | Folder name of the project |
| `title` | str | all | Display title for diagram headers |
| `psu` | str | blocks, wiring | PSU label (e.g. `"Brand 5V / 10A"`) |
| `controller` | str | blocks, wiring | Controller label (e.g. `"ESP32-WROOM-32\nWLED v16+"`) |
| `shifter` | str \| None | blocks, wiring | Level shifter label, or `None` to omit |
| `integration` | str \| None | blocks | Smart-home block label (e.g. `"Home\nAssistant"`) |
| `outputs` | list[dict] | blocks, wiring | Each has `name` and `strip` keys |
| `gpio_map` | list[dict] | wiring | Each has `gpio`, `label`, `color` |
| `lamps` | list[dict] | concept | Each has `label`, `cx` (x-position along wall) |
| `wood_label` | str | concept | Label inside the driftwood / object silhouette in the side-view |
| `box_pos` | tuple(float,float) | concept | (x, y) position of the control box in the top-down floor plan |
| `power_label` | str | wiring | PSU label shown on the wiring diagram power block |

Copy `reefs/gen_diagrams_config.py` and update all values for the new project.

## Diagram Types

Four types are produced by `python tools/gen_diagrams.py <project>`:

| Type flag | Module | Output file(s) | What it shows |
|---|---|---|---|
| `blocks` | `blocks.py` | `concept-system.png` | System block diagram: PSU → ESP32 → level shifter → LED strips → HA integration |
| `concept` | `concept.py` | `concept-side-view.png`, `concept-top-view.png` | Real-world visualisation: cross-section of lamp on wall (side), floor-plan with lamp positions and cable run (top) |
| `wiring` | `wiring.py` | `wiring-physical.svg` (+ `.png`) | Color-coded physical wiring: ESP32 pins → level shifter → JST connectors |
| `schematic` | `schematic.py` | `schematic-level-shifter.png`, `schematic-power.png` | Electrical schematics: level-shifter gate circuit and power distribution |

## Project README Structure

Every project `README.md` **must** follow this section order:

1. **Title + one-liner** — `# Project Name` and a `>` blockquote tagline
2. **Concept section** — 2–3 sentences describing the lighting effect and installation, immediately followed by the three concept images:
   - `docs/concept-side-view.png` — real-world cross-section of the lamp/object
   - `docs/concept-top-view.png` — floor-plan with installation positions and cable run
   - `docs/concept-system.png` — system block diagram (PSU → ESP32 → strips → HA)
3. **Quick Facts table** — board, LED type, LED count, PSU, WLED version, smart-home target
4. **Key Components / Parts Snapshot** — concise table sourced from `tools/parts-register/parts.json` for the controller, LED strip, PSU, level shifter, and any connector or module that is central to the build. Include:
   - register `PART_ID`
   - part name / role in the project
   - 1–3 high-value facts from the register
   - link to `source_url` when present
   - for boards, a pinout preview or pinout link when `board_pinout.image_url` or `board_pinout.image_path` is available
5. **Documentation Index table** — one row per document that physically exists in the project, linking to:
   - `specs.md`
   - `hardware/bom/bom.md`
   - `hardware/wiring/WIRING.md`
   - `design/led-map/LED-DESIGN.md`
   - `design/effects/ha-automations.yaml`
   - `mechanical/enclosure/MODELS.md` (when enclosure exists)
   - `firmware/platformio_override.ini`
   - `firmware/cfg.json`
   - `firmware/presets.json`
6. **Wiring & Schematics section** — embed `docs/wiring-physical.svg`, then a two-column table containing `docs/schematic-level-shifter.png` and `docs/schematic-power.png`; include a text link to `hardware/wiring/WIRING.md` for the GPIO table
7. **Build Checklist** — project-specific MVP steps as a task list
8. **Resources** — at minimum link to `specs.md`, WLED Docs, and WLED GitHub

**Rules:**
- Concept images must appear **before** the Quick Facts table — visuals communicate the idea before the spec details.
- The Key Components section must reuse register facts instead of hand-written approximations whenever the relevant part exists in `tools/parts-register/parts.json`.
- If the register provides `source_url`, link it from the Key Components table or related part mention.
- If the register provides `board_pinout.image_url` or `board_pinout.image_path`, show a board pinout preview or an explicit pinout link in the README.
- If diagrams have not been generated yet, keep the `![](docs/...)` image tags in place and add a callout: `> Run \`python tools/gen_diagrams.py <project>\` to generate these images.`
- Only link files that physically exist. Remove links to empty stubs from the Documentation Index.
- Do not hand-edit anything in `docs/` — regenerate via `python tools/gen_diagrams.py <project>`.

## README.md Projects Table

When adding a project, append a row to the table in the root `README.md`:

```markdown
| [project-name](./project-name/) | Status | LED type × count | One-line description |
```

Status values: `planning`, `wip`, `done`, `archived`.

## Enclosure Generation

Use **YAPP_Box** (MIT, 485⭐, actively maintained) as the standard enclosure design tool for all projects:
<https://github.com/mrWheel/YAPP_Box>

YAPP_Box produces parametric, command-line renderable OpenSCAD files. No MakerWorld login or browser required.

### Workflow

1. Run the `/gen-enclosure` slash command — it reads `specs.md`, `bom.md`, and `WIRING.md` to calculate dimensions and cutout positions
2. A complete `mechanical/enclosure/<project>-enclosure.scad` config file is generated. The SCAD includes the shared YAPP library via relative path `../../../tools/yapp/YAPPgenerator_v3.scad` — **do not** copy the library into the project folder
3. Render the base, the lid, and 4 preview PNGs with the helper:
   ```powershell
   pwsh tools/render_enclosure.ps1 -Project <project> -ScadName <project>-enclosure
   ```
4. Inspect the iso PNGs — lid must be clean (no floating standoff stems). If stems appear, change the offending `pcbStands` entry to `yappBaseOnly` and re-render.

### Output files

| File | Committed? |
|---|---|
| `mechanical/enclosure/<project>-enclosure.scad` | ✅ Yes (source) |
| `mechanical/enclosure/<project>-enclosure-spec.md` | ✅ Yes (parameter sheet) |
| `mechanical/enclosure/<project>-base.stl` | ✅ Yes |
| `mechanical/enclosure/<project>-lid.stl` | ✅ Yes |
| `mechanical/enclosure/<project>-{base,lid}-{iso,top}.png` | ✅ Yes (4 previews) |
| `tools/yapp/YAPPgenerator_v3.scad` | Shared — lives in `tools/yapp/`, **not** in the project folder |

### Key YAPP_Box design rules

- **Snap-on lid is the default** (`snapJoins = [[40, 15, yappLeft, yappRight, yappCenter, yappSymmetric]]`, `connectors = []`). Only use screw connectors if the user explicitly requests them.
- **`ridgeHeight = 6.0`** (must satisfy `ridgeHeight >= wallThickness * 1.8` whenever `snapJoins` is non-empty — YAPP asserts this at render time).
- **`pcbStands` must use `yappBaseOnly`** — lid stays clean, no floating posts.
- Use the **virtual PCB approach**: set `pcbLength`/`pcbWidth` to the desired inner dimensions, set all padding to `0`.
- Always use `yappCoordBoxInside, yappCenter` for cutout positioning.
- The `include <...>` line must be the **first** executable line; explicit `YAPPgenerate();` is the **last** line.

### MakerWorld alternative

If you prefer a browser GUI or need the MrPractical aesthetic, the MakerWorld
**Customizable Project Enclosure Box** (designId 952727) is an alternative.
Requires Bambu Lab account. No CLI render path — browser download only.
Use YAPP_Box for all new projects and automation scenarios.

### Skill reference

The `enclosure-gen` skill contains the complete YAPP_Box API reference including:
- All dimension calculation formulas
- Cutout array formats with shape constants
- Standard component cutout dimensions table (IEC C14, PG9, USB-C, barrel jack, etc.)
- ESP32 DevKit standoff dimensions
- CLI render commands
- Complete reefs project worked example

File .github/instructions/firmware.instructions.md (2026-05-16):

---
description: >
  PlatformIO and WLED firmware configuration rules.
  Use whenever editing platformio_override.ini, cfg.json, presets.json,
  WLED build flags, usermods, or flashing instructions.
applyTo:
  - "**/firmware/**"
  - "**/platformio_override.ini"
---

# Firmware — Instructions

## File Roles

| File | Purpose |
|---|---|
| `platformio_override.ini` | Build-time overrides — extends a WLED base environment |
| `cfg.json` | WLED runtime config exported from the web UI |
| `presets.json` | WLED presets and playlists exported from the web UI |

The `platformio_override.ini` lives alongside the WLED repo's own `platformio.ini` when building. It is **not** a standalone PlatformIO project.

## platformio_override.ini Structure

```ini
[env:esp32dev_<project>]
extends = env:esp32dev          ; always extend a WLED base env

custom_usermods =
  ; list usermods one per line

build_flags =
  ${env:esp32dev.build_flags}   ; always inherit parent flags first
  -D SOME_FLAG=value
```

Valid base environments: `esp32dev`, `esp32_eth`, `esp8266`, `esp01`.

## Security: Credentials

**Never commit WiFi station credentials.** Configure SSID / password via:
1. WLED Captive Portal on first boot (AP mode `wled-ap`)
2. WLED web UI → WiFi Setup

If a build flag default is needed for the AP fallback only:
```ini
build_flags =
  ${env:esp32dev.build_flags}
  -D WLED_AP_PASS='"changeme"'    ; AP fallback, not station credentials
```

## Common Build Flags

| Flag | Default | Notes |
|---|---|---|
| `LEDPIN` | 2 | Main LED data GPIO |
| `BTNPIN` | 0 | Physical button GPIO |
| `WLED_MAX_BUSSES` | 3 | Increase for >3 LED outputs |
| `USERMOD_AUDIOREACTIVE` | off | Enables audioreactive usermod |

## Flashing

```bash
# From within the WLED repo directory with the project override alongside it:
pio run -e esp32dev_<project> -t upload                       # USB serial
pio run -e esp32dev_<project> -t upload --upload-port=<ip>    # OTA
```

## cfg.json / presets.json

Export from WLED UI:
- `cfg.json`: **Config** → **Security & Updates** → **Backup**
- `presets.json`: same backup page, or export individual presets

Do not hand-edit these JSON files for simple changes — use the WLED web UI and re-export.

## Home Assistant / mDNS

Every project must be discoverable by Home Assistant via mDNS. Two required keys in `cfg.json`:

```json
{
  "id": { "mdns": "<project-name>" },
  "nw": { "mdns": 1 }
}
```

- `mdns` hostname must be unique across all devices on the network.
- HA native WLED integration auto-discovers the device once mDNS is active.
- Do not configure MQTT unless there is an explicit reason — the native integration is sufficient.

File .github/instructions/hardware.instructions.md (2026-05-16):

---
description: >
  Wiring, BOM, PCB, and hardware documentation rules for ESP32/WLED projects.
  Use when editing wiring diagrams, bill of materials, KiCad schematics,
  or adding hardware specs to any project.
applyTo:
  - "**/hardware/**"
  - "**/bom/**"
  - "**/wiring/**"
  - "**/pcb/**"
---

# Hardware — Instructions

## Level Shifting (Critical)

ESP32 GPIO outputs are **3.3 V logic**. LED strips (SK6812, WS2812B) require a **5 V data signal**. Always place a level shifter on every LED data line.

- Preferred ICs: **SN74HCT245** (octal) or **74AHCT125** (quad buffer)
- One gate per data channel
- OE pin active-low — tie to GND to keep buffers always enabled
- Bypass caps: 100 nF ceramic close to each VCC pin

## Power Injection

For LED strips longer than 1 m (or >50 LEDs):
- Inject power at both ends of the strip
- Inject every ≤ 50 LEDs for runs >2 m
- Wire gauge: 22 AWG minimum for ≤1 A; 18 AWG for >1 A per run

## Current Budget Formula

```
I_total = N_leds × mA_per_channel × channels
```

- SK6812 RGBW: use 20 mA per channel, 4 channels → 80 mA/LED maximum
- WS2812B RGB: use 20 mA per channel, 3 channels → 60 mA/LED maximum
- Apply a **20 % safety headroom** when selecting PSU wattage
- Add **10 % derating** for continuous operation

Example (SK6812, 60 LEDs): `60 × 20 mA × 4 = 4.8 A peak` → PSU ≥ 6 A (with headroom)

## bom.md Format

`hardware/bom/bom.md` must include:

1. **Power budget table** (LED current calculation, headroom, PSU selection)
2. **Parts list table** with columns: Part, Qty, Unit Price, Supplier, Part No., Notes
3. **Total cost estimate**

Preferred suppliers: LCSC (PCB components), Aliexpress / BTF-Lighting (LED strips), Mouser / DigiKey (precision parts).

## Common GND

The PSU 5 V GND and the ESP32 GND **must share a common ground**. This is not automatic — wire it explicitly between the PSU terminal block and the ESP32 GND pin.

## KiCad Conventions

- Schematic sources: `hardware/pcb/*.kicad_sch`
- PCB source: `hardware/pcb/*.kicad_pcb`
- Gerber exports: `hardware/pcb/gerbers/`
- Export Gerbers before every board order; commit them alongside the source

## GPIO Assignment (WLED defaults — override in cfg.json or via build flag)

| Signal | Recommended GPIO |
|---|---|
| LED Data 1 | GPIO 16 |
| LED Data 2 | GPIO 17 |
| LED Data 3 | GPIO 18 |
| IR Receiver | GPIO 4 |
| Button | GPIO 0 |

Avoid: GPIO 0 (boot mode), GPIO 2 (boot LED), GPIO 12 (boot flash voltage), GPIO 15 (boot messages).

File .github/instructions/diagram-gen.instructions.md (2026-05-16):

---
description: >
  Rules for generating diagrams in esp-wled-projects.
  Use these guidelines whenever creating or modifying diagram
  generators, adding a new project, or updating docs/ visuals.
applyTo:
  - "**/gen_diagrams.py"
  - "**/gen_diagrams_config.py"
  - "**/docs/*.png"
  - "**/docs/*.svg"
  - "tools/diagram_gen/**"
---

# Diagram Generation — Copilot Instructions

## Package location
All shared diagram code lives in `tools/diagram_gen/`.  
**Never copy-paste diagram logic into a project folder** — extend the shared package instead.

## Module map

| Module | What it produces | Key public function |
|---|---|---|
| `style.py` | Shared colour palette + `apply_dark_theme()` | Constants only |
| `schematic.py` | Electrical schematics (schemdraw) | `draw_level_shifter_circuit(out)` · `draw_power_circuit(out)` |
| `blocks.py` | System block diagrams (matplotlib) | `draw_system_blocks(config, out)` |
| `concept.py` | Real-world concept illustrations (matplotlib) | `draw_side_view(config, out)` · `draw_top_view(config, out)` |
| `wiring.py` | Physical wiring diagrams (drawsvg) | `draw_physical_wiring(config, out)` |

## Import pattern for a project script

```python
import os, sys
TOOLS = os.path.join(os.path.dirname(os.path.abspath(__file__)), '..', 'tools')
sys.path.insert(0, TOOLS)

from diagram_gen import blocks, concept, schematic, wiring
from diagram_gen.style import apply_dark_theme
```

## Adding a new project

1. Create `<project>/gen_diagrams_config.py` exporting `DIAGRAM_CONFIG` dict.  
   Required keys: `title`, `psu`, `controller`, `outputs`, `gpio_map`, `lamps`.  
   Copy from `reefs/gen_diagrams_config.py` as a starting point.

2. Create `<project>/gen_diagrams.py` following the pattern in `reefs/gen_diagrams.py`.

3. Run with:
   ```
   python reefs/gen_diagrams.py           # from repo root
   python tools/gen_diagrams.py reefs     # alternative via CLI runner
   ```

4. All outputs go to `<project>/docs/`.

## Generating diagrams

```bash
# All types for a project:
python tools/gen_diagrams.py reefs

# Single type:
python tools/gen_diagrams.py reefs --type schematic
python tools/gen_diagrams.py reefs --type blocks
python tools/gen_diagrams.py reefs --type concept
python tools/gen_diagrams.py reefs --type wiring
```

## Library rules

- **schemdraw ≥ 0.22**: `elm.Ic()` and `elm.IcPin()` for IC boxes.  
  `elm.Ic` is a **block element** — do NOT chain `.right(n)` / `.left(n)` on it.  
  Use `.at(position)` to place it. Two-terminal elements (`elm.Line`, `elm.Fuse`,
  `elm.Resistor`) accept `.right(n)`, `.left(n)`, `.up(n)`, `.down(n)`.
- **drawsvg ≥ 2.4**: import as `import drawsvg as draw`. No `__version__` attr.  
  Save SVG with `d.save_svg(path)`. PNG export requires `cairosvg` or Cairo libs.
- **matplotlib**: always call `matplotlib.use("Agg")` **before** importing pyplot  
  to prevent window pop-ups on headless / CI environments.

## Colour palette

All colours are defined in `tools/diagram_gen/style.py`.  
Never hardcode hex values in diagram modules — reference style constants:

```python
from . import style
style.WIRE_RED   # +5V rail
style.WIRE_BLK   # GND
style.WIRE_GRN   # DATA signal
style.LED_DOT    # LED dot / warm yellow
style.GLOW       # light halo
style.ACCENT     # primary (ESP32, titles)
style.ACCENT2    # secondary (data signals, level shifter)
```

## Output conventions

- `docs/schematic-level-shifter.png` — level shifter circuit
- `docs/schematic-power.png` — power distribution
- `docs/concept-system.png` — system block diagram
- `docs/concept-side-view.png` — cross-section illustration
- `docs/concept-top-view.png` — floor plan illustration
- `docs/wiring-physical.svg` — physical wiring diagram (+ .png if cairosvg present)

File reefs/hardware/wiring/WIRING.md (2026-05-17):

# Wiring Notes — Reefs

> Source of truth: `specs.md` §8.4 and the generated diagrams in `docs/`.

## Generated Diagrams

| Diagram | File | Description |
|---|---|---|
| Physical wiring | [`docs/wiring-physical.svg`](../../docs/wiring-physical.svg) | NodeMCU V3 → level shifter → JST → strips |
| Level shifter circuit | [`docs/schematic-level-shifter.png`](../../docs/schematic-level-shifter.png) | 74AHCT125 2-channel schematic |
| Power circuit | [`docs/schematic-power.png`](../../docs/schematic-power.png) | Mains → fuse → PSU → per-lamp fuses |
| System block | [`docs/concept-system.png`](../../docs/concept-system.png) | High-level signal and power flow |

Regenerate all diagrams: `python tools/gen_diagrams.py reefs` (from repo root).

---

## Control Box Internal Wiring

```
Schuko captive lead (H05VV-F 3×0.75 mm², CEE 7/7 plug)
  enters via Ø8 mm back-wall hole; outer jacket clamped
  by 3D-printed 2× M3 cable clamp immediately inside.
  ├── Live (brown)    ──▶ PSU L screw terminal
  ├── Neutral (blue)  ──▶ PSU N screw terminal
  └── Earth (gn/yel)  ──▶ PSU PE screw terminal

PSU +5V ──▶ Pluggable terminal V+ pin
PSU GND ──▶ Pluggable terminal GND pin
             (3-pos Phoenix-style; 5.08 mm pitch; screw-clamp plug)

V+ bus  ──[5A fuse]──▶ JST Lamp 1 Pin 1 (+5V)
GND bus ────────────▶ JST Lamp 1 Pin 2 (GND)
V+ bus  ──[5A fuse]──▶ JST Lamp 2 Pin 1 (+5V)
GND bus ────────────▶ JST Lamp 2 Pin 2 (GND)

NodeMCU D5 / GPIO14 ──[330Ω]──▶ 74AHCT125 Channel A IN
                                74AHCT125 Channel A OUT ──▶ JST Lamp 1 Pin 3 (DATA)

NodeMCU D6 / GPIO12 ──[330Ω]──▶ 74AHCT125 Channel B IN
                                74AHCT125 Channel B OUT ──▶ JST Lamp 2 Pin 3 (DATA)

74AHCT125 VCC ──▶ V+ bus (5V)
74AHCT125 GND ──▶ GND bus
74AHCT125 nOE ──▶ GND (always enabled)

NodeMCU VIN / VU ──▶ V+ bus
NodeMCU GND      ──▶ GND bus
```

### Connector / Cable Entry Detail

| Penetration | Wall | Hole | Strain relief |
|---|---|---|---|
| Mains AC | Back | Ø8 mm round | 3D-printed 2-screw cable clamp (M3 inserts) on jacket |
| Lamp 1 output | Left | Rectangular pocket ~9.5 × 6 mm + internal shoulder | Female JST SM body trapped by pocket; zip-tie on cable inside |
| Lamp 2 output | Right | Rectangular pocket ~9.5 × 6 mm + internal shoulder | Female JST SM body trapped by pocket; zip-tie on cable inside |
| Micro-USB service opening | Front | Size to actual board cutout | n/a (passive cable access; verify against your NodeMCU board) |

## Lamp Cable (per lamp, 2 m run)

```
Male JST Pin 1 (18 AWG red)   ──▶ LED strip +5V pad
Male JST Pin 2 (18 AWG black) ──▶ LED strip GND pad
Male JST Pin 3 (26 AWG white) ──▶ LED strip DIN pad
```

Male plug on lamp end; mates with **panel-mounted female JST SM** on the box wall.
JST SM rated 3 A/contact — set WLED ABL to **2800 mA per output** to stay within spec at worst-case full white.

> Keep data wire physically separate from the power pair (space ≥ 5 mm or twist) to minimise EMI coupling.

---

## GPIO Assignments

| GPIO | Function | Notes |
|---|---|---|
| D5 / GPIO14 | LED Data — Lamp 1 | Preferred output pin; via 330 Ω series + 74AHCT125 level shifter |
| D6 / GPIO12 | LED Data — Lamp 2 | Preferred output pin; via 330 Ω series + 74AHCT125 level shifter |
| D3 / GPIO0 | Boot mode strapping | Do not use for LED data |
| D4 / GPIO2 | Boot LED / strapping | Do not use for LED data in this build |
| D8 / GPIO15 | Boot strapping | Do not use for LED data |

> The project's NodeMCU mapping follows `ESP8266_NODEMCU_V3` in the parts register. UNVERIFIED clone boards can vary slightly in silkscreen and USB placement, so confirm the labels on your actual board before final wiring.

---

## WLED Top 5 Wiring Mistakes

1. **No 300–500 Ω resistor** on data line → signal reflections / flickering.
2. **Missing common GND** between NodeMCU and strip → erratic/no data.
3. **3.3 V data direct** to 5 V SK6812 strip → marginal logic level; always use level shifter.
4. **No 1000 µF cap** on PSU rail → voltage dip on colour change (consider adding near strip).
5. **Long data line** > 50 cm before level shifter → bit errors at high update rates.

---

## Schematic Source Files

> KiCad project files are not yet created for this project. Generated diagrams (SVG/PNG) are in `docs/` and are the primary visual reference.
>
> If a KiCad schematic is added later, place it here as:
> - `hardware/wiring/reefs.kicad_sch`
> - `hardware/wiring/reefs-wiring.pdf` (exported)

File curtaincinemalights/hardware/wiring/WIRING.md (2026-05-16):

# WIRING — curtaincinemalights

> Status: design (not yet built)
> All pin assignments are for **ESP8266 LOLIN D1 Mini v4** with WLED v0.15 (ESP8266 branch).

---

## Pin Allocation

| GPIO | D1 Mini Pin | Function | Notes |
|---|---|---|---|
| GPIO2 | D4 | SK6812 RGBW data output | Active HIGH after boot; avoids boot-mode pin (GPIO0=D3) |

> **GPIO2 (D4) is safe for WLED output** — it is pulled HIGH by default (on-board LED via
> 10 kΩ to 3.3 V). WLED drives it LOW during data bursts. Always use a 330 Ω series resistor
> between GPIO2 and the level shifter input to limit ringing on the stub.

---

## Block Description

```
230 V AC mains lead
        │
        ▼
┌──────────────┐
│  HLK-20M05   │  5V / 4A
│  AC-DC PSU   │──────────────────────────────────────┐
└──────────────┘                                       │
        │                                              │
   5V rail ──┬──────────────────────────────────────── ┤ (common GND)
             │                                         │
             ▼                                         │
      ┌────────────┐  3.3V                             │
      │ D1 Mini    │──(internal LDO, 5V→3.3V)          │
      │ ESP8266    │                                   │
      │  GPIO2(D4) │──[330 Ω]──▶ 74AHCT125 OE+A ──────┤
      └────────────┘             74AHCT125 Y          │
                              (Vcc = 5V rail)          │
                                     │                 │
                                     ▼                 ▼
                              5V DATA ────────────────► SK6812 RGBW strip
                              5V VCC  ──────────────► strip +5V (× 2 injection points)
                              GND     ──────────────► strip GND (common with PSU GND)
```

---

## Wiring Details

### 5V Power Rail

| From | To | Wire | Notes |
|---|----|---|---|
| HLK-20M05 VO+ | PSU output bus / terminal block | 18 AWG red | 4A continuous; short lead |
| HLK-20M05 VO− | PSU output bus GND / terminal block | 18 AWG black | |
| PSU 5V bus | D1 Mini **5V** pin | 22 AWG red | Powers D1 Mini via VIN; WLED disables ESP deep-sleep |
| PSU GND bus | D1 Mini **GND** pin | 22 AWG black | Common GND with strip |
| PSU 5V bus | SK6812 strip VCC — **injection point 1** (LED 0, start) | 20 AWG red | 1.5 m run → 0.16 V drop at 1.6A |
| PSU GND bus | SK6812 strip GND — injection point 1 | 20 AWG black | |
| PSU 5V bus | SK6812 strip VCC — **injection point 2** (LED 90, midpoint) | 20 AWG red | ← critical; prevents far-end sag |
| PSU GND bus | SK6812 strip GND — injection point 2 | 20 AWG black | |
| PSU 5V bus | 74AHCT125 Vcc pin (pin 14) | 22 AWG red | Level shifter supply |
| PSU GND bus | 74AHCT125 GND pin (pin 7) | 22 AWG black | |

### AC Mains

| From | To | Notes |
|---|----|---|
| Schuko plug → L (brown) | HLK-20M05 **AC/L** | Use 0.75 mm² H05VV-F 3G; heat-shrink all joints |
| Schuko plug → N (blue) | HLK-20M05 **AC/N** | |
| Schuko plug → PE (yellow/green) | Enclosure screw terminal or metal body if used | Connect PE even if enclosure is plastic — future-proof |

> ⚠️ **Mains safety:** All mains wiring must be terminated with heat-shrink or appropriate
> terminals before closing the enclosure. Verify no bare conductors are exposed near low-voltage
> circuits inside the box.

### Data Signal Path

| From | To | Wire | Notes |
|---|----|---|---|
| D1 Mini GPIO2 (D4) | 330 Ω resistor in-line | 26 AWG | Keep short (< 5 cm) |
| 330 Ω output | 74AHCT125 **A1** (pin 2) | 26 AWG | Gate 1 input |
| 74AHCT125 **~OE1** (pin 1) | GND | — | Active-LOW enable; tie LOW to permanently enable gate 1 |
| 74AHCT125 **Y1** (pin 3) | JST SM 3-pin female "DATA" pin | 26 AWG | 5V output → strip data in |
| JST SM female "VCC" | 5V bus (via short bridge) | 22 AWG red | Convenience power at connector |
| JST SM female "GND" | GND bus | 22 AWG black | |

### LED Strip Header (SK6812)

| LED Strip Solder Pad | Connects To | Notes |
|---|---|---|
| +5V (injection 1) | PSU 5V bus | At strip start (LED 0) |
| GND (injection 1) | PSU GND bus | |
| DATA IN | JST SM "DATA" wire | From level shifter Y1 output |
| +5V (injection 2) | PSU 5V bus | At strip midpoint (LED 90) — solder to back of strip at ~1.5 m mark |
| GND (injection 2) | PSU GND bus | |

---

## 74AHCT125 DIP-14 Pinout (Gate 1 used)

```
       ┌──── USB notch ────┐
~OE1 1 │·                 │ 14  Vcc (5V)
   A1 2 │                 │ 13  ~OE4
   Y1 3 │   74AHCT125     │ 12  A4
~OE2 4 │                 │ 11  Y4
   A2 5 │                 │ 10  ~OE3
   Y2 6 │                 │  9  A3
  GND 7 │·                │  8  Y3
       └─────────────────┘
```

> Use only Gate 1 (pins 1–3); tie ~OE2, ~OE3, ~OE4 (pins 4, 10, 13) HIGH to disable unused gates.
> Leave A2, A3, A4 (pins 5, 9, 12) floating (pulled HIGH internally when OE disabled).

---

## Wiring Diagram

See `docs/wiring-physical.svg` (generated by `python tools/gen_diagrams.py curtaincinemalights --type wiring`).

---

## WLED LED Output Summary

| WLED Output | GPIO | Strip Type | LED Count | Segment 0 (Left Panel) | Segment 1 (Right Panel) |
|---|---|---|---|---|---|
| Output 0 | GPIO2 (D4) | SK6812 RGBW (type 30) | 180 (adjust to 60×width_m) | LEDs 0–89, `rev=true` (center-fill → left) | LEDs 90–179, `rev=false` (center-fill → right) |

**Color order:** GRBW (order=6) — mandatory for SK6812 strips with 4-pin white channel.

**Mid-inject at LED 90:** Does not require separate data signal — it is a power-only injection.
Solder a wire from PSU 5V/GND directly to the 5V/GND pads at the midpoint of the strip.

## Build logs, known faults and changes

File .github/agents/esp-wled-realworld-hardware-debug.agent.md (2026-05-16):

---
name: ESP/WLED Realworld Hardware Debug
description: >
  Step-by-step real-world hardware debugging assistant for WLED projects.
  Use when a physical ESP32/ESP8266 + LED build is not working and the user
  does not yet know whether the problem is wiring, power, firmware config,
  component compatibility, Home Assistant integration, or a mismatch between
  the real build and the documented project definition.
  Triggers: hardware debug, real world debug, wiring issue, leds not working,
  flicker, wrong colors, won't boot, no wifi, no ha discovery, power issue,
  signal issue, troubleshoot setup.
argument-hint: "project name, failing behavior, or 'something isn't working'"
tools:
  - read
  - search
  - edit
  - terminal
  - vscode/askQuestion
handoffs:
  - label: Update Project Definitions
    agent: ESP/WLED Project Reviewer
    prompt: Update the affected project definitions, docs, and configuration references based on the validated real-world hardware delta identified during debugging. Keep the project files aligned with the actual build and clearly document supported substitutions or constraints.
    send: false
---

# ESP/WLED Realworld Hardware Debug

You debug real physical WLED builds where the user knows something is wrong but does not yet know where or why.

Your job is to:
1. narrow the fault by asking focused step-by-step questions,
2. compare the user's real setup against the documented project definition,
3. decide whether the current hardware combination could work at all,
4. guide the user through the next concrete diagnostic or repair step,
5. summarize the delta between the documented project and the actual build.

Use the VS Code ask-question tool whenever the input can be collected as a short choice, checklist, or short freeform answer. Keep options concrete and keep freeform input enabled. If the required input does not fit well into ask-question flow, use a normal user message.

## Debugging Mode

Treat this as guided triage, not as a broad review.

- Ask only the next most useful question or the smallest useful batch of questions.
- Prefer questions that distinguish between likely causes.
- Do not overwhelm the user with theory up front.
- Move from simple physical facts to higher-level software/integration causes.
- If the user does not know an answer, ask for an observable symptom, photo-worthy detail, label text, measurement, or result of a simple check instead.

## Step 1 — Identify Scope And Symptom

If the project is not explicit, use ask-question first to determine:
- which project or build this is
- whether it follows an existing project in this repo or is a variation
- the main failure class

Offer symptom options such as:
- no power / no boot
- LEDs stay dark
- LEDs flicker or behave randomly
- wrong colors / wrong white channel
- only part of the strip works
- device boots but Wi-Fi / WLED does not work
- WLED works but Home Assistant does not
- enclosure / connector / physical assembly issue
- something else

## Step 2 — Read The Expected Definition

Once the target project is known, read the minimum relevant project files before continuing:
- `specs.md`
- `hardware/bom/bom.md`
- `hardware/wiring/WIRING.md`
- `firmware/cfg.json`
- `firmware/platformio_override.ini` when build-time config may matter
- relevant `homeassistant/` files when the issue is discovery or automation related
- `tools/parts-register/parts.json` for controller, strip, PSU, level shifter, connectors, and substituted parts

Use those files as the expected definition, not as proof that the real build matches them.

## Step 3 — Capture The Real Build Delta

Use ask-question where possible to capture the real hardware setup.

Collect at least these facts:
- actual controller board used
- actual LED strip type, voltage, and approximate length / LED count
- actual PSU or power source
- whether a level shifter is present and which part it is
- actual GPIO used for data
- whether common GND is wired
- whether power injection is used and where
- whether any alternative or extra parts were added
- whether the device is flashed and roughly which WLED target/version is running
- what exactly happens when the user tests it

When useful, ask for simple measurable checks:
- 5 V or 3.3 V present where expected
- LEDs react to a boot pattern or stay fully dark
- device creates an AP or responds on USB serial
- first LED behaves differently from later LEDs

## Step 4 — Check Whether The Setup Could Work

Do not assume the user's substituted parts are wrong just because they differ from the docs.

Review the real build against the documented design and classify each difference as one of:
- expected match
- acceptable substitution
- acceptable but needs config/doc updates
- risky / marginal
- unlikely to work without redesign or rewiring

Typical checks:
- board logic voltage vs LED data voltage requirements
- boot-strapping pins and whether the chosen GPIO can boot reliably
- PSU voltage, current headroom, and power injection sufficiency
- LED protocol, color order, and WLED chipset selection
- connector current limits vs expected draw
- whether enclosure-driven constraints changed routing, grounding, or heat behavior
- whether HA expectations depend on firmware discovery and segment naming that the real build does not have

## Step 5 — Debug In The Right Order

Guide the user through the next step in this order unless the evidence clearly points elsewhere:

1. **Power path**
   - PSU/output voltage present
   - polarity correct
   - common GND present
   - current headroom plausible

2. **Boot and controller state**
   - board powers up
   - no boot-pin conflict
   - WLED target matches the actual board family

3. **Data path**
   - correct GPIO
   - resistor and level shifter placement
   - DIN connected to the correct strip end
   - data run length and noise risk

4. **LED configuration**
   - chipset type
   - color order
   - LED count / segment definition
   - current limiter expectations

5. **Integration layer**
   - Wi-Fi join / AP mode
   - mDNS / Home Assistant discovery
   - segment names and entity IDs
   - automations or effect instances

Only move to the next layer after the current one is either validated or ruled out.

## Step 6 — Output Style During Debugging

After each meaningful input round, provide:
- the most likely current fault area
- the next concrete check or fix
- why that step is next

Keep each step small enough that the user can perform it and report back.

## Step 7 — Final Debug Summary

When you have enough information, summarize in four parts:

### 1. Likely Root Cause

State the most likely root cause or the narrowest remaining fault candidates.

### 2. Can The User's Setup Work?

State whether the actual setup:
- should work as-is,
- should work after config or wiring fixes,
- is marginal but salvageable,
- or is fundamentally mismatched.

### 3. Delta To Project Definitions

Present a compact delta table:

| Area | Project definition | Actual setup | Impact |
|---|---|---|---|

Include only meaningful differences.

### 4. Next Fix Steps

List the next concrete steps in order, starting with the smallest decisive action.

If the delta is now well understood and the project docs should be updated, offer the **Update Project Definitions** handoff.

## Collaboration Rules

- Prefer ask-question over open-ended chat whenever the input can be structured.
- If the user is unsure, ask for the simplest observable fact rather than asking them to interpret electronics theory.
- Do not ask for secrets such as Wi-Fi passwords through ask-question.
- When the user uses alternative parts, validate compatibility before calling them wrong.
- Check wiring, grounding, level shifting, voltage, current, GPIO choice, and config assumptions before blaming Home Assistant.

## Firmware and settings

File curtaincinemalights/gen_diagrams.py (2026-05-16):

#!/usr/bin/env python
"""
gen_diagrams.py — curtaincinemalights project diagram generator.

Generates all diagram types for the curtaincinemalights project and saves them
to curtaincinemalights/docs/.

Usage
-----
    # From repo root:
    python curtaincinemalights/gen_diagrams.py [--type all|schematic|blocks|concept|wiring]

    # Or use the shared CLI runner:
    python tools/gen_diagrams.py curtaincinemalights [--type all|schematic|blocks|concept|wiring]
"""

from __future__ import annotations
import argparse
import os
import sys

# ── Bootstrap: resolve repo root and add tools/ to path ──────────────────────
HERE     = os.path.dirname(os.path.abspath(__file__))
REPO_DIR = os.path.dirname(HERE)
TOOLS    = os.path.join(REPO_DIR, "tools")
DOCS     = os.path.join(HERE, "docs")

sys.path.insert(0, TOOLS)

from diagram_gen import blocks, concept, schematic, wiring  # noqa: E402
from gen_diagrams_config import DIAGRAM_CONFIG as CFG        # noqa: E402


def run_all(types: list[str]) -> None:
    os.makedirs(DOCS, exist_ok=True)

    if "schematic" in types:
        print("[schematic]")
        schematic.draw_level_shifter_circuit(
            os.path.join(DOCS, "schematic-level-shifter.png"))
        schematic.draw_power_circuit(
            os.path.join(DOCS, "schematic-power.png"))

    if "blocks" in types:
        print("[blocks]")
        blocks.draw_system_blocks(CFG,
            os.path.join(DOCS, "concept-system.png"))

    if "concept" in types:
        print("[concept]")
        concept.draw_side_view(
            {"title": "CURTAINCINEMALIGHTS  –  Side View  (not to scale)",
             "wood_label": "ALUM. TRACK"},
            os.path.join(DOCS, "concept-side-view.png"))
        concept.draw_top_view(
            {"title": "CURTAINCINEMALIGHTS  –  Top-Down Floor Plan",
             "lamps": CFG["lamps"],
             "box_pos": CFG["box_pos"]},
            os.path.join(DOCS, "concept-top-view.png"))

    if "wiring" in types:
        print("[wiring]")
        wiring.draw_physical_wiring(
            CFG, os.path.join(DOCS, "wiring-physical"))


def main():
    parser = argparse.ArgumentParser(
        description="Generate diagrams for the curtaincinemalights project.")
    parser.add_argument("--type", default="all",
                        choices=["all", "schematic", "blocks", "concept", "wiring"],
                        help="Diagram type to generate (default: all)")
    args = parser.parse_args()

    if args.type == "all":
        types = ["schematic", "blocks", "concept", "wiring"]
    else:
        types = [args.type]

    print(f"\n→ Generating curtaincinemalights diagrams: {', '.join(types)}\n")
    run_all(types)
    print("\n✓ Done — see curtaincinemalights/docs/\n")


if __name__ == "__main__":
    main()

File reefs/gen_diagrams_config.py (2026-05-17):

"""
gen_diagrams_config.py — Reefs project diagram configuration.

Imported automatically by tools/gen_diagrams.py.
"""

from __future__ import annotations

DIAGRAM_CONFIG: dict = {
    "project":    "reefs",
    "title":      "REEFS  –  ESP8266 WLED Ambient Lighting",

    # Power / control hardware
    "psu":        "Honeywell PSU\n5V / 10A",
    "controller": "ESP8266 NodeMCU V3\nWLED v0.15",
    "shifter":    "74AHCT125\n3.3 → 5V",
    "power_label": "5V / 10A PSU",

    # LED outputs
    "outputs": [
        {"name": "LAMP 1", "strip": "SK6812 GRBW\n60 LEDs · 1 m"},
        {"name": "LAMP 2", "strip": "SK6812 GRBW\n60 LEDs · 1 m"},
    ],

    # Smart-home integration
    "integration": "Home\nAssistant",

    # GPIO mapping for wiring diagram
    "gpio_map": [
        {"gpio": 14, "label": "LAMP 1 DATA (D5)", "color": "#43a047"},
        {"gpio": 12, "label": "LAMP 2 DATA (D6)", "color": "#26c6da"},
    ],

    # Concept top-view: lamp positions (cx = x along the wall)
    "lamps": [
        {"label": "LAMP 1", "cx": 3.0},
        {"label": "LAMP 2", "cx": 8.5},
    ],
    "box_pos": (9.5, 0.8),
    "wood_label": "DRIFTWOOD",
}

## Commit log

2026-05-16 feat(diagram_gen): add schematic and wiring diagram generation tools
    - Introduced `schematic.py` for generating electrical circuit schematics, including level shifter and power distribution circuits.
    - Added `wiring.py` for creating high-fidelity physical wiring diagrams with color-coded components and labels.
    - Implemented `gen_diagrams.py` as a CLI tool for generating various diagrams based on project configuration.
    - Created `style.py` for shared styles and color palettes across diagrams.
    - Added `requirements.txt` for necessary dependencies including `schemdraw`, `drawsvg`, and `matplotlib`.
2026-05-16 Add case-top image for mechanical enclosure design
    [CustomProjectEnclosureV1.7.8b.3mf]
2026-05-16 feat: update README and specs for improved clarity and detail; adjust platformio config for ESP32 environment
2026-05-16 feat: add enclosure generation instructions and skill for YAPP_Box; update models documentation
2026-05-16 feat: enhance enclosure generation documentation with detailed label specifications and positioning guidelines
2026-05-16 Refactor code structure for improved readability and maintainability
    [YAPPgenerator_v3.scad, reefs-automatedvariant-enclosure.scad, test-minimal.scad]
2026-05-16 feat: update .gitignore to include additional output files; add new STL files for enclosure base and lid
    [reefs-automatedvariant-base.stl, reefs-automatedvariant-enclosure.scad, reefs-automatedvariant-lid.stl]
2026-05-16 Remove obsolete test files and add automated variant specification and rendering script
    - Deleted `test-minimal-err.txt` and `test-minimal.scad` as they are no longer needed.
    - Added `reefs-automatedvariant-enclosure-spec.md` to document the specifications of the new enclosure variant.
    - Introduced `render_enclosure.ps1` script for automated rendering of STL files and preview images for the enclosure.
    [reefs-automatedvariant-enclosure.scad, reefs-automatedvariant-lid.stl, test-minimal.scad]
2026-05-16 feat: update enclosure generation documentation with snap-on lid specifications and standoff guidelines
2026-05-16 feat: update enclosure specifications and documentation for snap-on lid integration
2026-05-16 Add new PNG image for automated variant lid top in mechanical enclosure
    [reefs-automatedvariant-base.stl, reefs-automatedvariant-lid.stl]
2026-05-16 feat: add detailed documentation for automated variant enclosure with specifications and regeneration instructions
2026-05-16 feat: update copilot instructions and specs for YAPP_Box enclosure generation, enhance documentation for mechanical constraints and Home Assistant integration
    [CustomProjectEnclosureV1.7.8b.3mf]
2026-05-16 feat: enhance documentation for enclosure generation, including new commands and output details
2026-05-16 feat: remove cached Python bytecode files from diagram generation module
    [reefs-automatedvariant-enclosure.scad]
2026-05-16 refactor: update specifications and wiring diagrams for control box and power distribution
    - Revised component specifications in specs.md, including connector types and quantities.
    - Updated control box internal wiring details to reflect changes in power distribution and strain relief methods.
    - Changed IEC C14 inlet references to Schuko lead in schematic.py, aligning with updated hardware design.
    - Enhanced clarity in documentation regarding cable management and strain relief for mains and lamp connections.
    [reefs-automatedvariant-base.stl, reefs-automatedvariant-enclosure.scad, reefs-automatedvariant-lid.stl]
2026-05-16 feat: add parts dimensions register and BOM for curtaincinemalights project
2026-05-16 feat: Add upload_spiffs.py script for uploading firmware files to WLED devices over WiFi
2026-05-16 feat: Add new components to parts register including ESP32-DevKitC V4 and ESP32-WROOM-32E module
2026-05-16 feat: Update resistor specifications in BOM for Reefs and Curtain Cinema Lights to clarify part number and value
2026-05-16 feat: Update README and BOM for curtaincinemalights and reefs projects to enhance clarity and detail on components and setup
2026-05-17 Refactor project to switch from ESP32 to ESP8266 NodeMCU V3
    - Updated wiring documentation to reflect NodeMCU V3 pin assignments and connections.
    - Revised Home Assistant README and package.yaml to specify NodeMCU V3 and WLED v0.15.
    - Adjusted enclosure models and specifications to accommodate NodeMCU V3 geometry.
    - Modified specs.md to clarify the use of NodeMCU V3 and its implications for builders.
    - Enhanced parts register with details for ESP8266 NodeMCU V3, including pinout and mounting notes.
    [reefs-automatedvariant-enclosure.scad]

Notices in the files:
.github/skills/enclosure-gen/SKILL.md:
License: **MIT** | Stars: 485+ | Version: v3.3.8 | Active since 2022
